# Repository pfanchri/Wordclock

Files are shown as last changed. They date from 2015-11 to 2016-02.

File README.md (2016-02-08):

# Wordclock
Mein Projekt für die DIY Vorlesung an der FAU Erlangen

Ziel des Projektes war es eine Wordclock zu erstellen, die kleiner als alle gewöhnlichen Wordclocks ist und als Tischuhr 
fungieren soll. Als Vorbild diente das Modell von qlocktwo. 

Die Uhr kann nicht nur die Zeit anzeigen, sonder speichert auch den Wochentag, dieser wird in der aktuellen Softwareversion 
aber noch nicht angezeigt. Weitere Verbesserungen sind etwa ein Batteriebuffer und weitere Möglichkeiten für die Frontplatte.

Bei der Vorlesung DIY gab es auch ein Wiki für alle Projekte. Das Wordlcock-Projekt ist unter folgendem Link zu finden: 
http://faui7pi.informatik.uni-erlangen.de/mediawiki/index.php/Wordclock

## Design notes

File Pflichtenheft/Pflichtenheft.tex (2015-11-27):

\documentclass[11pt,a4paper,ngerman]{article}
 \usepackage[utf8]{inputenc} %UTF8 input file
\usepackage[T1]{fontenc} 
\usepackage[ngerman]{babel} %Umlaute,Silbentrennung 
%\usepackage{textcomp} % Zusatzpaket textcomp - damit werden einige Sonderzeichen, insbesondere das Euro-Symbolaktiviert. Änderungen siehe Beispieltext.
\usepackage{hyperref} %URLs können eingefügt werden
\usepackage{booktabs} %Tabellen 
\usepackage{pdflscape} % Paket lscape (oder für pdflatex das Paket pdflscape)
\usepackage{cite} %zum verwenden von BibTex
\date{\today}
\author{Christof Pfannenmüller}
\title{DIY: Pflichtenheft Wordclock}
\begin{document}
\maketitle 
\tableofcontents 
\newpage
\section{Über dieses Dokument}
Um die Entwicklung meiner Wordclock etwas zu ordnen möchte in diesem Dokument das Erstellen und die Aufgaben dabei etwas sortiert aufführen. Das gesamte Projekt wurde auf Github\cite{githubWC} und im Wiki der Vorlesung DIY: Personal Fabrication\cite{wikiWC}  dokumentiert und 
\section{Lastenheft}
{\large Hier habe ich das bereits erstellte Lastenheft eingefügt.  }\\
Lastenheft Wordclock:\\
\\ 
Weckfunktion: vorsehen einer Weckfunktion mit Ton und Snoozefunktion\\
\\
Taster zum Ausschalten der Alarmfunktion, Snozze und zum Einstellen der Uhrzeit\\
\\
Helligkeitsanpassung: über Sensor oder über Software und Schalter an der Rückseite\\
\\
Sekundenanzeige\\
\\
Datum und Wochentag anzeigen\\ 
\\
Funkanbindung zum automatischen Uhrzeit einstellen\\
\\
Stromreserve: Uhrzeit bleibt bestehen bei Stromausfall  evtl. auch Anzeige und Weckfunktion ohne Strom\\ 
\\
Ausschalter: kleinen Ausschalter an der Unterseite zum gänzlichen Ausschalten (Uhrzeit läuft über Batterie weiter\\
\\
USB Versorgung\\
\\
24h Modus: Wecker klingelt nur alle 24h nicht alle 12 und die Weckfunktion kann somit angelassene werden\\
\\
verschiedene Frontcovers möglich: in verschiedenen Sprachen, dafür verschiedene Möglichkeiten der LED Ansteuerung\\
\\
Stabiles Gehäuse, schön klein\\
\\
Standfuß (standsicher)\\
Weiter Ideen für später: \par
Beschriftung auf der Rückseite, evtl  noch Schriftzug Wordclock oder CC Zeichen (oder beides)

\begin{landscape}
\section{Pflichtenheft}
\begin{tabular}[]{p{2cm}p{2cm}p{10cm}p{2cm}p{2cm}}
	\toprule
	Aufgabe & Beschreibung & Wie umzusetzen  & bis & Status \\
	\midrule
	Weckfunktion & & Lautsprecher/Tongeber, Taster für Snoozefunktion & & \\
	Weckzeitpunkt einstellen & & mehrere Taster, mind. 2 (Mode, Up) besser 3 (Mode, Up, Down); Mode kurz drücken zeigt aktuellen Weckzeitpunkt an, lange drücken um in Modus Weckzeitpunkt kommen; Unterscheidungsmöglichkeit AM/PM notwendig \\
	Uhrzeit einstellen & & Taster Up (Down) von Weckzeitpunkt verwenden; eigenen Taster um in Modus Uhrzeit einstellen zu kommen, oder mehrere Taster gleichzeitig drücken; wen gewünscht Möglichkeit für Datum einstellen (daraus Wochentag berechnen) \\
	Anpassung der Helligkeit & Anzeige heller bei heller Umgebung & Sensor für Umgebungslicht mit passender Elektronik; Loch in Gehäuse; Regelung der LEDs durch PWM (kompliziert) evtl. Controller oder durch IC (dafür ADU notwendig) \\
	Sekunden-Anzeige & zeigt Sekunden auf der Matrix an & Knopf durch den in Sekundenmodus gewechselt wird; Anzeige der Sekunden auf der Matrix, evtl. nicht bei jedem Frontcover möglich (muss deaktiviert werden können); wo Sekunden gespeichert? \\
	Anzeige Datum und Wochentag & & Wie anzeigen? Wo gespeichert? evtl. nicht bei jedem Frontcover möglich (muss deaktiviert werden können) \\
	Funkuhr & Einstellen der Uhrzeit nach Atomuhr & DCF77 Verbindung um Uhrzeit automatisch zu finden und einzustellen.\\
	Stromreserve & & Uhrzeit bleibt erhalten und Wecker klingelt trotz fehlendem Strom; Anzeige trotzdem aktiv würde Speicherdauer verkürzen ( Anzeige nur im Moment des Weckens oder gar nicht)\\
\end{tabular}
	%Seitenumbruch in Tabelle (besser lösen?)
	\newpage
	\begin{tabular}[]{p{2cm}p{2cm}p{10cm}p{2cm}p{2cm}}
	\toprule
	Aufgabe & Beschreibung & Wie umzusetzen  & bis & Status \\
	\midrule
	Uhr komplett ausschalten && Uhr über kleinen Schalter komplett ausschalten; Taster an Unterseite oder hinter Frontcover verstecken (bleibt Uhrzeit und Einstellungen erhalten?)\\
	Stromversorgung && Uhr wird über USB-Netzteil versorgt; USB Buchse verbauen \\
	24h Modus && Wecker klingelt nur um 6:00am, Uhr zeigt aber gleiches an für am/pm\\
	verschiedene Frontcovers & & Frontcover auswechselbar; verschiedene Farben möglich (evtl. bei Farben aktuelle Uhrzeit unterschiedlich gut erkennbar); verschiedene Sprachen (Umschalten der Matrix auf andere Sprache muss möglich sein, dafür Taster etc.)\\
	Stabiles Gehäuse & & Gehäuse mit sicherem Stand; stabil um nicht kaputt zu gehen (herunterfallen); vorerst aus Holz später Alu etc (aus einem Teil)\\
	Programmieren der Uhr && Schnittstelle um Uhr auch später noch programmieren zu können; an Unterseite oder hinter Frontplatte verstecken\\
	LED Helligkeit && LEDs passen Helligkeit an Umgebungslicht an; LEDs nachts austom. aus (24h Zeiteingabe (8-20Uhr: hell, 20-8Uhr: dunkel))

\end{tabular}
\end{landscape}

\section{Umsetzung}
	Der Aufbau der Wordclock soll von vorne nach hinten und von außen nach innen erfolgen:\\
	Ich möchte zuerst die Größe der Frontplatte festlegen, dann ein entsprechendes CAD Modell erstellen und die Schaltung intern auf einer einzelnen Platine unterbringen, da dies den Verdrahtungsaufwand verringert. Das Gehäuse möchte ich zuerst nur aus Holz bauen bzw. am 3D-Drucker ausdrucken und dies aber so, dass es möglich ist zu späteren Zeitpunkten ein Gehäuse aus Aluminium oder Holz zu fräsen. \par
	Ich möchte nicht nur selbstgestaltete Frontplatten verwenden können, sonder auch solche des Herstellers qlocktwo. Dadurch bin ich zwar an die genaue Größe der Frontplatte gebunden, kann aber auf die vielen verschiedenen Sprachen und Farben des Herstellers zugreifen. \par

\subsection{Frontplatte}
Für die Frontplatte möchte ich mehrere Sprachen machen, auf jeden Fall Deutsch und Englisch so wie nach Möglichkeit ein Dialekt (vorzugsweise Fränkisch)\\
Auflistung aller Sprachen TODO!!
Im Internet habe ich eine gute Lösung zu Befestigung gefunden: Die Frontplatte ist mit vier Magneten beklebt und  wird von vier weiteren Magneten an der Zwischenplatte gehalten und kann also ausgetauscht werden. Verbesserung: nur vier Magneten an Zwischenplatte, dafür Metall an Frontplatte
\subsection{Gehäuse}
stabil
Frontmaße identisch mit der der Frontplatte, Tiefe möglichst gering 
Möglichkeit Platine, Zwischenplatte und Frontplatte zu befestigen
Anschluss für USB und Löcher für Taster
\subsection{Zwischenplatte}
Die Zwischenplatte dient dazu, dass jede LED nur das für sie vorgesehene Zeichen auf der Frontplatte erleuchtet. Auch muss die Frontplatte durch die Zwischenplatte gehalten werden. Dafür möchte ich, wie in den meisten Wordclock-Ideen Magnete verwenden, da somit ein leichtes Auswechseln der Frontplatte möglich ist. Auch eine Verbindung zum Gehäuse muss durch die Frontplatte realisiert werden. Da die gesamte Schaltung nach Möglichkeit auf einer Platine realisiert werden soll werden wohl auch andere Bauelemente außer den LEDs auf der Vorderseite platziert werden müssen. Dafür ist es notwendig Aussparungen vorzusehen.  
Da es bei manchen Frontplatten Zeichen gibt, die größer sind und somit von mehreren LEDs angeleuchtet werden sollten, sollten die Zwischenstege der einzelnen LEDs möglichst dünn sein, um nicht einen Schatten zu werfen. Sie dürfen aber auch nicht zu dünn und somit evtl. durchscheinend sein. Möglichkeit: Kegelförmig zulaufend, ähnlich dem Abstrahlkegel der LEDs (wie zu Drucken/herzustellen)
Die Dicke der Zwischenplatte ergibt sich aus dem Abstrahlwinkel der LEDs, dieser ist bei fasst allen LEDs die für mich in Frage kamen 120 Grad Für die Dicke der Zwischenplatte ergibt sich damit: $d = \frac{0,5 * Buchstabendurchmesser}{tan60^\circ } $ 
\subsection{Platine}
\subsubsection{LEDs}
Ich möchte keine farbige Wordclock und benötige deshalb keine RGB-LEDs. \\
\begin{itemize}
\item klein
\item weiß (neutralweiß) 
\item hell
\item Abstrahlwinkel möglichst groß, damit Platine näher an Frontplatte kann insg. Uhr dünner wird
\item kostengünstig
\item möglichst geringer Stromverbrauch
\end{itemize}
Eierlegende Wollmilchsau, also Kompromiss finden\\
Suche im Reichelt-Katalog
%Beziehungen Lichtstrom lichtfarbe abstahlwinkel  -------------------------------------------
Eine weitere Möglichkeit für die LEDs sind adressierbare LEDs, so wurde eine Steuerung über Schieberegister entfallen (Tipp von Jürgen)
\subsubsection{LED-Verdrahtung}
Für die LEDs stellt sich die Frage nach einer Matrix- oder Einzelansteuerung. Die folgende Tabelle soll die Vor- und Nachteile der beiden Methoden darstellen:\\
\begin{tabular}[]{p{3cm}p{3cm}p{3cm}p{3cm}}
	\toprule
	Vorteile Matrix & Nachteile Matrix & Vorteile Einzelansteuerung  & Nachteile Einzelansteuerung\\
	\midrule
	stromsparend & immer nur eine LED an; nicht so hell & Alle LEDs an; hell & Stromverbrauch größer\\
	&Controller muss öfter aufwachen & lange Sleepzeiten des IC\\
	Dimmen über IC gleich integrierbar & Dimmen über abändern der Zeiträume die einzelne LED leuchtet & gemeinsammes Dimmen über Anode/Kathode aller LEDs & LEDs nicht unterschiedlich dimmbar
\end{tabular}
Der Verdrahtungsaufwand der beiden Methoden ist nahezu identisch, da ich die Schaltung auf einer einzige Platine unterbringen will.\\
Beim betrachten der Ansteuerzeiten für eine Einzelansteuerung fällt mir auf:\\
Gesamtzeit für einen Durchlauf aller LEDs muss kleiner als $1\over30$ einer Sekunde sein (damit kein Flackern sichtbar; vgl. Film). Also Zeit für eine LED bei 100\% Helligkeit: $\frac{1}{10*11*30} = \frac{1}{3300}=0,303ms$.Jetzt würde sich die Zeit durch Dimmen noch weiter verkürzen, was sehr kompliziert würde. Deswegen ist eine Einzelansteuerung und Dimmen aller LEDs über verbundene Anode/Kathode meine Meinung nach einfacher.\\
Ansteuern der LEDs über Schieberegister (kaskadierbar, benötigt also nur wenige Anschlüsse des IC) oder über LED-Treiber (eingebaute Möglischkeit des Dimmens; unabhänig von einander dimmbar; Ansteuerung über I2C)

\subsubsection{Ansteuerung}
Nach Möglichkeit SMD Bauteile verwenden, damit die Ansteuerung gut auf der Platine unterzubringen ist, trotzdem groß genug, damit es gut lötbar ist. So klein wie möglich so groß wie nötig.
\paragraph{Uhrzeit}

Viele Wordclocks verwenden ein RTC (Real Time Clock), beim Suchen habe ich eine gefunden, welche die Möglichkeit hat einen Alarm als Interrupt auszugeben(\url{http://www.reichelt.de/Real-Time-Clock/DS-1337/3/index.html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}), somit kann der Mikrocontroller die ganze Zeit im Schlafmodus sein und spart Strom. Zu Beginn kann man auch eine if-Abfrage verwenden, jedes mal, wenn die Uhrzeit geändert wird ob nun ein Alarm ausgegeben werden muss. Möglicherweise muss auch das Umschalten der LEDs immer auf einen Interrupt der RTC geschehen (wie weiß der Mikrocontroller sonst, dass eine Minute vorbei ist?)

\paragraph{Dimmen}
Helligkeit über PWM Controller anpassen wie?
LDR für Helligkeitsanpassung? evtl. kombinieren in gemeinsamer Ansteuerung, sodass IC auf volle Leistung aussteuern kann
Da sehr aufwändig und erstmal nicht so interessant auf unbestimmte Zeit verschoben
\paragraph{Taster und Schalter}
Es werden mehrere Taster gebraucht. Es werden vier Taster für die Uhr benötigt um: Ein Modustaster, ein Up- sowie ein Down-Taster und ein noch ein weiterer Taster um den Alarm an und auszuschalten. Die Snooze-Funktion sollte einen einen eigenen Taster bekommen, der größer ist oder leichter erreicht wird. Somit kann sichergestellt werden, dass ein schlaftrunkener Benutzer nicht die Weckfunktion komplett ausschaltet, statt den Snooze-Taster zu drücken.

Idee: alle Taster an Rückseite gehen auf einen interruptanschluss und jeder zusätzlich auf einen anderen Digitalanschluss, damit Interrupspins sparen; muss über Optokopler ??
\subsubsection{Stromversorgung}
USB evtl. Lightningstecker als Anschluss       
Handyakku?USB Puffern\cite{RTCDatenblatt}

\bibliography{Wordclock-Bibliographie} %hier steht der Name der Bib-Datei
\bibliographystyle{acm}  %Citationsstil "ieeetran" geht nicht; warum?

\end{document}

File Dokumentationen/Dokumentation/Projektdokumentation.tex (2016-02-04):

\documentclass[12pt,journal,compsoc]{IEEEtran}
\usepackage[utf8]{inputenc}
\usepackage[ngerman]{babel}
%\usepackage{tikz, tikzscale, adjustbox,enumerate, tabularx, multirow, booktabs}
\usepackage{graphicx, tabularx, booktabs, enumerate, multirow}
\usepackage{cite, textcomp}
\usepackage{hyperref}

\usepackage{listings}
\lstset{
  language=C,
  basicstyle=\ttfamily\small,
  keywordstyle=\color{blue}\ttfamily,
  stringstyle=\color{red}\ttfamily,
  commentstyle=\color{green}\ttfamily\normalsize,
  breakatwhitespace=false,
  breaklines=true
}

\makeatletter
{\obeylines\gdef\bt@eol{^^M}}
\newenvironment{breakabletexttt}
  {\ttfamily\hfuzz=0.4em
   \list{}{\leftmargin=2em
           \itemindent=-\leftmargin
           \listparindent=-\leftmargin
           \parsep=0pt}
   \item\relax\obeylines\obeyspaces\expandafter\breakable@texttt\@gobble}
  {\endlist}
\def\breakable@texttt{\futurelet\@let@token\breakable@texttti}
\def\breakable@texttti#1{%
  \ifx\@let@token\end
  \expandafter\end
  \else
    \expandafter\ifx\bt@eol\@let@token
      \par
    \else
      \string#1\hskip1sp
    \fi
    \expandafter\breakable@texttt
  \fi}
\makeatother

\usepackage{tikz, tikzscale} % tiks für Zeichnungen

\usepackage[europeanresistors,europeaninductors,arrowmos]{circuitikz}
\usepackage{amsmath}

%\usepackage[siunitx]{circuitikz}
%\usepackage[ngerman]{varioref}% Definiert variable Referenzierungen
%\usetikzlibrary{dsp,chains}

\providecommand{\PSforPDF}[1]{#1}
\setcounter{secnumdepth}{1}

% NOTE: PDF hyperlink and bookmark features are not required in IEEE
%       papers and their use requires extra complexity and work.
% *** IF USING HYPERREF BE SURE AND CHANGE THE EXAMPLE PDF ***
% *** TITLE/SUBJECT/AUTHOR/KEYWORDS INFO BELOW!!           ***
\newcommand\MYhyperrefoptions{bookmarks=true,bookmarksnumbered=true,
pdfpagemode={UseOutlines},plainpages=false,pdfpagelabels=true,
colorlinks=true,linkcolor={black},citecolor={black},pagecolor={black},
urlcolor={black},

pdftitle={DIY Wordclock},
pdfsubject={Wordclock},
pdfauthor={Christof Pfannenmüller}}

% correct bad hyphenation here
%\hyphenation{op-tical net-works semi-conduc-tor}

\begin{document} %----------------------------------------------------------------------------Beginn des Dokuments
%
% paper title
% can use linebreaks \\ within to get better formatting as desired
\title{DIY Wordclock}

\author{Christof Pfannenmüller}% <-this % stops a space

  % for Computer Society papers, we must declare the abstract and index terms
  % PRIOR to the title within the \IEEEcompsoctitleabstractindextext IEEEtran
  % command as these need to go into the title area created by \maketitle.
%  \IEEEcompsoctitleabstractindextext{%
%  \begin{abstract}
  %\boldmath
  %The abstract goes here.
%  \end{abstract}
  % IEEEtran.cls defaults to using nonbold math in the Abstract.
  % This preserves the distinction between vectors and scalars. However,
  % if the journal you are submitting to favors bold math in the abstract,
  % then you can use LaTeX's standard command \boldmath at the very start
  % of the abstract to achieve this. Many IEEE journals frown on math
  % in the abstract anyway. In particular, the Computer Society does
  % not want either math or citations to appear in the abstract.

  % Note that keywords are not normally used for peerreview papers.
%  \begin{IEEEkeywords}
%  Computer Society, IEEEtran, journal, \LaTeX, paper, template.
%  \end{IEEEkeywords}}

% make the title area
\maketitle

% To allow for easy dual compilation without having to reenter the
% abstract/keywords data, the \IEEEcompsoctitleabstractindextext text will
% not be used in maketitle, but will appear (i.e., to be "transported")
% here as \IEEEdisplaynotcompsoctitleabstractindextext when compsoc mode
% is not selected <OR> if conference mode is selected - because compsoc
% conference papers position the abstract like regular (non-compsoc)
% papers do!
\IEEEdisplaynotcompsoctitleabstractindextext
% \IEEEdisplaynotcompsoctitleabstractindextext has no effect when using
% compsoc under a non-conference mode.

% For peer review papers, you can put extra information on the cover
% page as needed:
% \ifCLASSOPTIONpeerreview
% \begin{center} \bfseries EDICS Category: 3-BBND \end{center}
% \fi
%
% For peerreview papers, this IEEEtran command inserts a page break and
% creates the second title. It will be ignored for other modes.
%\IEEEpeerreviewmaketitle

%----------------------------------------------------------------------------------------------Beginn des  eigentlichen Textes

\section{Einführung}

\IEEEPARstart{W}{ordclocks} sind in der Bastler oder DIY-Szene weit verbreitet und bergen eine gewisse Faszination. Auch wenn es für solche Wordclocks schon eine Vielzahl an Bauanleitungen gibt, kann trotzdem beim Bau einer solchen viel über die Programmierung und die Steuerung durch Mikrocontroller gelernt werden.
Grundsätzlich sind alle Wordclocks sehr ähnlich aufgebaut. Fast immer wird eine Frontplatte mit passend angeordneten  Buchstaben verwendet, die durch eine Matrix an LEDs von hinten erleuchtet ist. Dadurch, dass nur die zur aktuellen Stunde passenden   Wörter leuchten, stechen diese aus den, auf den ersten Blick verwirrend angeordneten, Buchstaben der Frontplatte hervor. Wichtig bei einer Wordclock ist auch, dass jede LED nur den für sie vorgesehen Buchstaben der Frontplatte beleuchtet und nicht zu einem Teil auch die benachbarten Buchstaben. Dies würde den absetzenden Effekt des Hervorscheinens der Buchstaben von den dunkleren minimieren. Dafür wird meist eine sogenannte Zwischenplatte angebracht, die das Licht der LED abschirmt, damit sichergestellt werden kann, das kein Nachbarbuchstabe beleuchtet wird.
Wordclocks wurden bereits in vielen verschiedenen Sprachen erstellt, wobei  grundsätzlich jede Sprache möglich ist. Die einzige Vorgabe ist alle Wörter, die zum \glqq schreiben\grqq der Uhrzeit notwendig sind, auf der Frontplatte anzuordnen. Dabei ist jedoch wichtig, dass die Reihenfolge der Wörter so gewählt wird, das jede mögliche Uhrzeit auch dargestellt werden kann ohne ein Wort doppelt unterbringen zu müssen und trotzdem die Reihenfolge der Wörter dem Sprachgebrauch entspricht. In diesem Zusammenhang ist etwa die Darstellung der Zeit 15:45 interessant, denn je nach Wohnort wird diese in unterschiedlichem Wortlaut verwendet. Vor allem in Sachsen, Thüringen und Franken wird die Bezeichnung \glqq Dreiviertel vier\grqq verwendet, in Norddeutschland dagegen eher \glqq Viertel vor vier\grqq. Solche Feinheiten müssen also berücksichtigt werden, bei \glqq Viertel nach drei\grqq bzw. \glqq Viertel vier\grqq verhält es sich ähnlich.

\begin{figure}
	\centering
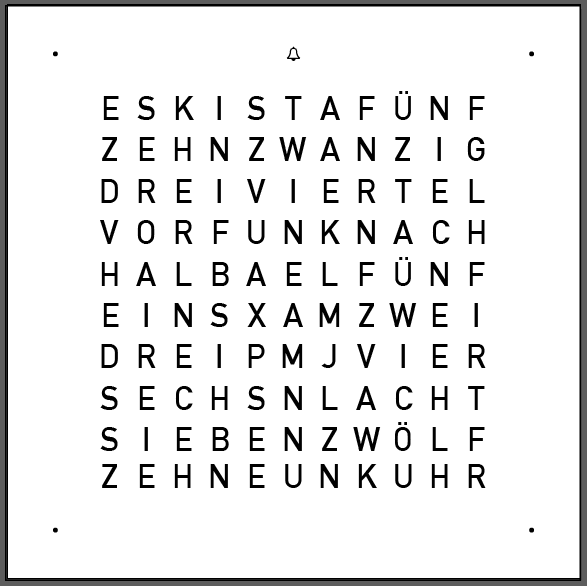
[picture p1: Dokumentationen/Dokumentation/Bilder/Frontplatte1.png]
	
	\caption{Die Frontplatte meiner Wordclock} 
	\label{fig:Frontplatte1}
\end{figure}

\section{Anforderungen}
Diese Wordclock sollte vor allem - im Gegensatz zu den meisten anderen - kleiner ausgelegt und nicht zum Aufhängen an der Wand gedacht sein, sondern als modulare kleine Tischuhr, die bei Einbau einer Alarmfunktion, auch als Wecker dienen kann.
Bei ersten Recherchen fand ich heraus, dass der Hersteller Qlocktwo mittlerweile eine solche Uhr in seinem Sortiment hat. Qlocktwo ist allem Anschein nach der einzige Hersteller von Wordclocks auf dem Europäischen Markt. Da der Hersteller auch Ersatzfrontplatten verkauft, entschied ich mich zuerst eine solche zu kaufen und eine eigene Frontplatte erst zum Schluss zu erstellen, wenn die Wordclock bereits funktionsfähig ist. Dadurch musste ich zwar die geplante Größe der Wordclock um ein paar Zentimeter auf 13,5cm Seitenlänge verkleinern, konnte mich aber erst einmal auf die Elektronik konzentrieren.
Um zunächst einen Überblick zu bekommen sammelte ich alle möglichen Projektideen und mögliche Umsetzungen in einem, mit Latex erstellten, Lasten- und Pflichtenheft. Dabei wurde auch die in Latex integrierte Bibliographieverwaltung verwendet um alle Quellen für Ideen zu archivieren. Zur Versionskontrolle wurde während des Projektes für alle Dateien Github eingesetzt um jeweils den aktuellen Stand zu protokollieren. Das fertige Github-Repository ist unter der \url{https://github.com/pfanchri/Wordclock} zu finden.

\section{Hardware}

\subsection{Eagle}
Für die Platine wird Eagle als PCB-Software zum Entwurf der Platine verwendet, da es kostenlos verwendet werden kann und die Platinenentwicklung im Fablab auf Eagle ausgerichtet ist. Eagle arbeitet nach dem Bibliotheks-Prinzip, das heißt es werden für jedes  Bauteil Daten über die Elektrischen Anschlüsse und über das Package, also über die Verpackung des Bauteils, benötigt. In Eagle können somit  zuerst der Schaltplan, also die elektrischen Verbindungen und Netze, erstellt werden. Diese werden in einem zweiten Schritt auf der Platine angeordnet und die Leiterbahnen geroutet. Hier kann leicht berücksichtigt werden, dass viele elektrische Bauteile in unterschiedlichen Packages zur Verfügung stehen. Die bei der Wordclock verwendeten Bauteile waren zumeist in den mit Eagle ausgelieferten Bibliotheken bereits enthalten. Die Bibliotheksdaten für die LEDs waren zwar nicht in den Standartbibliotheken enthalten, werden dafür aber von Adafruit, einem Händler für diese Bauteile, bereitgestellt. Im Layout wurden zuerst alle LEDs an die durch die Frontplatte vorgegebenen stellen platziert. Anschließend wurden die Taster angeordnet, sodass diese später optisch ansprechend platziert sind. Alle in der fertigen Wordclock nicht mehr sichtbaren Bauteile wurden als letztes platziert und mit Leiterbahnen versehen. Eagle konnte auch eingesetzt werden, um etwa eine Stückliste der verwendeten Teile auszugeben.
\begin{figure}
	\centering
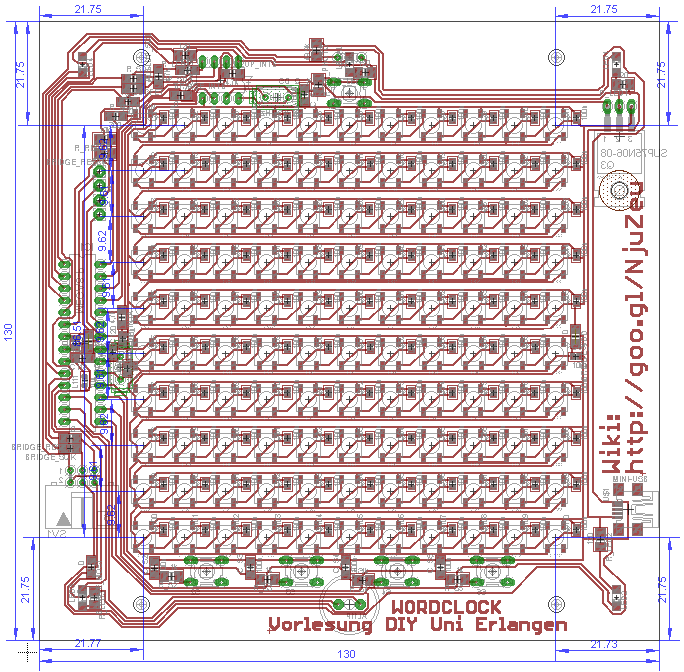
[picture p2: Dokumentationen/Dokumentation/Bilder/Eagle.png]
	
	\caption{Das Layout in Eagle} 
	\label{fig:EagleL}
\end{figure}

\subsection{Elektronik}
Das Ziel ist die Platine einlagig aufzubauen. Dies erhöht zwar den Aufwand für das Layout immens, dafür kann aber eine einlagige Platine verwendet werden, die wesentlich einfacher zu entwickeln ist, als eine zweilagige. Auch werden keine Durchkontaktierungen in der Platine benötigt, die im Fablab etwas aufwändiger sind. Da der Platz aber durch die Vorgabe der Frontplatte begrenzt ist, müssen auch kleine Bauteile verwendet werden, die etwas schwieriger zu löten sind.
Versorgt werden soll die Uhr mittels Strom aus einem USB-Ladegerät oder Computer damit kein besonderes Ladegerät notwenig ist. Dies legt die Versorgungsspannung auf 5 Volt fest. Als Stromanschluss wird eine kombinierte Micro-USB-Buchse, die für Stecker des Types A und B geeignet ist, verwendet. Die Uhr kann dadurch mit einem Ladekabel für Handys betrieben werden.
Die Hauptarbeit übernimmt dabei ein Prozessor der  Mega8-Reihe von Atmel, da dieser einfach zu programmieren und leicht verfügbar ist. Genau wird der Atmega168PA-PU verwendet, der den größten programmierbaren Flash seiner Baureihe zur Verfügung stellt. Da ein späterer Einbau einer Batteriepufferung möglich sein soll, verwenden wir hier die Pico-Power Ausführung des AVR, da diese weniger Strom im Schlafmodus verbraucht, was hierbei hilfreich sein kann. Als Baugröße verwende ich hierbei die PDIP  Ausführung . Da bei diesem Gehäuse die Pins nahe beieinander liegen, kann der AVR gut zwischen der LED-Matrix und dem Rand der Platine eingebaut werden. Hierfür wäre eine andere Gehäuseform zu groß. Zum Programmieren des AVR wird eine Standart ISP-Stecker verwendet, da bereits damit zu rechen ist, das die Software mehrfach aufgespielt werden muss, bis diese reibungslos läuft. 
Die LED-Matrix zum Anzeigen der einzelnen Buchstaben der Uhr wird durch 110 WS2812B LEDs aufgebaut. Diese LEDs haben den Vorteil, dass sie eine eigene Datenleitung haben und der Mikrocontroller daher nur einen Pin bereitstellen muss, um alle hundertzehn Buchstaben ansteuern zu können. Dies funktioniert, indem ein, in die LED eingebauter Chip, dieses Datensignal empfängt und über den Data-Out-Pin der LED die folgenden LEDs mit dem Datensignal versorgt. Alle drei Grundfarben können durch den Chip in 255 Stufen bei den LEDs getrennt geregelt werden. Damit kann also mit jedem der 110 Buchstaben das gesamte Farbspekrum von 16777216 verschiedenen Farben dargestellt werden. Dem Datenblatt der WS2812B zufolge sollte bei jeder WS2812B ein Kondensator mit 100nF zwischen Versorgungsspannung und Ground im Layout eingebaut werden. Dies dient dazu die Versorgungsspannung der  LED zu stabilisieren und somit sicherzustellen, das die Ansteuerung richtig funktioniert. Da für die Versorgung des eingebauten Steuerchips der WS2812B auch im ausgeschalteten Zustand Strom benötigt wird, kann die Gesamte Matrix über einen P-Kanal-Mosfet von der Versorgungsspannung getrennt werden.Für die LEDs, welche die einzelnen Minuten und den Alarm anzeigen, werden dagegen \glqq normale\grqq LEDs verwendet, deren Kathode vom Mikrocontroller auf Ground gezogen werden können und damit angeschaltet werden. Um keine ungewollten Aktionen beim Programmieren des Atmega auszulösen werden die LEDs auf die selben Pins des Mikrocontroller gelegt, die auch als Verbindung zum In-System-Programmer dienen. Beim Programmieren des AVR kann es also nun vorkommen, dass  die LEDs aktiviert werden, es kann jedoch kein Schaden an Bauteilen erzeugt werden, obwohl diese Pins doppelt genutzt werden.
Die Uhrzeit soll sowohl im Mikrocontroller selbst als auch in einem externen Realtime-Clock-Baustein gezählt werden können. Der externe Baustein hat hierbei wieder die Vorteile, dass der Atmega168 im Schlafmodus sein kann und somit wenig Strom benötigt wird. Als Clock-Baustein wird hierfür ein DS1337 verwendet, da dieser zwei externe Interrupt Kanäle besitzt und somit den Mikrocontroller durch einen Alarm aus dem Schlafmodus aufwecken kann. Die Real-Time-Clock wird vom AVR über das Two-Wire Protokoll angesteuert werden.
Für das Einstellen der Uhrzeit und das Nutzen anderer Funktionen, wie etwa eines Alarms, wurden fünf Taster verbaut. Alle diese sind mit einem Kondensator entprellt und jeder Taster ist am AVR angeschlossen, sodass ein Tastendruck mit einem Pin-Change-Interrup detektiert werden kann. 
Außerdem wurde ein LDR (Light Dependent Resistor) also ein lichtabhäniger Widerstand eingebaut. Somit kann zu einem späteren Zeitpunkt die Helligkeit der Matrix in Abhängigkeit von der Umgebungshelligkeit gesteuert werden. So wird sichergestellt, dass die LEDs niemals blenden, was vor allem für den Einsatz als Wecker wichtig ist, aber diese auch zu jeder Tageszeit gut erkennbar sind.
Damit die Uhr auch in der Lage ist ihre Benutzer zu wecken, wurde ein Signalgeber eingebaut, der über einen internen Generator verfügt und somit nicht mit einer Sinusschwingung angeregt werden muss, sondern nur durch anklemmen an die 5V Versorgungsspannung aktiviert werden kann. Dies ist durch den Mikrocontroller wesentlich leichter zu realisieren.
Die zwei nicht verwendenten Pins des Atmega wurden auf ein Via an einer freien Stelle der Leiterplatte gelegt, außerdem wurde hier noch ein Via für Ground und +5 Volt eingefügt. Somit kann hier zu einem späteren Zeitpunkt auf einfache Weise eine Lösung zur Spannungsversorgung aus einer Batterie einbaut werden. Diese könnte sogar mit dem AVR kommunizieren und die Wordclock könnte dadurch in einen stromsparenderen Modus wechseln.  

\subsection{Gehäuse}
Um das Gehäuse der Wordclock planen zu können, erstellte ich zuerst ein CAD-Modell. Als Programm wurde dafür SolidWorks verwendet. Dies wurde auch vor dem Hintergrund gemacht, damit aus den in Solid Works erstellten Dateien beispielsweise die Schnittmuster für die Zwischenplatte extrahiert werden können. Da Eagle die Möglichkeit besitzt, das Layout der Platine im Intermediate Data Format  (IDF) zu exportieren, welches für den Austausch von Layout und CAD-Programmen gedacht ist, konnte damit in SolidWorks ein genaues 3D Modell der Platine erstellt werden. Die einzelnen CAD-Modelle der elektrischen Bauteile dafür sind im Internet zu finden. Somit konnte, aufbauend auf die Platine mit den angebrachten Bauteilen, ein gutes Gehäuse geplant und modeliert werden. 
\begin{figure}[h]
	\centering
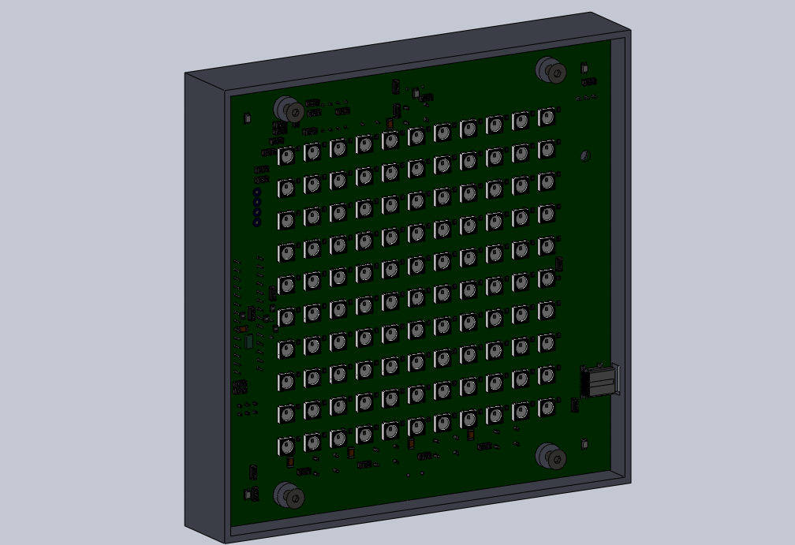
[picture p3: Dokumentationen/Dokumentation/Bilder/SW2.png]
	
	\caption{Das erstellte Modell mit der eingebauter Elektronik} 
	\label{fig:SW2}
\end{figure}
Für den Prototyp wurde das Gehäuse mit dem Onlinetool \glqq Boxmaker\grqq aus Akryl ausgelasert. Die Zwischenplatte, die dazu dient die einzelnen LEDs gegeneinander abzuschirmen wurde ebenfalls zuerst in SolidWorks erstellt und anschließend mit dem Lasercutter aus einer MDF Platte.
Die Dicke der Zwischenplatte ergibt sich aus dem Abstrahlwinkel der LEDs, dieser beträgt bei den WS2812B 120°. Für die Dicke der Zwischenplatte ergibt sich also mit einer Buchstabengröße von etwa 8mm: 
\begin{equation}
d = \frac{\frac{1}{2} * Buchstabendurchmesser}{tan\frac{120^\circ }{2}}= 4,62
\end{equation}
Aus diesem Grund wurde eine Dicke von 5mm für die Zwischenplatte gewählt.
Zusammengehalten wird die gesamte Uhr von vier M3 Schrauben, welche die Platine, die Zwischenplatte und das Gehäuse mit Abstandshalter fixieren, damit diese nicht verrutschen.
\begin{figure}[h]
	\centering
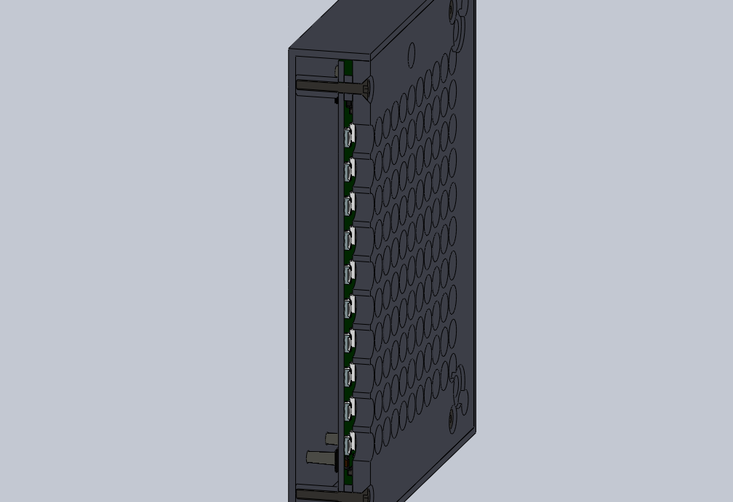
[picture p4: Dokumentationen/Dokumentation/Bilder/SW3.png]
	
	\caption{Schnitt durch das in SolidWorks erstellte Modell} 
	\label{fig:SW3}
\end{figure}

\subsection{Frontplatten}
Für die Frontplatte wurde die Anordnung der Buchstaben in einer Illustrator-Datei erstellt. Dabei wurden alle Buchstaben so angeordnet, dass diese exakt über das entsprechende Loch in der Zwischenplatte passen. Für die erste Anordnung der Buchstaben wurde das selbe Schema, welches auch bei der Qlocktwo und vielen weiteren Wordclocks im Internet zu finden ist, angewendet. Außerdem wurde eine Frontplatte erstellt, die es ermöglicht die Wordclock auch als Binäruhr zu verwenden. 
\begin{figure}[h]
	\centering
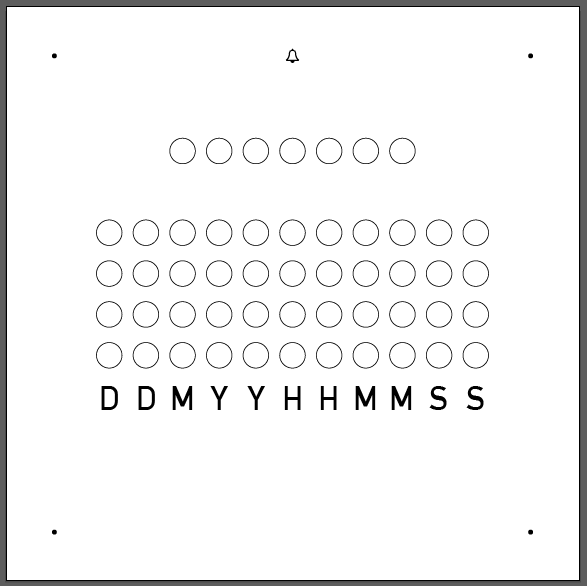
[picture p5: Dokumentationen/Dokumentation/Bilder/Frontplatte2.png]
	
	\caption{Eine Binäre Frontplatte für die Wordclock mit Anzeige für Wochentag (oben), Datum und Uhrzeit} 
	\label{fig:Frontplatte2}
\end{figure}
Hierfür muss nur die Software entsprechend angepasst werden. Da die Frontplatte idealerweise  nur an den Buchstaben das Licht durchlässt und dort leicht milchig sein sollte, gibt es  verschiedene Möglichkeiten zum Herstellen der Platte. Die simpelste Möglichkeit ist dabei, das Layout der Frontplatte auf mehrere Overheadfolien zu drucken und diese mit einem Blatt Papier als Diffusor gemeinsam zu laminieren. Problematisch ist hierbei allerdings die Verbindung der einzelnen Folien, da diese sich leicht lösen. Bei der binären Frontplatte wurden nur die Lichtdurchlässe aus der Holzplatte ausgeschnitten, die hierfür verwendet wurde. Diese wurden anschließend von hinten mit Papier verklebt, sodass die LEDs durch dieses diffus hindurchleuchten. Als aufwendigste Methode wurde  eine Akrylscheibe von hinten zuerst farbig und anschließend mehrfach schwarz lackiert. Aus dieser wurde das in Illustrator erstellte Frontplattenlayout dann ausgraviert. Die Schwarze Lackierung dient hierbei dazu, dass die LEDs nicht durch die farbigen Stellen der Frontplatte hindurch leuchten. Eine weitere, aber nicht erprobte Methode, wäre das Ausschneiden einer Folie mit dem im Fablab verfügbaren Folienplotter, diese wurde anschließend auf eine Milchglasscheibe geklebt. Alle Frontplatten sind mit einem Magnet an der Zwischenplatte befestigt, so wird kein Werkzeug zum Austauschen der Zwischenplatte benötigt.

\section{Software}
Die Software für den Atmega168 wurde in Eclipse entwickelt. Der wesentliche Teil der Software ist die Ansteuerung der Matrix aus 110 WS2812B LEDs. Diese funktioniert über ein spezielles Protokoll: die erste LED der Matrix bekommt einen Strom an Bits vom Mikrocontroller. Von diesem Bitstrom entfernt die erste LED die vordersten 24 Bit und gibt alle weiteren ankommenden Bits an die nächste LED weiter, die nach dem selben Prinzip verfährt. Somit erhält jede LED 24 bit, von denen jeweils 8 die Helligkeit der drei Farben Grün, Rot und Blau repräsentieren. Die 8 Bit kodieren dabei die Helligkeit der jeweiligen Farbe in 256 Stufen. Die Übertragung zu den WS2812B erfolgt durch ein unipolares Non-Return-To-Zero-Signal. Eine 1 wird dabei durch einen nur 0,2us längeren Impuls als eine 0 übertragen; Aus diesem Grund ist, die Ansteuerung sehr zeitkritisch und Interrupts sollten während des Senden an die LED-Matrix deaktiviert sein.
\begin{figure}[h]
	\centering
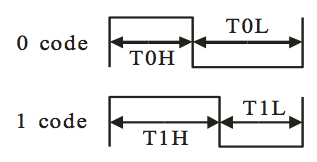
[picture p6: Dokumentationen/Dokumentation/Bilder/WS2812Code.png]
	
	\caption{Ausschnitt aus dem Datenblatt der WS2812B} 
	\label{fig:WS2812Code}
\end{figure}
Zur Ansteuerung wird die light\_ws2812 V2.3 von cpldcpu verwendet, die auf Github unter der GNU General Public License veröffentlicht ist. Diese Bibliothek übernimmt vom Hauptprogramm einen selbst definierten Datentyp, der für jede Farbe ein Array mit allen 110 LEDs der Matrix enthält. Den LEDs können  somit getrennte Helligkeitswerte zugewiesen werden. Um Probleme bei der Ansteuerung der letzten LED zu umgehen, wurde das Array jedoch um eines länger gewählt, als die Matrix eigentlich ist. Dies führt dazu, dass die letzte WS2812B noch immer Daten weiterreichen muss und somit die Wahrscheinlichkeit  durch einen Bitfehler eine falsche Helligkeit anzuzeigen sinkt.
Die  Verbindung zum DS1337 Bausteil erfolgt, wie bereits erwähnt über das Two-Wire-Interface und verwendet dabei die eingebaute Peripherie des AVR. Softwareseitig baut die Kommunikation auf einer Bibliothek auf, die eigentlich für den Bausteil DS1307 gedacht ist. Diese wurde von Davide Gironi  ebenfalls unter der GNU General Public License zur Verfügung gestellt. Da sich die beiden Bausteine in Ihren Registern für die Stunden, Minuten und Sekunden sowie denen für das Datum aber entsprechen, funktioniert diese Library auch um das Datum im DS1337 zu speichern und aus diesem auch zu lesen. 

\section{Ausblick}
Bisher noch nicht umgesetzt wurde die Einstellung der aktuellen Uhrzeit mit den fünf zur Verfügung stehenden Tastern. Dafür soll entweder die Möglichkeit des AVR genutzt werden einen Pin-change-Interrupt  bei einem Tastendruck zu generieren. Alternativ könnte in der Hauptschleife ständig abgefragt werden, ob die Taste gerade gedrückt wurde. In einer späteren Version der Wordclock wäre es auch noch wünschenswert, wenn die Taster  beschriften werden würden. Dies wäre auf dem Gehäuse ohne Probleme mit dem Lasercutter zu realisieren.
Da die Bibliothek für die Kommunikation mit der Realtime-Clock aktuell die Verwendung der im Baustein DS1337 verfügbaren Alarme nicht unterstützt müsste die Kommunikation noch um einige Funktionen erweitert werden, damit auch die Alarme des Bausteins genutzt werden können. Intern nutzt die Bibliothek für die Konfiguration der Uhr einige Funktionen zum Senden und Empfangen von Daten über das Two-Wire-Interface. Diese könnten sicher auch bei der weiteren Anpassung der Bibliothek an den DS1337 Baustein verwendet werden.
Weitere Features wie der Empfang der aktuellen Zeit über den Sender DCF77, also der Umbau zu einer Funkuhr wären ebenfalls leicht möglich. Dafür könnten die bereits erwähnten Durchkontaktierungen in der Platine und die beiden ungebelgten Pins des Atmega genutzt werden. Zwischen der Platine und der Rückwand des Gehäuses wäre auch noch genügend Luft vorhanden, in den ein solcher Empfänger eingebaut werden könnte. Alternativ kann hier aber auch eine Lösung gut untergebracht werden, die die Uhr zu einer batteriebetriebnen Wordclock erweitert. Der einfachste Weg dazu wäre, eine USB-Powerbank zu nutzen, da diese integriert bereits Elektrische Schaltungen zum Laden der Akkus und eine Spannungsstabilisierung auf die benötigten 5V hat.
Da die Buchstaben alle einzeln ansteuerbar sind, besteht auch die Möglichkeit die Matrix für noch weitere Anwendungen zu nutzen. Denn durch die vielen LEDs können auch Muster wie Kreise oder andere Formen auf der Matrix angezeigt werden. So kann etwa auch die Temperatur angezeigt werden oder alternativ das Datum oder der Wochentag. Dafür würden solche LEDs aktiviert, die zusammen den Umriss eines gewünschten Buchstaben oder einer Zahl bilden, der sich über die gesamte Matrix erstreckt.
\begin{figure}
	\centering
	
	\caption{Foto der fertigen Wordclock} 
	\label{fig:Foto}
\end{figure}
%----------------------------------------------------------------------------------------------Ende des eigentlichen Textes

\nocite{*}
%\begin{thebibliography}{1}
%\bibliography{literatur.bib}
%\bibliographystyle{plain}
%\bibitem{IEEEhowto:kopka}
%H.~Kopka and P.~W. Daly, \emph{A Guide to {\LaTeX}}, 3rd~ed.\hskip 1em plus
 % 0.5em minus 0.4em\relax Harlow, England: Addison-Wesley, 1999.

%\end{thebibliography}

% that's all folks
\end{document}

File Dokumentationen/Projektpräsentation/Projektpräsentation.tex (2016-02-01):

\documentclass{beamer}
\usepackage[T1]{fontenc} 
\usepackage[ngerman]{babel} %Umlaute,Silbentrennung
% \usepackage{beamerthemesplit} // Activate for custom appearance
 \usepackage[utf8]{inputenc} %UTF8 input file
\usepackage{cleveref}
\usepackage{textcomp}
\usepackage{multimedia}
\usepackage{graphicx}
\title{DIY Projektvortrag}
\author{Christof Pfannenmüller}
\date{\today}
\begin{document}

\frame{\titlepage} % -----------Anforderungen: 10 15 min 7 8 folien
\section[Outline]{}
\frame{\tableofcontents}

\section{mein Projekt}
\subsection{ \huge{ Wordclock auf einer Platine}}
\frame
{
  \frametitle{mein  Projekt}
{\Large Was soll\textbf{te} das Projekt enthalten?\\}\par 
\begin{itemize}
\item Wordclock
\item Möglichkeit mich aufzuwecken
\item klein genug für den Nachttisch -> max. 20cm
\item Stromreserve über die Nacht
\item viele viele verschiedene Sprachen
\end{itemize}
}

\frame
{
  \frametitle{mein  Workflow} 
  \begin{itemize}
\item Pflichten und Lastenheft
\item Layout in Eagle
\item CAD Modell
\item Frontplatte
\end{itemize}
} 

\frame
{
  \frametitle{Layout in Eagle}
   \begin{itemize}
\item möglichst universell
\item Größe des Vorbildes einhalten
\end{itemize}
} 

\frame
{
  \frametitle{Layout}
\begin{figure}[tb]
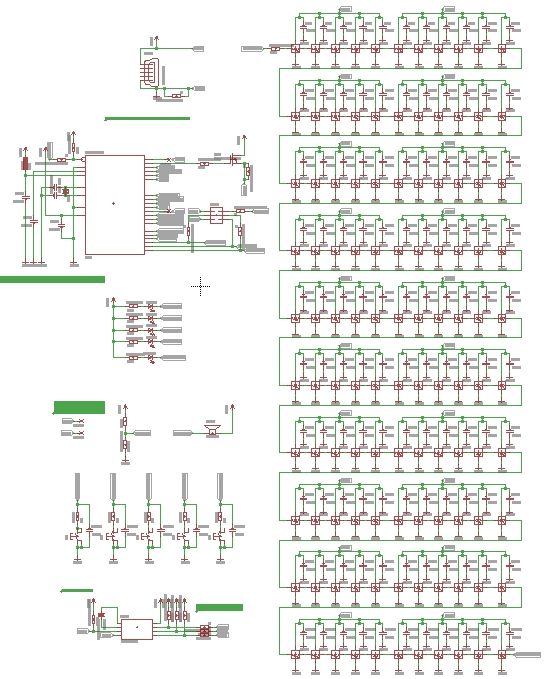
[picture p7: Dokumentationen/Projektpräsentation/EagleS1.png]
\centering  
\end{figure}
} 

\frame
{
  \frametitle{Layout}

\begin{figure}
     \centering
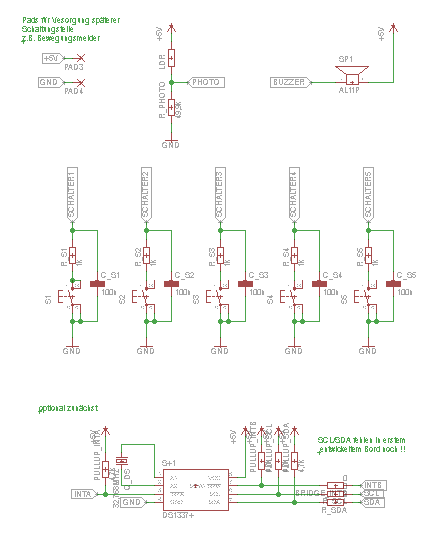
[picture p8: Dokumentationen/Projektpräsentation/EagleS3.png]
     
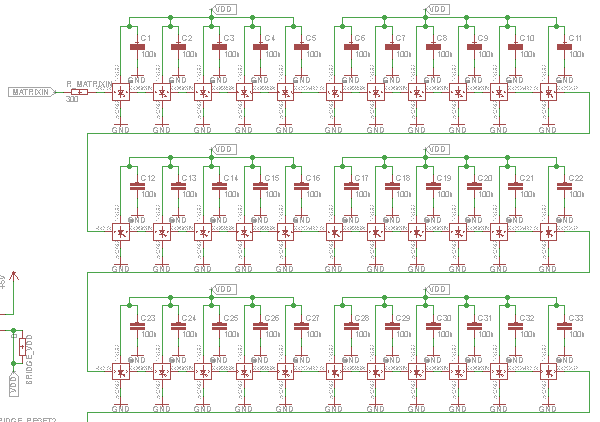
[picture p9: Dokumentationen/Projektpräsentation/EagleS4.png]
     
\end{figure}

} 
 
\frame
{
  \frametitle{Qlocktwo als Größenvorbild}
\begin{figure}[tb]
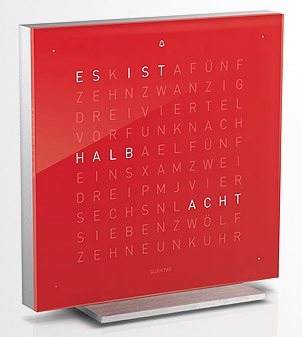
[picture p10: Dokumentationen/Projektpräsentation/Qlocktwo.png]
\centering  
\end{figure}
} 

 \frame{
  \frametitle{CAD Modell}
  \begin{figure}[tb]
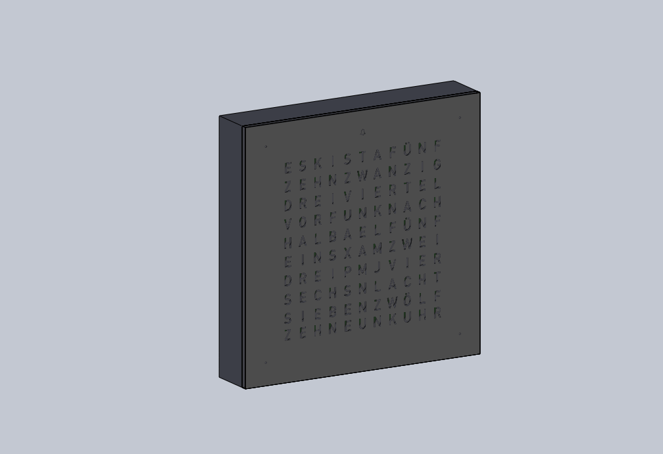
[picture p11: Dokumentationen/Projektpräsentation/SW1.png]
\centering  
\end{figure}
}

 \frame{
  \frametitle{CAD Modell}
  \begin{figure}[tb]
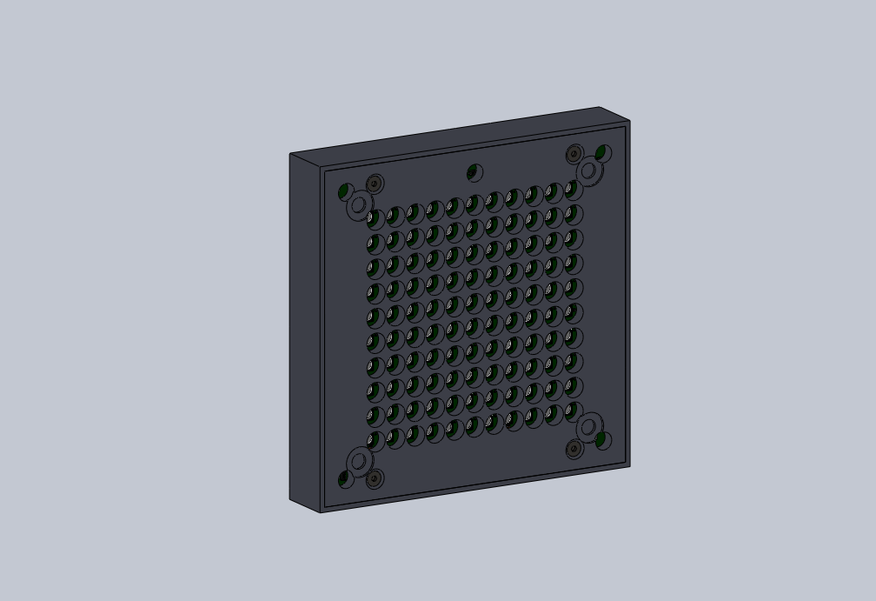
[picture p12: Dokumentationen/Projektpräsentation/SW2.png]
\centering  
\end{figure}
}

 \frame{
  \frametitle{CAD Modell}
  \begin{figure}[tb]
\centering  
\end{figure}
}

 \frame{
  \frametitle{CAD Modell}
  \begin{figure}[tb]
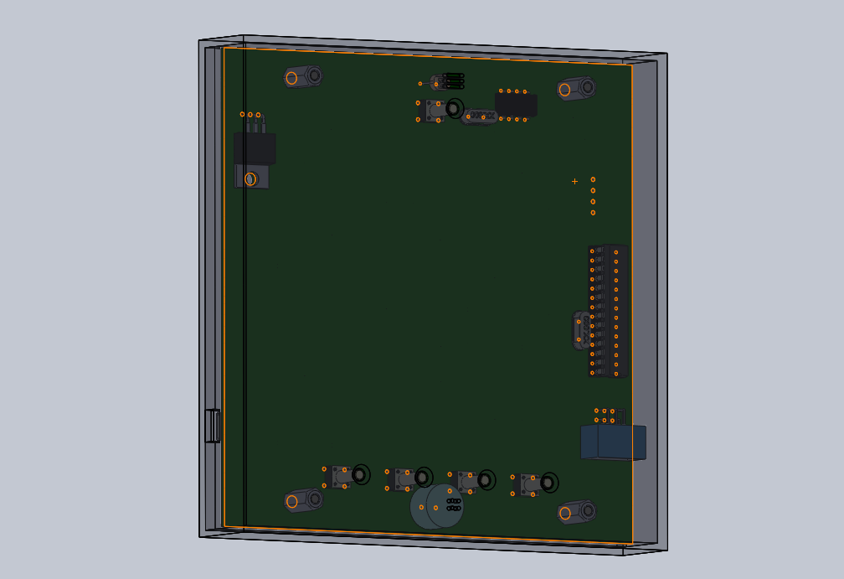
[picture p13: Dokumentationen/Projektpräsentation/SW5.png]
\centering  
\end{figure}
}
\frame{
  \frametitle{CAD Modell}
  \begin{figure}[tb]
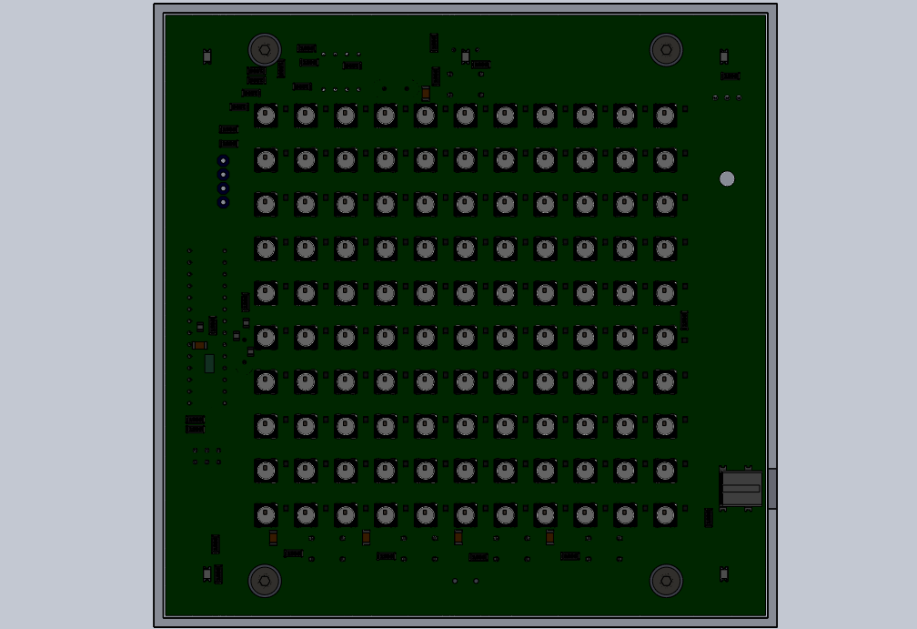
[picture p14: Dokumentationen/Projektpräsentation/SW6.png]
\centering  
\end{figure}
}
\frame{
  \frametitle{CAD Modell}
  \begin{figure}[tb]
\centering  
\end{figure}
}
 
 \frame
{
  \frametitle{Frontplatte}
  Anordnung der Buchstaben
  \begin{figure}
     \centering
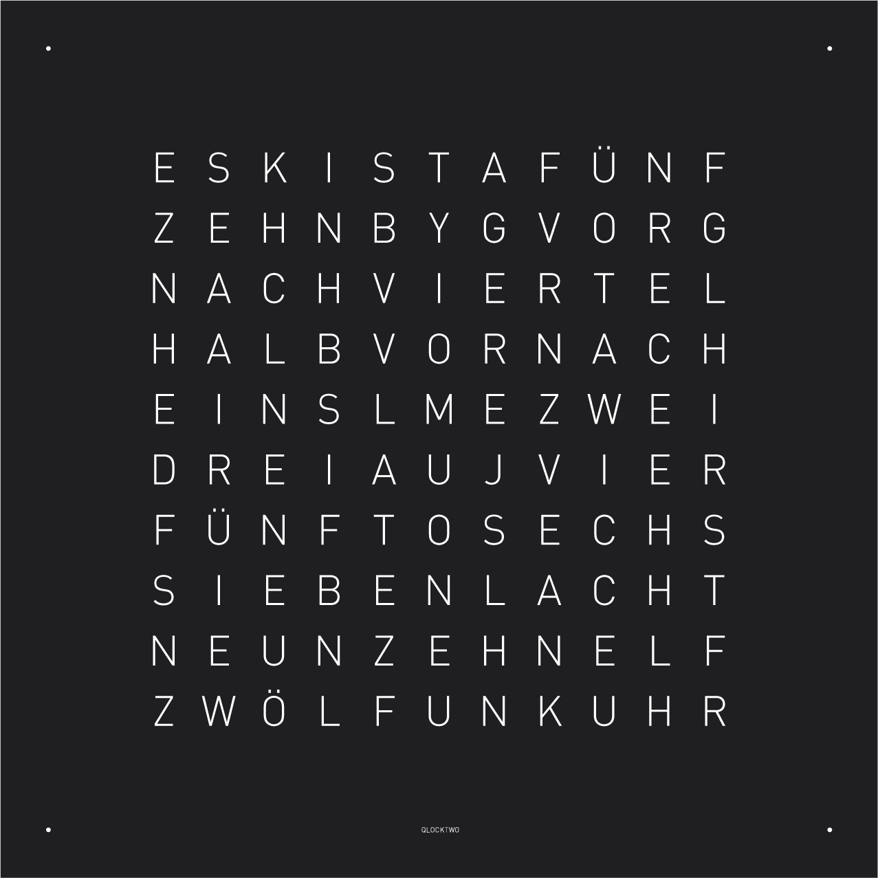
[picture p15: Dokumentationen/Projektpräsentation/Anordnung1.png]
     
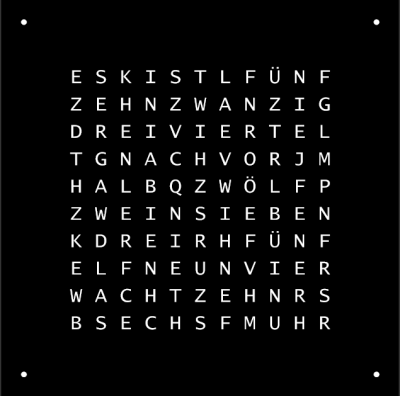
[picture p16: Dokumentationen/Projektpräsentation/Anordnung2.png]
     
\end{figure}
} 
 
\frame
{
  \frametitle{Frontplatte}
  meine Frontplatten:
  \begin{figure}
     \centering
     
     
\end{figure}
} 
 
\frame{
\frametitle{Software}
\begin{itemize}
\item RTC Ansteuerung vs  \textmu C
\item light\_ws2812 Library von cpldcpu
\end{itemize}
}

\frame {\huge noch Fragen?

\begin{figure}
     \centering
     
    
\end{figure}

}

\end{document}

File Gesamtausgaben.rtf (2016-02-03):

Gesamtausgaben:
Bestellung Reichelt: 34,95
Fablab Gehäuse und Zwischenplatte 16,50
Fablab Abstandshalter 2,00
Magnete 5,79
Fablab Uhrenquarze 0,55
Fablab abgebrochener Bohrer 1,00
Fablab P-Mosfet 1,35
Fablab Platine 3,00
gekaufte Frontplatte 41,90
WS2812B eBay 34,76
__________
141,80

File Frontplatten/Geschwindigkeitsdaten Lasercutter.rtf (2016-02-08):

Daten für den Lasercutter zum erstellen der Frontplatte:
Material: Acryl 3mm; rot besprüht, anschließend schwarz nachgestrichen:

Mit Inkscape gesteuert
—————————————>Datei vorher spiegeln und Glocke evtl tanzflächig Lasern !!!!!!
VisiCut
Gravieren
speed 90
Leistung 30

schneiden
speed 25
Leistung 100
freq 5000hz

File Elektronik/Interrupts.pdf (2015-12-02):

Universität Koblenz-Landau Institut für Physik
Universitätsstr. 1
56072 Koblenz

## Seminar Mikrocontroller

# Interrupts & I/O-Ports

## Arne Baldauf abaldauf@uni-koblenz.de

## 26. Juni 2006

Inhaltsverzeichnis

Inhaltsverzeichnis

1 Interrupts - Allgemein | 3
2 Interrupts - Atmel AVR | 7
3 I/O-Ports - Atmel AVR | 14
4 Beispiel | 18
5 Fazit | 21

2

1 Interrupts - Allgemein

### 1 Interrupts - Allgemein

In diesem Kapitel soll zunächst einmal in das Thema eingeführt und die allgemeine Interrupt-Funktionalität erläutert werden, bevor im nächsten Teil auf die spezifische Funktionalität der Atmel AVR 8bit RISC Serie eingegangen wird.

### 1.1 Einführung

Bei Interrupts handelt es sich um einen Benachrichtigungsmechanismus, welcher es einer ALU¹
erlaubt, mit minimaler Verzögerung aufgetretene Ereignisse zu erkennen und zu verarbeiten. Dabei kann es sich sowohl um intern in der ALU auftretende als auch von externen Bauteilen signalisierte Ereignisse handeln. Die Anzahl und Art der Interrupts ist plattformspezfisch, sie sind jedoch immer als fest in Hardware vorhandene Schaltung realisiert. Neben der schnellen Reaktion auf Ereignisse besitzt die Interrupt-Funktionalität den Vorteil, dass sie Multiprocessing²
ermöglicht.
Betrachtet man die regelmäßige Abfrage auf Veränderungen (auch Polling genannt) als alternative Methode zur Ereigniserkennung, so werden die Vorteile des Interruptmechanismus noch deutlicher: Die Reaktionszeit beim Polling ist schlechtestenfalls die Länge des Abfrageintervalls. Wählt man für diesen einen kleinen Wert, so ist der Prozessor zu einem hohen Anteil nur mit den Abfragen beschäftigt; wählt man einen großen Wert, so sinkt die Reaktionsgeschwindigkeit. Unabhängig davon ermöglicht Polling kein Multiprocessing. Interrupts werden in drei verschiedene Kategorien unterteilt. Zunächst einmal existiert die Gruppe der externen Interrupts, zu welcher beispielsweise das Reset-Signal und die I/O-Interrupts gehören. Als zweites ist die Gruppe der internen Interrupts zu nennen, unter welche z.B. der Supervisor Call oder die Division durch null (Divide-by-zero error) fallen. Als dritte und letzte Kategorie bleiben die Software-Interrupts, auf welche hier aufgrund der Irrelevanz für Mikrocontroller nicht weiter eingegangen werden soll.

### 1.2 Interrupt-Verarbeitung

Wurde ein Interrupt ausgelöst, müssen verschiedene Schritte vor dem Beginn und nach dem Ende der eigentlichen Interruptbehandlungsroutine abgearbeitet werden. Der Ablauf geschieht typischerweise wie folgt:
1. Interrupts sperren
2. Program Counter (PC) und Statusregister sichern
3. Privilege Level prüfen
4. PC und Statusregister der Interrupt-Routine laden

1Arithmetic Logical Unit, siehe Vortrag „ALU und Speicher“ in dieser Seminarreihe.
2Das gleichzeitige Ausführen mehrerer Programme auf einem Prozessor, quasi-parallel durch Umschalten zwischen den einzelnen Programmen; hiermit ist nicht echtes Parallel processing gemeint.

3

1 Interrupts - Allgemein

5. Interrupt freigeben
6. Ausführen der Interruptbehandlungsroutine
7. Interrupts sperren
8. PC und Statusregister wiederherstellen
9. Interrupts freigeben
Das Speichern von Program Counter³ und Statusregister geschieht auf einen Stack⁴ und ist notwendig, damit das unterbrochene Programm nach Abarbeitung der Interruptbehandlung korrekt fortgesetzt werden kann. Da die Schritte 2, 3, 4 und 8 kritisch für die korrekte Ausführung der Programme sind, dürfen diese nicht unterbrochen werden, weshalb hierfür alle Interrupts global gesperrt werden. Im Gegensatz dazu kann die eigentliche Interruptbehandlungsroutine selbst wieder durch einen weiteren Interrupt unterbrochen werden. Wird ein Interrupt signalisiert, solange die Interruptsperrung gesetzt ist, so löst die Verarbeitung unmittelbar nach Freigabe der Sperrung aus (das Interrupt-Signal „geht nicht verloren“). Auf das Privilege Level wird noch später in diesem Kapitel eingegangen.

### 1.3 Interrupt-Vektor-Tabelle

Die Interruptbehandlungsroutinen selbst sind frei programmierbar und können (theoretisch⁵ )
beliebig lang sein. Damit der Prozessor an die korrekte Adresse (die Speicherstelle mit dem ersten Befehl) dieser Routine springen kann, werden die Adressen in der Interrupt-Vektor-Tabelle gespeichert. Da die Adressen (beinahe⁶
) beliebig sein können, ist der Inhalt der Tabelle logischerweise ebenfalls programmierbar. Die Interrupt-Vektor-Tabelle selbst befindet sich jedoch immer an einer festen, für die jeweilige Prozessorarchitektur spezifischen Speicheradresse (Interrupt base address).
Ein Eintrag in der Tabelle besteht lediglich aus einer Adresse ohne weitere Informationen. Die Größe jedes Eintrags entspricht also der Adressgröße der Architektur, auf einem 32Bit-System z.B. folglich 4Byte⁷
. Die Interrupts sind durchnummeriert (0-basiert, Interrupt vector number). Ein 32Bit-Prozessor findet also die gespeicherte Adresse der eigentlichen Interrupt-Routine an der mittels der einfachen Berechnung
Interrupt_base_address + 4 * Interrupt_vector_number auffindbaren Adresse.

3Beim Program Counter (PC) handelt es sich um einen Zeiger, welcher auf die Speicheradresse zeigt, an der der nächste zu verarbeitende Befehl gespeichert ist.
4Stack, auch Stapel oder Keller genannt, ist eine Datenstruktur, bei der immer nur auf das oberste Element zugegriffen werden kann.
5Begrenzt werden diese natürlich durch den verfügbaren Programmspeicher.
6bestimmte Speicherbereiche werden bei den meisten Prozessorfamilien zur Adressierung von z.B. externen Geräten verwendet, können also nicht für das Speichern von Programmen oder Daten verwendet werden. 7Bei den aktuellen 64Bit-erweiterten Prozessoren ist ein Eintrag ebenfalls 4Byte groß und verweist (nur im 64Bit-Modus) auf einen Eintrag in einer zweiten Tabelle, welche die eigentlichen 64Bit-Adressen enthält, also 8Byte pro Eintrag.

4

1 Interrupts - Allgemein

Vector No. | Address displacement (in bytes) | Interrupt event | Source | Priority
0 | 0 | Reset | extern | 0.0
1 | 4 | I/O | extern | 0.1
2 | 8 | Bus error | extern | 0.2
3 | 12 | Address error | intern | 0.3
4 | 16 | Trace | intern | 1.0
5 | 20 | Illegal instruction | intern | 1.2
6 | 24 | Privilege violation | intern | 1.3
7 | 28 | Zero divide | intern | 2.0
8 | 32 | TRAPV instruction | intern | 2.0
9 | 36 | OPC Emulation 1 | intern | 2.0
10 | 40 | OPC Emulation 2 | intern | 2.0
11-24 | 44... | - not used - | - | -

Tabelle 1: Einträge der Interrupt-Vektor-Tabelle der Intel x86-Architektur

Die Tabelle 1 stellt die Zugehörigkeit der einzelnen Einträge der Interrupt-Vektor-Tabelle der Intel x86-Architektur dar. Wie zu erkennen ist, besitzen Prozessoren dieser Familie⁸ lediglich einen externen Interrupt für I/O-Geräte. Die einzelnen Interrupts dieser Geräte münden in den PIC oder APIC⁹

, welcher die externe Interrupt-Leitung des Prozessors ansteuert¹⁰ .
Wird ein externer Interrupt ausgelöst, so muss der Prozessor in der Behandlungsroutine zunächst das eigentliche auslösende Gerät beim PIC abfragen (dies geschieht wie bei anderen Geräten auch mittels Adress- / Datenbus) und kann dann in eine gerätespezifische Subroutine springen¹¹. Abbildung 1 stellt die Verbindungen zwischen CPU, PIC und Geräten graphisch dar.

### 1.4 Prioritäten und Privilege Levels

Wie in der Tabelle 1 ersichtlich, besitzt jeder Interrupt eine Priorität. Diese dient zum einen dazu, eine Ausführungsreihenfolge für die Interruptbehandlungsroutinen festzulegen, wenn zwei oder mehr Interrupts im gleichen Takt ausgelöst werden. Zum anderen bestimmt die Priorisierung die Reihenfolge der Verarbeitung, wenn nach Aufhebung einer globalen Interruptsperrung mehrere signalisierte Interrupts anstehen.

8Dazu zählen alle typischen aktuellen PC-Prozessoren seit dem i386 bis zu den aktuellen Intel Core2 und AMD Athlon64 Prozessoren bzw. deren Servervarianten Xeon und Opteron. Neue Befehle o.ä. stellen lediglich eine Erweiterung der Grundarchitektur dar. Nicht zu dieser Familie gehören z.B. IBM PowerPC, Sun UltraSPARC oder Intel Itanium.
9Programmable Interrupt Controller (PIC) bzw. Advanced Progammable Interrupt Controller (APIC). Diese unterscheiden sich im wesentlichen durch die Anzahl ihrer Interrupt-Leitungen (16 bzw. 24).
10Bei den in der Geräteverwaltung aktueller Betriebssysteme angezeigten Interrupts handelt es sich um die Interrupt-Leitungen des PIC / APIC, nicht um die Interrupts des Prozessors.
11An dieser Stelle setzt meistens die gerätespezifische Treibersoftware an.

5

1 Interrupts - Allgemein

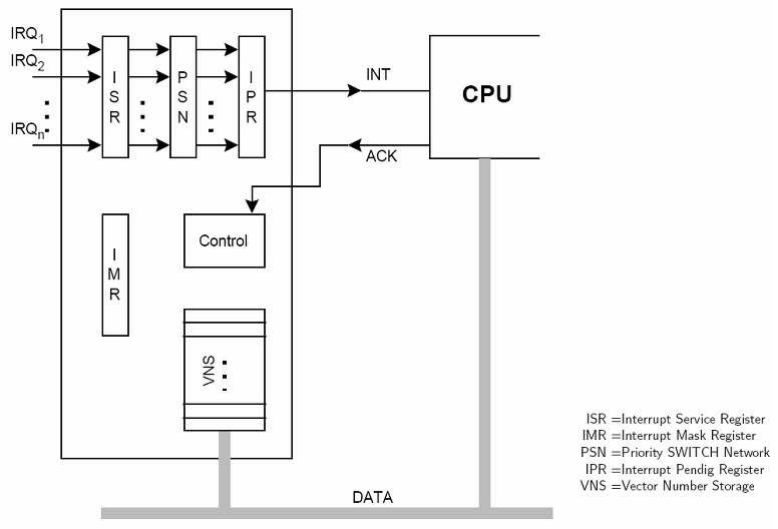
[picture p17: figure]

Abbildung 1: Ansteuerung der Geräteinterrupts und der CPU mittels eines PIC

Die Privilege Levels bestimmen vor allem bei den internen und den Software-Interrupts, durch welchen Prozess diese ausgelöst werden dürfen. Da dies nur für ausgewachsene Betriebssysteme von Bedeutung ist, sollen an dieser Stelle nur kurz die Möglichkeiten hiervon aufgeführt werden. Durch die Privilege Levels wird eine komplette Trennung von User Mode und Supervisor Mode (auch System Mode oder Kernel Mode genannt) erreicht. Sind alle Routinen des System Mode nur durch Interrupts erreichbar, so kann der Kernel die Laufzeiten und die Umschaltung der User-Mode-Prozesse verwalten, während sein eigener Programm- und Datenspeicher vor Zugriffen aus dem User Space geschützt ist. Ferner kann der Kernel dafür sorgen, dass auch die Speicherbereiche der einzelnen Prozesse voreinander geschützt sind.

6

2 Interrupts - Atmel AVR

### 2 Interrupts - Atmel AVR

Nachdem nun ein Überblick über die allgemeine Funktionsweise geschaffen wurde, wird in diesem Kapitel auf die konkrete Funktionalität und die Besonderheiten der Atmel AVR Mikrocontroller am Beispiel des AtMega16 eingegangen.

### 2.1 Interrupt-Verarbeitung

Der Ablauf der Interruptverarbeitung dieses Controllers ähnelt dem Ablauf aus Kapitel 1.3, jedoch mit einigen kleineren Abweichungen. Zunächt einmal existieren keinerlei Privilege Levels, so dass deren Überprüfung komplett entfällt. Desweiteren erfolgt durch die Hardware lediglich die globale Interruptsperrung und das Sichern des Program Counters auf den Stack zu Beginn, sowie das Zurückschreiben und die globale Interruptfreigabe zum Ende der Verarbeitung. Ein Speichern und Wiederherstellen des Zustandes des Statusregisters muss in der eigentlichen Interruptbehandlungsroutine durch die Software erfolgen. Ebenso bleiben Interrupts während der kompletten Verarbeitung gesperrt, wenn keine Freigabe in der Behandlungsroutine erfolgt (Wichtig: In diesem Fall muss auch wieder eine Sperrung erfolgen, bevor der Return from Interrupt¹² erfolgt).
Wird während der Verarbeitung eines Befehls über mehrere Takte (wie z.B. des Sprungbefehls JMP mit 3 Takten) ein Interrupt signalisiert, so wird die Interruptverarbeitung erst nach dem letzten Takt des Befehls begonnen. Der Controller benötigt vier weitere Takte, bevor der erste Befehl der Interruptbehandlungsroutine verarbeitet wird. In diesen Takten erfolgen die Interrupt-Sperrung, das Löschen des jeweiligen Interrupt Flags (dazu später mehr), das Sichern des PC sowie der Sprung an die Startadresse der Interrupt-Routine. Befindet sich der Controller in einem der Sleep-Modi (Stromspar-Modi¹³), so werden acht anstatt vier Takte für diesen Vorgang benötigt, zuzüglich der modusspezifischen Startup-Dauer.
Wird der Return from Interrupt ausgelöst, so werden wiederum vier Takte benötigt, in denen der urspüngliche PC vom Stack wiederhergestellt wird, der Sprung an die ursprüngliche Adresse erfolgt und die Interrupts freigegeben werden. Danach wird die Ausführung der unterbrochenen Routine fortgesetzt. Steht noch die Verarbeitung eines weiteren Interrupts an, so wird noch ein Befehl der unterbrochenen Routine verarbeitet, bevor die Interruptbehandlung beginnt.

### 2.2 Interrupt-Typen

Grundsätzlich existieren bei Atmel AVR Controllern zwei verschiedene Interrupt-Typen¹⁴
Jeder Interrupt des Typ 1¹⁵ besitzt ein zugehöriges Interrupt Flag, wobei es sich um ein einfaches Merkerbit handelt, das bei der Erkennung des Interrupts gesetzt und bei Beginn der

12Dies bezeichnet sowohl das Ende der Interruptbehandlungsroutine, an der der Rücksprung in die unterbrochene Routine erfolgt, als auch den Befehl, der diesen Vorgang auslöst.
13Details hierzu siehe Vortrag „Clock, Power und Watchdog“ in dieser Seminarreihe.
14Hiermit sind nicht die Interrupt-Arten (intern, extern, Software) gemeint.
15Bei externen Interrupts spricht man hier von Interrupt by edge.

7

2 Interrupts - Atmel AVR

Interruptbehandlung gelöscht wird. Die Verarbeitung setzt sofort ein, wenn Interrupts global freigegeben sind, bzw. setzt unmittelbar nach der Freigabe ein, wenn diese global gesperrt sind. Nach Ende der Behandlung wird der Interrupt erst dann erneut ausgelöst, wenn der Interrupt nochmals signalisiert wird (die Bedingung also zwischenzeitlich nicht mehr und dann wieder erfüllt wird, was bereits während der laufenden Verarbeitung sein kann).
Interrupts des Typ 2¹⁶ besitzen dagegen kein Interrupt Flag. Sind Interrupts global gesperrt, und wird die Bedingung für einen solchen Interrupt erfüllt, so setzt nach der globalen Interruptfreigabe die Interruptbehandlung nur ein, wenn die Bedingung zu diesem Zeitpunkt immer noch erfüllt ist. Ist nach Verarbeitung der Interruptbehandlungroutine der Interrupt weiterhin signalisiert, so beginnt die Interruptbehandlung erneut. Eine normale Verarbeitung des unterbrochenen Programmes erfolgt erst, wenn nach dem Durchlauf der Interruptbehandlungsroutine die Bedingung nicht mehr erfüllt ist¹⁷
Die meisten Interrupts des AtMega16 gehören zum Typ 1, lediglich die Interrupts Reset¹⁸ ,
EEPROM Ready und Store Program Memory Ready sind Interrupts des Typ 2. Einen Sonderfall stellen die externen Interrupts 0 und 1 dar: Diese verhalten sich wie Typ 1, wenn sie auf Auslösung bei einer Signalflanke (Interrupt by egde) eingestellt sind. Sind sie auf Auslösung bei einem bestimmten Signalpegel (Interrupt by level) konfiguriert, so verhalten sie sich wie Typ 2. Mehr zu den möglichen Modi der externen Interrupts später in diesem Kapitel.

### 2.3 Interrupt-Vektor-Tabelle

Die Interrupt-Vektor-Tabelle des AtMega 16 befindet sich grundsätzlich immer am Anfang des Programmspeichers (Interrupt base address = $000). Jeder Eintrag ist 2 Byte groß, dabei handelt es sich jedoch nicht um eine Adressangabe für die Interruptbehandlungroutine wie im ersten Kapitel beschrieben. Stattdessen ist in dem Eintrag ein Befehl gespeichert, welcher beim Auslösen des Interrupts ausgeführt wird. Üblicherweise handelt es sich dabei um einen Sprungbefehl in die eigentliche Interruptbehandlungsroutine. Wird ein Interrupt nicht verwendet, so ist es üblich, zur Sicherheit den Return from Interrupt-Befehl (Assembler: reti) an der entsprechenden Stelle der Tabelle einzutragen.
Tabelle 2 zeigt eine Übersicht der Einträge der Interrupt-Vektor-Tabelle. Die Einträge sind in der Tabelle und im Speicher aufsteigend nach ihrer Priorität geordnet, d.h. Reset besitzt die höchste und Store Program Memory Ready die niedrigste Priorität.

16Bei externen Interrupts spricht man hier von Interrupt by level.
17Zwischen jedem Durchlauf der Interruptbehandlungsroutine wird allerdings immer der einzelne, obligatorische Befehl des unterbrochenen Programmes ausgeführt.
18Man beachte, dass Reset invertiert ist, die „Verarbeitung“ (das Hauptprogram) also stattfindet, wenn dieser nicht ausgelöst ist.

8

2 Interrupts - Atmel AVR

Vector No. | Speicheradresse | Quelle | Auslöser
0 | $000 | RESET | External Pin, Power-On Reset, Brown-out Reset, Watchdog Reset, JTAG AVR Reset
1 | $002 | INT0 | External Interrupt Request 0
2 | $004 | INT1 | External Interrupt Request 1
3 | $006 | TIMER2_COMP | Timer/Counter2 Compare Match
4 | $008 | TIMER2_OVF | Timer/Counter2 Overflow
5 | $00A | TIMER1_CAPT | Timer/Counter1 Capture Event
6 | $00C | TIMER1_COMPA | Timer/Counter1 Compare Match A
7 | $00E | TIMER1_COMPB | Timer/Counter1 Compare Match B
8 | $010 | TIMER1_OVF | Timer/Counter1 Overflow
9 | $012 | TIMER0_OVF | Timer/Counter0 Overflow
10 | $014 | SPI_STC | Serial Transfer Complete
11 | $016 | USART_RXC | USART, Rx Complete
12 | $018 | USART_UDRE | USART Data Register Empty
13 | $01A | USART_TXC | USART, Tx Complete
14 | $01C | ADC | ADC Conversion Complete
15 | $01E | EE_RDY | EEPROM Ready
16 | $020 | ANA_COMP | Analog Comparator
17 | $022 | TWI | Two-Wire Serial Interface
18 | $024 | INT2 | External Interrupt Request 2
19 | $026 | TIMER0_COMP | Timer/Counter0 Compare Match
20 | $028 | SPM_RDY | Store Program Memory Ready

Tabelle 2: Einträge der Interrupt-Vektor-Tabelle des Atmel AtMega16

Einen typischen Programmkopf in AVR-Assembler mit allen Interruptvektoren zeigt Listing 1. Das Schlüsselwort .org bewirkt, dass der darauf folgende Befehl an die angegebene Speicheradresse geschrieben wird und stellt somit die Korrektheit der Einträge der Interruptvektortabelle sicher. Mit Ausnahme des Beginns der ersten Interruptbehandlungsroutine ist es im weiteren Programmcode aber eher unüblich (da fehleranfällig), das Schlüsselwort zu verwenden.
Die einzelnen Sprungbefehle verweisen auf die entsprechenden Sprungmarken, welche natürlich alle im weiteren Programmcode (am Beginn der jeweiligen Interruptbehandlungsroutine) vorhanden sein müssen. In Listing 1 ist lediglich der Beginn der Reset-Routine aufgeführt. Da diese meistens auch das Hauptprogramm ist, muss sie mit einigen nötigen Befehlen zur Initialisierung beginnen. So ist es zur Verwendung von Interrupts unumgänglich, den Stackpointer auf eine Adresse festzulegen, was hier auf die höchste Speicheradresse des SRAM

9

2 Interrupts - Atmel AVR

erfolgt¹⁹. Um weitere Interrupts zu ermöglichen, werden Interrupts global freigegeben (sei), denn diese sind noch vom Beginn der Reset-Interruptbehandlung gesperrt. Vor Beginn des eigentlichen Hauptprogrammes sind natürlich auch noch beliebige weitere Initalisierungsbefehle möglich. Am Ende der Interruptroutine ist es außerdem üblich, wieder an den Beginn des Hauptprogrammes zu springen (und somit die nur einmal benötigten Initialisierungsbefehle auszulassen²⁰).
1 . o r g 0 x000 | jmp RESET | ; R e s e t Handler
2 . o r g 0 x002 | jmp EXT_INT0 | ; IRQ0 Handler
3 . o r g 0 x004 | jmp EXT_INT1 | ; IRQ1 Handler
4 . o r g 0 x006 | jmp EXT_INT2 | ; IRQ2 Handler
5 . o r g 0 x008 | jmp TIM2_COMP | ; Timer2 Compare Handler
6 . o r g 0x00A | jmp TIM2_OVF | ; TIM2_OVF ; Timer2 Overflow Handler
7 . o r g 0x00C | jmp TIM1_CAPT | ; Timer1 Capture Handler
8 . o r g 0x00E | jmp TIM1_COMPA ; Timer1 CompareA Handler
9 . o r g 0 x010 | jmp TIM1_COMPB ; Timer1 CompareB Handler
10 . o r g 0 x012 | jmp TIM1_OVF | ; Timer1 Overflow Handler
11 . o r g 0 x014 | jmp TIM0_COMP | ; Timer0 Compare Handler
12 . o r g 0 x016 | jmp TIM0_OVF | ; Timer0 Overflow Handler
13 . o r g 0 x018 | jmp SPI_STC | ; SPI T r a n s f e r Complete Handler
14 . o r g 0x01A | jmp USART_RXC | ; USART RX Complete Handler
15 . o r g 0x01C | jmp USART_UDRE ; UDR Empty Handler
16 . o r g 0x01E | jmp USART_TXC | ; USART TX Complete Handler
17 . o r g 0 x020 | jmp ADCI | ; ADC C o n v e r s i o n Complete Handler
18 . o r g 0 x022 | jmp EE_RDY | ; EEPROM Ready Handler
19 . o r g 0 x024 | jmp ANA_COMP | ; Analog Comparator Handler
20 . o r g 0 x026 | jmp TWI | ; Two−wire S e r i a l I n t e r f a c e Handler
21 . o r g 0 x028 | jmp SPM_RDY | ; S t o r e Program Memory Ready Handler

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

33
19Beim Beschreiben des Stack werden beim AVR die Adressen heruntergezählt und nicht heraufgezählt, so dass hier kein Adressüberlauf erfolgt. Die Adresse ist ein 16-Bit-Wert, so dass Low Byte und High Byte initialisiert werden müssen.
20Wenn dies erwünscht ist, schließt man die Routine einfach mit reti ab. Da Reset bekanntlich konstant auslöst, beginnt danach der nächste Durchlauf.

10

2 Interrupts - Atmel AVR

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

### 2.4 Sonderfälle

Neben dem aufgezeigten Standard-Setup kann man auch noch einige nicht ganz so gebräuchliche Einstellungen vornehmen, welche sich auf die Interruptbehandlung auswirken. Diese sollen hier jedoch nur kurz aufgezeigt und nicht tiefer behandelt werden.
Wird die BOORST-Fuse programmiert, so erfolgt nach einem Reset ein Sprung an die Adresse der Boot Loader-Routine. Diese Adresse ist unter anderem von der eingestellten Größe des Loaders abhängig.
Ist das Interrupt Vector Select Bit (IVSEL) im Global Interrupt Control Register (GICR) gesetzt, so wird die Interrupt-Vektor-Tabelle an der Startadresse des Boot Flash-Speicherbereichs erwartet.
Verwendet man den Controller völlig ohne Interrupts²¹, so kann die Interrupt-Vektor-Tabelle am Anfang des Programmspeichers komplett entfallen und direkt mit dem Hauptprogramm begonnen werden.

### 2.5 Externe Interrupts

Wie in der Tabelle 2 ersichtlich, besitzt der AtMega16 drei allgemeine externe Interrupts. Diese können auf unterschiedliche Signale an dem jeweiligen Portpin einen Interrupt auslösen. INT0 und INT1 können jeweils ( unabhängig voneinander) auf eine steigende, eine fallende oder eine beliebige Signalflanke, sowie auf den 0-Pegel (on low) einen Interrupt auslösen. Im letztgenannten Fall handelt es sich um den Typ des Interrupt by level.
INT2 kann hingegen nur auf eine steigende oder eine fallende Signalflanke konfiguriert werden. Da dieser Interrupt asynchron ist, kann er auch auf Signale reagieren, welche kürzer als ein Taktzyklus des Mikrocontrollers sind. Für eine zuverlässige Erkennung darf die Pulsweite des Signals aber auch nicht kürzer als fünfzig Nanosekunden sein²². Ein wenig Vorsicht ist allerdings beim Konfigurieren von INT2 geboten. Wird der Signalerkennungsmodus umgeschaltet, während der Interrupt eingeschaltet ist, so kann dieser unbeabsichtigt auslösen.
Ist der Portpin eines externen Interrupts als Ausgang geschaltet und der Interrupt gleichzeitig eingeschaltet, so löst dieser auch aus, wenn durch die Software das Signal des Pin entsprechend dem Interrupt geschaltet wird. Dies kann einerseits eine leicht zu übersehende Fehlerquelle darstellen, andererseits handelt es sich dabei um eine Möglichkeit, Software-Interrupts zu bewerkstelligen.
Die Konfiguration der externen Interrupts erfolgt über spezielle Register. Der Signalmodus des INT0 wird mittels der Bits 0 und 1 (ISC00 / ISC01) des MCU Control Register (MCUCR)

21Hiervon ausgenommen ist Reset, welcher sich natürlich nicht sperren oder ausschalten lässt.
22Die Taktdauer beim Maximaltakt von 16MHz liegt bei 62,5ns; dies ist also vor allem bei langsamerer Taktung des Controllers von Vorteil.

11

2 Interrupts - Atmel AVR

eingestellt. Äquivalent erfolgt dies für INT1 mittels der Bits 2 und 3 (ISC10 / ISC11) im gleichen Register. Die Bitbelegung des MCUCR zeigt Abbildung 2.
Der Modus von INT2 kann mittels Bit 6 (ISC2) im MCU Control and Status Register (MCUCSR) konfiguriert werden, Abbildung 3 zeigt dessen Belegung.
Durch Setzen bzw. Löschen der Bits 5 (INT2), 6 (INT0) und 7 (INT1) im General Interrupt Control Register (GICR) können die externen Interrupts einzeln ein- bzw. ausgeschaltet werden. Die Bitbelegung des Registers wird in Abbildung 4 dargestellt.
Im Statusregister (SREG), dessen Bits in Abbildung 5 beschrieben werden, ist lediglich das Bit 7 (I) für Interrupts von Belang. Hierüber werden Interrupts global ein- (Global Interrupt Enable) oder ausgeschaltet (Global Interrupt Disable).
Die Interrupt Flags befinden sich in den Bits 5 (INTF2), 6 (INTF0) und 7 (INTF1) des General Interrupt Flag Register (GIFR), siehe Abbildung 6. Auch mittels Setzen dieser Flags durch die Software kann ein Interrupt künstlich ausgelöst werden²³

Abbildung 2: Bitbelegung des MCU Control Register (MCUCR)

Abbildung 3: Bitbelegung des MCU Control and Status Register (MCUCSR)

Abbildung 4: Bitbelegung des General Interrupt Control Register (GICR)

23Das Speichern erfolgt bei INT0 und INT1 nur in den Interrupt-by-edge Modi, ebenso ist ein Software-Interrupt durch Setzen der Flags nur in diesen Modi möglich (im Interrupt-by-level Modus ist dies nur mittels Schreiben der Portpins möglich).

12

2 Interrupts - Atmel AVR

Abbildung 5: Bitbelegung des Statusregisters (SREG)

Abbildung 6: Bitbelegung des General Interrupt Flag Register (GIFR)

13

3 I/O-Ports - Atmel AVR

### 3 I/O-Ports - Atmel AVR

In diesem Kapitel werden primär die allgemeinen I/O-Ports des Mikrocontrollers behandelt, bevor eine kurze Übersicht über die Alternativfunktionen der Ports gezeigt wird. Auf die Einzelheiten der Alternativfunktionen wird an dieser Stelle jedoch nicht eingegangen, da dies Bestandteil anderer Vorträge dieses Seminars ist.

### 3.1 Allgemeine I/O-Ports

Der Atmel AtMega16 Controller besitzt vier I/O-Ports mit jeweils acht Pins, welche standardmäßig als allgemeine digitale I/O-Ports geschaltet sind. Auf jeden Portpin besteht voller Schreib-/Lesezugriff, und dieser erfolgt komplett unabhängig von allen anderen Pins. Jeder Pin kann also zur Laufzeit gelesen, geschrieben oder umkonfiguriert werden, ohne dass dies andere Pins beeinflussen würde. Die Portpins können sowohl als digitaler Eingang als auch als digitaler Ausgang geschaltet werden, nach dem Einschalten des Controllers ist ersteres der Fall.
Alle Portpins besitzen Treiber²⁴, welche logischerweise nur aktiv sind, wenn der zugehörige Pin als Ausgang konfiguriert ist. Jeder dieser Treiber ist ausreichend stark dimensioniert zur direkten Ansteuerung einer Standard-LED.
Ist ein Pin als Eingang konfiguriert, so kann für diesen ein interner Pull-Up-Widerstand²⁵ geschaltet werden, standardmäßig ist dieser aber deaktiviert. Der Widerstand besitzt einen festen, von der Versorgungsspannung des Controllers unabhängigen Wert.
Zur Absicherung des Controllerkerns vor Spannungsspitzen an den Ports besitzt jeder Pin jeweils eine Zenerdiode²⁶ gegen die Versorgungsspannung (VCC) und gegen Masse (GND). Da alle Portpins ein Synchronisierungsglied²⁷ besitzen, erfolgt die Schaltung des Signals an einem Ausgang erst einen Controllertakt nach dem Schreiben des jeweiligen Wertes. Ebenso existiert an einem Eingang eine Verzögerung zwischen der Veränderung des Signals und der Auslesbarkeit des Wertes. Da ein externes Signal nicht synchron zum Controllertakt geschaltet sein muss, beträgt die Verzögerung bestenfalls 0,5 Takte, schlechtestenfalls 1,5 Takte (abhängig vom Zeitpunkt der Signaländerung relativ zum Takt).

Auch die Konfiguration und Steuerung der I/O-Ports erfolgt mittels spezieller Register, über die hier nun ein Überblick geschaffen werden soll. Im folgenden werden lediglich die Regis-

24Treiber sind Operationsverstärker, üblicherweise eine Transistorschaltung.
25Ein Pull-Up-Widerstand schaltet den Pegel eines Eingangs auf high (logisch 1), so dass daran angeschlossene Bauteile ein low-Signal (logisch 0) durch Schaltung der Leitung auf Masse erzielen. Ist kein Pull-Up-Widerstand aktiviert, liegt der Pegel auf low und Bauteile müssen selbst auf high schalten.
26Zenerdioden, auch Z-Dioden genannt, sind in Sperrrichtung unterhalb ihrer spezifischen Durchbruchspannung undurchlässig, oberhalb dieser schalten diese jedoch durch (ohne dabei wie gewöhnliche Dioden Schaden zu nehmen), so dass man sie u.a. zur Spannungsbegrenzung einsetzen kann.
27Das Synchronisierungsglied sorgt dafür, daß das Signal nur an der relevanten Taktflanke in die zugehörigen Register übertragen wird und umgekehrt. Es stellt dadurch sicher, daß der Controller nicht durch Umspringen des Signals mitten im Takt in einen undefinierten Zustand gerät.

14

3 I/O-Ports - Atmel AVR

ter von Port A besprochen, die Register der Ports B bis D sind in der Funktion und Belegung äquivalent dazu.
Mittels des Data Direction Register A (DDRA), dessen Bitbelegung in Abbildung 7 gezeigt ist, lassen sich die Pins als Eingänge (Bit gelöscht) oder Ausgänge (Bit gesetzt) schalten. Die Bitnummer entspricht dabei der Pinnummer des Ports.
In Abbildung 8 ist die Belegung von Pin Data Register A (PINA) dargestellt. In diesem Register kann das anliegende Signal der Pins ausgelesen, jedoch nicht geschrieben werden (nur Lesezugriff). Auch hier entsprechen Bit- und Pinnummer einander.
Die Funktion der einzelnen Bits des Port Data Register A (PORTA), die Belegung zeigt Abbildung 9, sind abhängig von den Werten in DDRA. Für die als Ausgänge geschalteten Pins kann in den entsprechenden Bits das Signal geschrieben und auch gelesen werden. Für die als Eingänge geschalteten Pins jedoch wird mittels der entsprechenden Bits der zugehörige Pull-Up-Widerstand ein- (Bit gesetzt) oder ausgeschaltet (Bit gelöscht). Dies erklärt auch die Existenz der Pin Data Register, da es ansonsten bei Eingängen nicht möglich wäre, das aktuelle Signal abzufragen.
Von Bedeutung für die I/O-Ports ist auch noch das Bit 2 (PUD) im Special Function I/O Register (SFIOR). Ist dieses gesetzt, so bleiben alle Pull-Up-Widerstände ausgeschaltet, unabhängig der Werte in den Port Data Registern. Die Position dieses und der restlichen Bits des Registers kann Abbildung 10 entnommen werden.

Abbildung 7: Bitbelegung des Data Direction Register A (DDRQ)

Abbildung 8: Bitbelegung des Pin Data Register A (PINA)

### 3.2 Alternative Funktionen der I/O-Ports

Neben der Funktion als allgemeine digitale I/O-Ports können die Portpins auch für verschiedene Spezialfunktionen verwendet werden. Dabei sollte beachtet werden, dass auch bei aktivierten Alternativfunktionen der Zugriff über die Register der Standardports möglich ist. Da dies ein Fehlerpotential darstellt, empfiehlt es sich, eine Doppelverwendung zu vermeiden.

15

3 I/O-Ports - Atmel AVR

Abbildung 9: Bitbelegung des Port Data Register A (PORTA)

Abbildung 10: Bitbelegung des Special Function I/O Register (SFIOR)

Im folgenden werden die Spezialfunktionen dargestellt, die genaue Pinbelegung ist in Tabelle 3 aufgelistet.
Alle Anschlüsse des Port A können als Eingänge für die acht Kanäle des Analog-Digital-Konverters (ADC) verwendet werden, ansonsten existieren keine Alternativfunktionen.
An Port B können der Bus der seriellen Programmierschnittstelle (SPI), die beiden Eingänge der analogen Vergleichseinheit (AC), der externe Interrupt 2 (INT2), der Takt der seriellen Schnittstelle (USART) sowie optionale Signale des Timer/Counter 0 und 1 angeschlossen werden.
Port C ist alternativ belegt mit den Anschlüssen der Schnittstelle des JTAG Debuggers, der optionalen externen Taktquelle der Zählwerke und des Two-Wire-Interface (TWI) für den I
2C-
oder den System-Management-Bus (SMBus)

28
Auf die Pins an Port D können auch die externen Interrupts 0 (INT0) und 1 (INT1), die beiden Datenleitungen der seriellen Schnittstelle (USART) und optionale Signale der Timer/Counter 1 und 2 geschaltet werden.
Port Pin | Bezeichnung | Beschreibung Alternative Funktion(en)
PA7 | ADC7 | ADC Input Channel 7
PA6 | ADC6 | ADC Input Channel 6
PA5 | ADC5 | ADC Input Channel 5
PA4 | ADC4 | ADC Input Channel 4
PA3 | ADC3 | ADC Input Channel 3
PA2 | ADC2 | ADC Input Channel 2
PA1 | ADC1 | ADC Input Channel 1
PA0 | ADC0 | ADC Input Channel 0

28Der Unterschied liegt lediglich in Details der Spezifikationen

16

3 I/O-Ports - Atmel AVR

PB7 | SCK | SPI Bus Serial Clock
PB6 | MISO | SPI Bus Master Input / Slave Output
PB5 | MOSI | SPI Bus Master Output / Slave Input
PB4 | ISS | SPI Slave Select Input
PB3 | AIN1 OC0 | Analog Comparator Negative Input Timer/Counter0 Output Compare Match Output
PB2 | AIN0 INT2 | Analog Comparator Positive Input External Interrupt 2 Input
PB1 | T1 | Timer/Counter1 External Counter Input
PB0 | T0 XCK | Timer/Counter0 External Counter Input USART External Clock Input / Output
PC7 | TOSC2 | Timer Oscillator Pin 2
PC6 | TOSC1 | Timer Oscillator Pin 1
PC5 | TDI | JTAG Test Data In
PC4 | TDO | JTAG Test Data Out
PC3 | TMS | JTAG Test Mode Select
PC2 | TCK | JTAG Test Clock
PC1 | SDA | Two-wire Serial Bus Data Input/Output Line
PC0 | SCL | Two-wire Serial Bus Clock Line
PD7 | OCP2 | Timer/Counter2 Output Compare Match Output
PD6 | ICP1 | Timer/Counter1 Input Capture Pin
PD5 | OC1A | Timer/Counter1 Output Compare A Match Output
PD4 | OC1B | Timer/Counter1 Output Compare B Match Output
PD3 | INT1 | External Interrupt 1 Input
PD2 | INT0 | External Interrupt 0 Input
PD1 | TXD | USART Output Pin
PD0 | RXD | USART Input Pin

Tabelle 3: Alternativfunktionen der I/O-Ports des AtMega16

17

4 Beispiel

### 4 Beispiel

Beim hier verwendeten Beispiel handelt es sich um einen Ausschnitt aus einer real existierende Schaltung. Die Originalschaltung besitzt viele weitere Bauelemente, welche das Beispiel unnötig komplex machen würden und hier deshalb ausgelassen werden.
Das reduzierte Schaltbild ist in Abbildung 11 gezeigt. Wie zu erkennen, sind dabei sechs Taster an den Mikrocontroller angeschlossen. Mittels Pull-Up-Widerständen werden die Signalpegel der Anschlusspins auf high gelegt. Dies geschieht in diesem Beispiel zur Verdeutlichung

29
,
die internen Pull-Up-Widerstände des AtMega16 hätten ebenso gut funktioniert. Wird einer der Taster gedrückt, so wird der jeweilige Pin mit Masse verbunden und so auf low gezogen. Damit der Zustand der Taster nicht ständig in der Software abgefragt werden muss, sind alle Tasterpins über Dioden mit dem externen Interrupt 0 verbunden. Der Anschluss des Interrupts muss selbst ebenfalls über einen Pull-Up-Widerstand auf high gelegt werden. Die Dioden stellen sicher, dass beim Drücken eines Tasters nicht alle anderen Signale ebenfalls auf low gezogen werden, wohl aber der Interrupt-Pin (Der Interrupt ist im Endeffekt ein logisches Und über die Taster). Sinn davon ist es, beim Drücken jedes Tasters den Interrupt auszulösen und in der folgenden Interruptbehandlungsroutine mittels Abfrage der Portpins den eigentlichen Taster zu identifizieren.

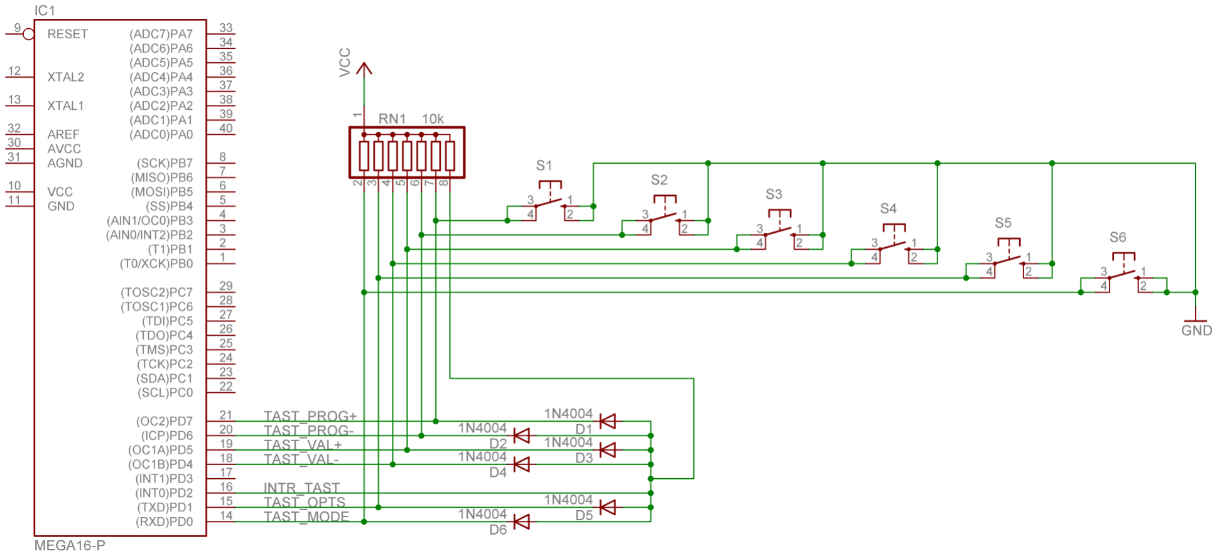
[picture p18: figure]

Abbildung 11: Schaltbild des verwendeten Beispiels

Die relevanten Ausschnitte der Tasterschaltung sind in Listing 2 aufgeführt. Vor dem eigentlich Codesegment werden dabei die Definitionen (Register etc.) des verwendeten Controllers importiert (Zeile 1). Desweiteren werden für einige Register neue Namen definiert, welche einen bestimmten Verwendungszweck verdeutlichen (Zeilen 4-5). Darüber hinaus werden Konstanten definiert, um die Abfrage der Pinbelegung der Taster zu vereinfachen (Zeilen

29Außerdem besaß der im allerersten Layout verwendete, ältere Controller keine eigenen Pull-Up-Widerstände.

18

4 Beispiel

8-14).
Der Programmcode beginnt mit der Interrupt-Vektor-Tabelle an der dafür vorgesehenen Programmspeicheradresse (Zeilen 19-21).
Im Initialisierungskopf des Hauptprogrammes werden der Stackpointer initalisiert (Zeilen 26-29), der Port D als Eingang konfiguriert (Zeilen 31-32), der externe Interrupt 0 auf die fallende Signalflanke eingestellt und eingeschaltet (Zeilen 19-21). Als letztes wird die globale Interruptsperrung aufgehoben (Zeile 36). Der eigentliche Teil des Hauptprogrammes kann außer acht gelassen werden.
Die Interruptbehandlungsroutine beginnt mit dem obligatorischen Sichern des Statusregisters und aller weiteren Register (Zeilen 44-45), welche in der Behandlungsroutine verwendet werden (in diesen könnten sich ebenfalls noch relevante Daten der unterbrochenen Routine befinden). Danach wird die erfolgte globale Interruptsperrung aufgehoben (Zeile 46). Als nächstes wird der Status der Pins an Port D in ein Arbeitsregister eingelesen³⁰ (Zeile 48). Anhand der Daten im Arbeitsregister wird nun bestimmt, welcher Taster gedrückt wurde (Zeilen 49-61), und dementsprechend an die Sprungmarke der jeweiligen Subroutine verzweigt (der Kürze halber ist nur der Rumpf der ersten aufgeführt).
In der jeweiligen Subroutine können die entsprechenden Aktionen bewirkt werden, danach erfolgt der Sprung zur letzten Subroutine der Interruptbehandlung (Zeilen 63-65). Am Ende der Interruptbehandlungsroutine folgen nun die obligatorischen Vorgänge der globalen Interruptsperrung, das Wiederherstellen der gesicherten Register und der Return-from-Interrupt. Damit ist die Interruptbehandlung abgeschlossen.
1 . i n c l u d e " m 1 6 d e f . i n c " | ; D e f i n i t i o n f ü r AtMega16

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

15

16 ; ∗∗∗∗∗∗∗∗∗∗∗∗∗∗∗∗∗∗∗∗∗∗∗∗∗∗∗∗∗∗∗∗∗∗∗∗∗∗∗∗∗∗∗∗∗∗∗∗∗∗∗∗∗
17 . c s e g | | | ; CODE segment
18 ; ∗∗∗∗∗∗∗∗∗∗∗∗∗ | I n t e r r u p t −Vektor−T a b e l l e ∗∗∗∗∗∗∗∗∗∗∗∗∗∗
19 . o r g | 0 x000 | jmp RESET | ; R e s e t Handler

30In einer realen Schaltung wird zuvor eigentlich noch eine kleine Pause zum Entprellen des Tasters eingelegt (das Signal kann beim Drücken und Loslassen von Tastern kurzzeitig „flattern“).

19

4 Beispiel

20 . o r g | 0 x002 | jmp EXT_INT0 ; IRQ0 Handler
21 ; . . . | . . . | . . . | . . .

22

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

62
63 NEXTPROG: | ; A k t i o n e n f ü r d i e

20

5 Fazit

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

### 5 Fazit

Nach den erfolgten Betrachtungen ist klar, dass große Teile der heutigen Computerarchitektur ohne den Interruptmechanismus nicht machbar wären, und dass die heutezutage erzielte Leistungsfähigkeit eines Prozessors im Zusammenspiel mit einer Vielzahl von Geräten undenkbar wäre.
Ebenso ist klar, dass Interrupts auch die Leistungsfähigkeit, Flexibilität und Möglichkeiten von modernen Mikrocontrollern steigern. Aufgrund der hardwarenahen Programmierung liegt es jedoch vor allem am Entwickler, diese Möglichkeiten zu kennen und zu nutzen.

Literatur

[1] Vorlesungsskript Rechnerstrukturen, WS 2000/2001, Prof. Dr. Christoph Steigner, Universität Koblenz-Landau, FB4
[2] Vorlesungsskript Technische Informatik B, Kapitel 8, WS 2005/2006, Prof. Dr. Christoph Steigner, Universität Koblenz-Landau, FB4 https://www.uni-koblenz.de/~steigner/tib/TIB-8.ppt
[3] Datenblatt Atmel AtMega16, Revision M, Atmel Corporation, April 2006 http://www.atmel.com/dyn/resources/prod_documents/doc2466.
| pdf

21

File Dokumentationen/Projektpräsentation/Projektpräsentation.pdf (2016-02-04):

## DIY Projektvortrag

Christof Pfannenmüller

4. Februar 2016

mein Projekt

# Wordclock auf einer Platine

## mein Projekt

## Was sollte das Projekt enthalten?

I Wordclock
I Möglichkeit mich aufzuwecken
I klein genug für den Nachttisch -> max. 20cm I Stromreserve über die Nacht
I viele viele verschiedene Sprachen

## mein Workflow

I Pflichten und Lastenheft I Layout in Eagle
I CAD Modell
I Frontplatte

## Layout in Eagle

I möglichst universell
I Größe des Vorbildes einhalten

## Layout

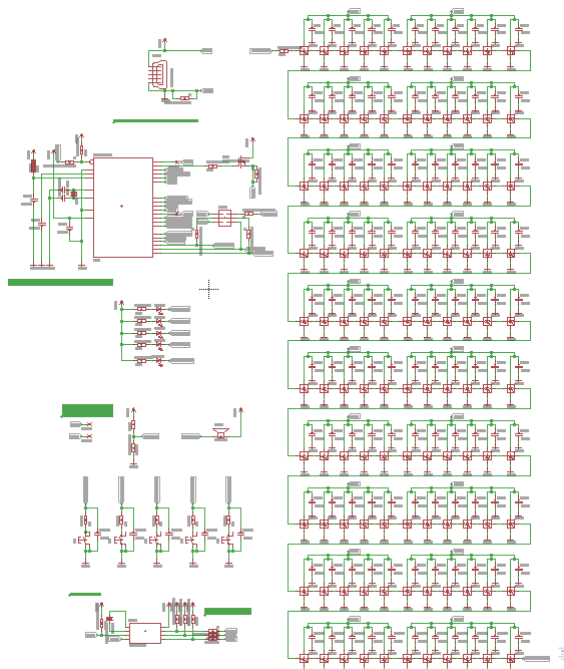
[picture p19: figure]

## Layout

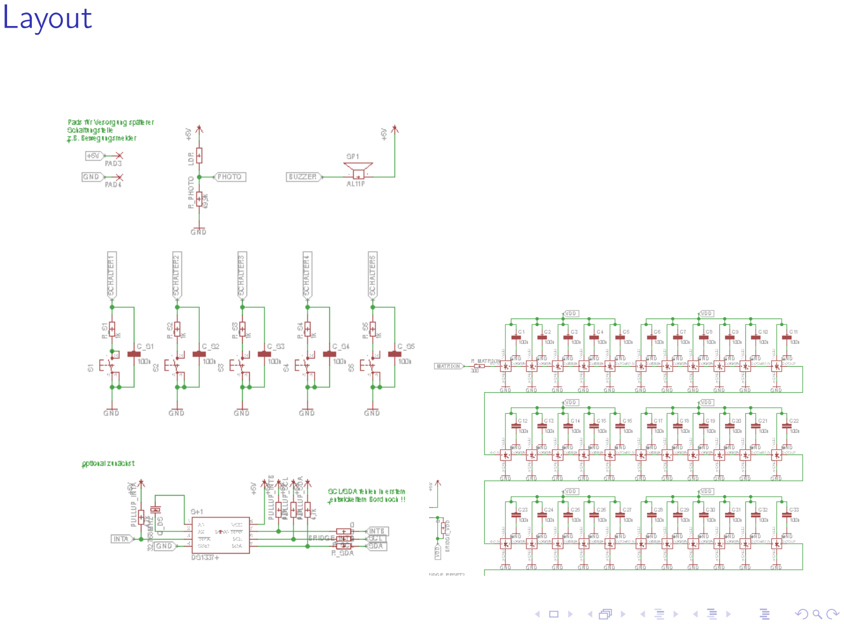
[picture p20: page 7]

## Qlocktwo als Größenvorbild


## CAD Modell

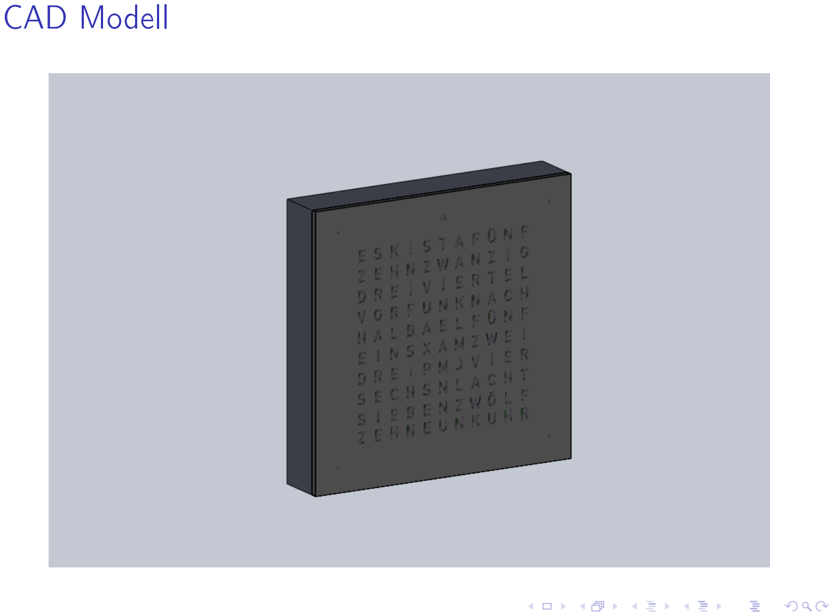
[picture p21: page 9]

## CAD Modell

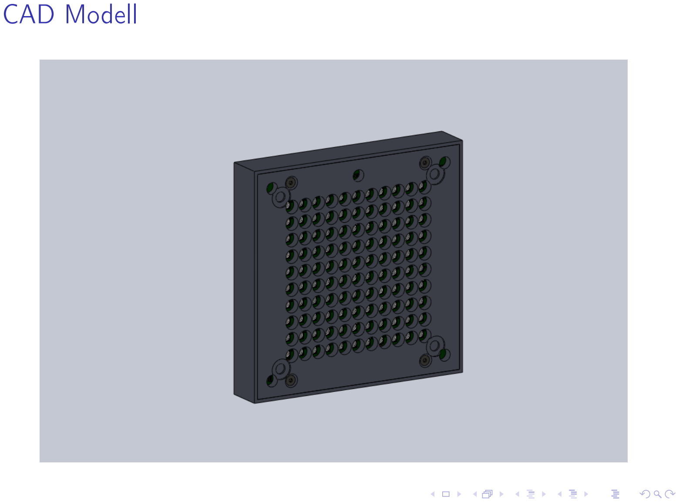
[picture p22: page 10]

## CAD Modell

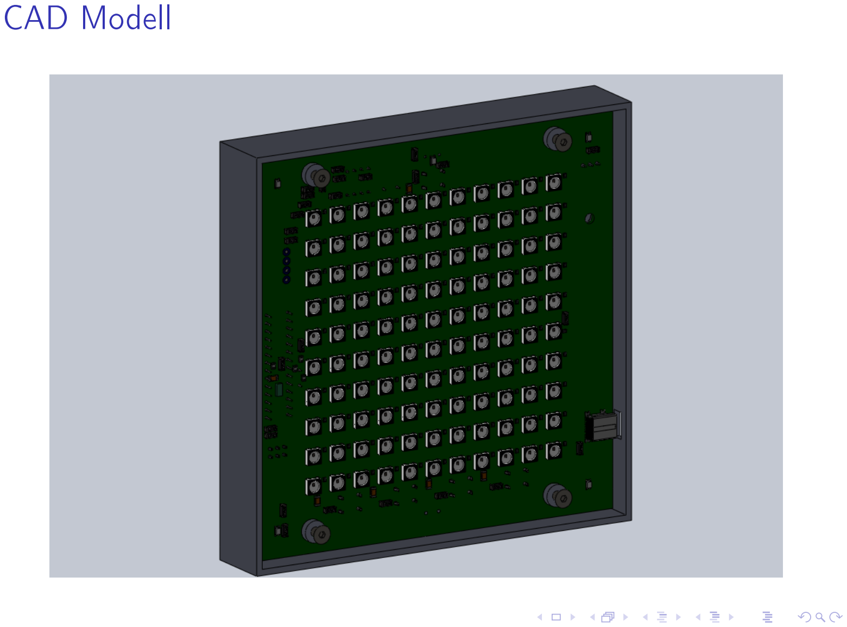
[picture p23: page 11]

## CAD Modell

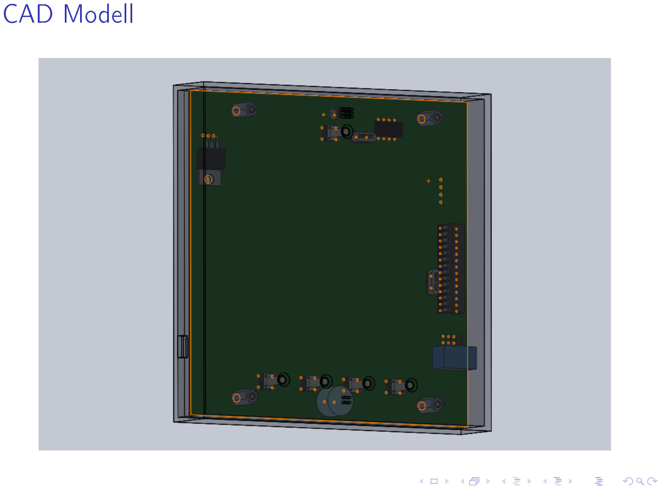
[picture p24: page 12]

## CAD Modell


## CAD Modell


## Frontplatte

Anordnung der Buchstaben


## Frontplatte

meine Frontplatten:


## Software

I RTC Ansteuerung vs µC
I light_ws2812 Library von cpldcpu

# noch Fragen?

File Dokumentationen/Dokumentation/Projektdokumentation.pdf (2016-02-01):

# DIY Wordclock

Christof Pfannenmuller ¨

✦

### 1 EINFUHRUNG ¨

WORDCLOCKS haben in der Bastler oder DIY-Szene eine große Verbreitung und bergen eine gewisse Faszination. Grundsatzlich sind die alle Wordclocks sehr ¨ ahnlich aufgebaut. Fast immer wird eine Front- ¨ platte auf welcher die Buchstaben passend angeordnet sind, durch eine Matrix an LEDs von hinten erleuchtet. Dadurch, dass nur die zur aktuellen Stunde passenden Worter erleuch- ¨ tet sind, stechen diese aus den, auf den ersten Blick verwirrend angeordneten, Buchstaben der Frontplatte hervor. Wichtig bei einer Wordclock ist auch, dass jede LED nur den fur sie vorgesehen Buchstaben der Frontplatte ¨ beleuchtet und nicht zu einem Teil auch die benachbarten Buchstaben, da dies den Effekt des Hervorscheinens der erleuteten Buchstaben
vor den dunkleren minimieren wurde. Daf ¨ | ur¨
wird meist eine so genannte Zwischenplatte angebracht, so kann sichergestellt werden, das das Licht einer LED nicht auf einen anderen Teil der Frontplatte scheint, da es durch die Zwischenplatte abgeschirmt wird. Wordclocks wurden bereits in vielen verschiedenen Sprachen erstellt, wobei grundsatzlich jede Sprache ¨ moglich ist. Die einzige Bedingung ist, dass es ¨
moglich ist alle W ¨ | orter die zum ßchreiben”der ¨
Uhrzeit notwendig sind, auf der Frontplatte anzuordnen. Dabei ist jedoch wichtig, dass die
Reihenfolge der Worter so gew ¨ | ahlt wird, das ¨
jede mogliche Uhrzeit auch dargestellt werden ¨ kann, ohne aber ein Wort doppelt unterbringen zu mussen und trotzdem die Reihenfolge ¨ der Worter dem Sprachgebrauch entspricht. In ¨ diesem Zusammenhang ist etwa die Darstellung der Zeit 15:45 interessant, denn je nach Wohnort werden fur diese verschiedene Zeiten ¨ im Umgang verwendet. Vor allem in Sachsen, Thuringen und Franken wird die Bezeichnung ¨ ”dreviertel vier”verwendet, in Norddeutschland dagegen eher ”viertel vor sechs”. Solche
Feinheiten mussen also ber ¨ | ucksichtigt werden, ¨
bei ”viertel nach drei”bzw. ”viertel vier”verhalt ¨ es sich ahnlich. ¨

### 2 ANFORDERUNGEN

Die Wordclock sollte vor allem - im Gegensatz zu den meisten anderen - kleiner ausgelegt sein und nicht zum Aufhangen an der Wand ge- ¨ dacht sein, sondern als modulare kleine Tischuhr, die bei Einbau einer Alarmfunktion, auch als Wecker dienen kann. qlocktwo als vorbild
Um zunachst einen ¨ | Uberblick zu bekommen ¨
sammelte ich alle moglichen Projektideen und ¨ mogliche Umsetzungen in ¨
Zur Versionskontrolle wird wahrend des ¨ Projektes fur alle Dateien github eingesetzt um ¨ jeweils den aktuellen Stand zu protokollieren.

### 3 HARDWARE

Elektronik
Fur die Platine wird Eagle als PCB-Software ¨ zum Entwurf der Platine verwendet, da es kostenlos verwendet werden kann und die Platinenentwicklung im Fablab auf Eagle ausgerichtet ist. Das Ziel ist die Platine einlagig aufzu-
bauen. Dies erhoht zwar den Aufwand f ¨ | ur das ¨
Layout immens, dafur kann aber eine einlagi- ¨ ge Platine verwendet werden, die wesentlich einfacher zu entwickeln ist, als eine zweilagige.

Auch werden keine Vias in der Platine benotigt, ¨ die im Fablab etwas aufwandiger sind. Da der ¨ Platz aber durch die Vorgabe der Frontplatte begrenzt ist, mussen auch kleine Bautei- ¨ le verwendet werden, die etwas aufwandiger ¨ zu loten sind. Versorgt werden soll die LED ¨ mittels Strom aus einem USB-Ladegerat oder ¨ Computer damit kein besonderes Ladegerat¨ notwenig ist. Dies legt die Versorgungsspannung auf 5 Volt fest. Als Buchse wird eine kombinierte Micro-USB-Buchse die fur Stecker ¨ des Types A und B geeignet istverwendet. Letzere stellt sicher, dass die Wordclock an ei-
nem handelsublichen Ladekabel f ¨ | ur Handys ¨
angeschlossen werden kann. Die Hauptarbeit ubernimmt dabei ein Prozessor der Mega8- ¨ Reihe von AVR verwendet, da dieser einfach zu programmieren und leicht verfugbar ist. Genau ¨ wird der Atmega168PA-PU verwendet, der den großten programmierbaren Flash seiner Baurei- ¨
he zur Verfugung stellt. Da ein sp ¨ | aterer Einbau ¨
einer Batteriepufferung moglich sein soll, ver- ¨ wenden wir hier die Pico-Power Ausfuhrung ¨ des AVR, da diese weniger Strom im Schalfmodus verbaucht, was hierbei hilfreich sein kann. Als Baugroße verwende ich hierbei die ¨
PDIP Ausfuhrung . Da bei diesem Geh ¨ | ause ¨
die Pins nahe beieinander liegen, der AVR gut zwischen der LED-Matrix und dem Rand der Platine eingebaut werden. Hierfur w ¨ are ¨ eine andere Gehauseform zu groß. Zum Pro- ¨ grammieren des AVR wird eine Standart ISP-Stecker verwendet, da bereits damit zu rechen ist, das die Software mehrfach aufgespielt werden muss, bis diese reibungslos lauft. Die LED- ¨ Matrix zum Anzeigen der einzelnen Buchstaben der Matrix werden durch 110 WS2812B LEDs aufgebaut. Diese LEDs haben den Vorteil, dass sie eine eigene Datenleitung haben, und der Mikrocontroller daher nur einen Pin bereitstellen muss, um alle hundertzehn Buchstaben ansteuern zu konnen. Dies funktioniert, ¨ indem ein in die LED eingebauter Chip die-
ses Datensignal empfangt und ¨ | uber den Data- ¨
Out-Pin der LED die folgenden LEDs mit dem Datensignal versorgt. Alle drei Grundfarben konnen durch den Chip in 255 Stufen bei den ¨ LEDs getrennt geregelt werden, damit kann also mit jedem der 110 Buchstaben das gesamte Farbspekrum von 16777216 verschiedenen Farben dargestellt werden. Dem Datenblatt der WS2812B zufolge sollte bei jeder WS2812B ein Kondensator mit 100nF zwischen Versorgungsspannung und Ground im Layout eingebaut werden. Dies dient dazu, die Versorgungsspannung der LED zu stabilisieren und somit die sicherzustellen, das die Ansteuerung richtig funktioniert. Da fur die Versorgung des ¨ eingebauten Steuerchips der WS2812B auch im Ausgeschalteten Zustand Strom benotigt wird, ¨ kann die Gesamte Matrix uber einen P-Kanal- ¨ Mosfet von der Versorgungsspannung getrennt werden.Fur die LEDs, welche die einzelnen ¨ Minuten und den Alarm anzeigen, werden dagegen ”normale”LEDs verwendet, deren Kathode vom Mikrocontroller auf Ground gezogen werden konnen und damit angeschaltet ¨ werden. Um keine ungewollten Aktionen beim Programmieren des Atmega auszulosen wer- ¨ den die LEDs auf die selben Pins des Mikrocontroller gelegt, die auch als Verbindung zum In-System-Programmer dienen. Beim Programmieren des AVR kann es also nun vorkommen, dass die LEDs aktiviert werden, es kann jedoch kein Schaden an Bauteilen erzeugt werden, obwohl diese Pins doppelt genutz werden. Die Uhrzeit soll sowohl im Mikrocontroller selbst als auch in einem externen Realtime-
Clock-Baustein gezahlt werden k ¨ | onnen. Der ex- ¨
terne Baustein hat hierbei wieder die Vorteile, dass der Atmega168 im Schlafmodus sein kann und somit wenig Strom benotigt wird. ¨ Als Clock-Baustein wird hierfur ein DS1337 ¨ verwendet, da dieser zwei externe Interrupt Kanale besitzt und somit den Mikrocontroller ¨ durch einen Alarm aus dem Schlafmodus aufwecken kann. Die Real-Time-Clock wird vom AVR uber das Two-Wire Protokoll angesteuert ¨ werden. Fur das Einstellen der Uhrzeit und ¨ das nutzen anderer Funktionen wie etwa eines Alarms wurden funf Taster verbaut. Al- ¨ le diese sind mit einem Kondensator entprellt und jeder Taster ist am AVR angeschlossen, sodass ein Tastendruck mit einem Pin-Change-Interrup detektiert werden kann. Außerdem wurde ein LDR (Light Dependent Resistor) also ein Lichtbhaniger Widerstand eingebaut. ¨ Somit kann zu einem spateren Zeitpunkt die ¨

Helligkeit der Matrix in Abhanigkeit von der ¨ Umgebungshelligkeit gesteuert werden kann. So wird sichergestellt, dass die LEDs niemals blenden, was vor allem fur den Einsatz als ¨ Wecker wichtig ist, aber auch zu jeder Tageszeit gut erkennbar sind. Damit die Uhr auch in der Lage ist ihre Benutzer zu wecken wurde ein Signalgeber eingebaut, der uber einen internen ¨ Generator verfugt und somit nicht mit einer ¨ Sinusschwingung angeregt werden muss, sondern nur durch anklemmen an die 5V Versorgungsspannung aktiviert werden kann. Dies ist durch den Mikrocontroller wesentlich leichter zu realisieren. Die zwei nicht verwendendeten Pins des Atmega wurden auf ein Via an einer freien Stelle der Leiterplatte gelegt, außerdem wurde hier noch ein Via fur Ground ¨ und +5Volt eingefugt. Somit kann hier zu einem ¨
spateren Zeitpunkt einfach eine L ¨ | osung zur ¨
Spannungsuberbr ¨ | uckung einbaut werden. Die- ¨
se konnte sogar mit dem AVR kommunizieren ¨ und die Wordclock konnte dadurch in einen ¨ stromsparenderen Modus wechseln.

Gehause ¨
Um das Gehause der Wordclock planen zu ¨ konnen erstelle ich zuerst ein CAD-Modell. ¨ Als Programm wurde dafur das SolidWorks ¨ verwendet. Dies wurde auch vor dem Hintergrund gemacht, dass die aus den in Solid Works erstellten Dateien etwa die Schnittmuster fur¨ die Zwischenplatte extrahiert werden konnen. ¨ Da Eagle die Moglichkeit besitzt, das Layout ¨ der Platine im Intermediate Data Format (IDF) zu exportieren, welches fur den Austausch ¨ von Layout und CAD-Programmen gedacht ist, konnte damit in SolidWorks ein genaues 3D Modell erstellt werden. Die einzelnen CAD-Modelle der Bauteile dafur sind im Internet frei ¨ verfugbar. Somit konnte anhand der Platine mit ¨ den angebrachten Bauteilen ein gutes Gehause ¨ geplant werden. Fur den Prototyp wurde das ¨
Gehause mit dem Onlinetool ”Boxmaker ¨ | aus ¨
Akryl ausgelasert. Die Zwischenplatte, die dazu dient die einzelnen LEDs gegeneinander abzuschirmen wurde ebenfalls zuerst in Solid-Works erstellt und anschließend mit dem Lasercutter aus einer MDF Platte Die Dicke der Zwischenplatte ergibt sich aus dem Abstrahlwinkel der LEDs, dieser betragt bei den WS2812B 120°. ¨ Fur die Dicke der Zwischenplatte ergibt sich ¨ also mit einer Buchstabengroße von etwa 8mm: ¨

d =

1/2∗ Buchstabendurchmesser
tan¹²⁰◦
2

= 4, 62 (1)

Aus diesem Grund wurde eine Dicke von 5mm
fur die Zwischenplatte gew ¨ | ahlt. Zusammen- ¨
gehalten wird die gesamte Uhr von vier M3 Schrauben, welche die Platine, die Zwischenplatte und das Gehause mit Abstandshalter fi- ¨ xieren, damit diese nicht verrutschen.

Frontplatten
Fur die Frontplatte wurde die Anordnung der ¨ Buchstaben in einer Illustrator-Datei erstellt. Dabei wurden alle Buchstaben so angeordnet, dass diese exakt uber das entsprechende Loch ¨ in der Zwischenplatte passen. Fur die erste An- ¨ ordnung der Buchstaben wurde das selbe Schema, wie es auch bei der Qlocktwo und vielen weiteren Wordclocks im Internet zu finden ist angewendet. Außerdem wurde eine Frontplatte erstellt, die es ermoglicht die Wordclock auch ¨
als Binaruhr zu verwenden. Hierf ¨ | ur muss nur ¨
die Software entsprechend angepasst werden. Da die Frontplatte idealerweise das licht nur an den Buchstaben das Licht durchlasst und ¨ dort leicht milchig sein sollte, gibt es verschiedene Moglichkeiten zum Erstellen der Platte. ¨ Die simpelste Moglichkeit ist dabei, das Layout ¨ der Frontplatte auf mehrere Overheadfolien zu drucken und diese mit einem Blatt Papier als Difusor gemeinsam zu lamineren. Problematisch ist hierbei allerdings die Verbindung der einzellenen Folien, da diese sich leicht lost. Bei ¨ der binaren Frontplatte wurden nur die Licht- ¨ durchlasse aus der Holzplatte ausgeschnitten, ¨ die hierfur verwendet wurde. Diese wurden ¨ anschließend von hinten mit Papier verklebt, sodass die LEDs durch dieses diffus hindurchleuchten. Als aufwendigste Methode wurde noch eine Akrylscheibe von hinten zuerst farbig und anschließend mehrfach schwarz lackiert aus der das in Illustrator erstellte Frontplattenlayout dann ausgraviert wurde. Die Schwarze Lackierung dient hierbei dazu, dass die LEDs nicht durch die farbigen Stellen der Frontplatte hindurchleuchten. Eine weitere, aber nicht erprobte Methode ware das Ausschneiden ei- ¨ ner Folie mit dem im Fablab verfugbaren Fo- ¨ lienplotter und das aufkleben dieser auf eine Milchglasscheibe. Alle Frontplatten sind mit einem Magnet an der Zwischenplatte befestigt, so wird kein Werkzeug zum Austauschen der Zwischenplatte benotigt. ¨

### 4 SOFTWARE

Die Software fur den Atmega168 wurde in ¨ Eclipse entwickelt. Der wesentliche Teil der Software ist die Ansteuerung der Matrix der 110 WS2812B LEDs. Dieser funktioniert uber ¨ ein spezielles Protokoll: die erste LED der Matrix bekommt einen Strom an bits vom Mikrokontroller. Von diesem Bitstrom schneidet die erste LED die ersten 24 bit ab und gibt alle weiteren ankommenden bits an die nachste LED ¨ weiter, die nach dem selben Prinzip verfahrt. ¨ Somit erhalt jede LED 24 bit, von denen jeweils ¨ 8 die Helligkeit der drei Farben Grun, Rot und ¨ Blau reprasentieren. ¨

### 5 AUSBLICK

DCF beschriftung der Taster mit Lasercutter Batterienbetrieben Da die Buchstaben einzeln ansteuerbar sind, besteht auch die Moglichkeit ¨ die Matrix fur noch weitere Anwendungen zu ¨ nutzen. So etwas termeratur anzeigen ; Datum Wochentag etc

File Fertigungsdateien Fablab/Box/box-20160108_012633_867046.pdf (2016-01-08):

Cut Width: 0.0000mm
Material Thickness: 2.0000mm
W x D x H: 135.00mm x 135.00mm x 23.00mm Produced by BoxMaker v2.0.1 on 01/08/2016 at 01:26:33 http://boxmaker.connectionlab.org




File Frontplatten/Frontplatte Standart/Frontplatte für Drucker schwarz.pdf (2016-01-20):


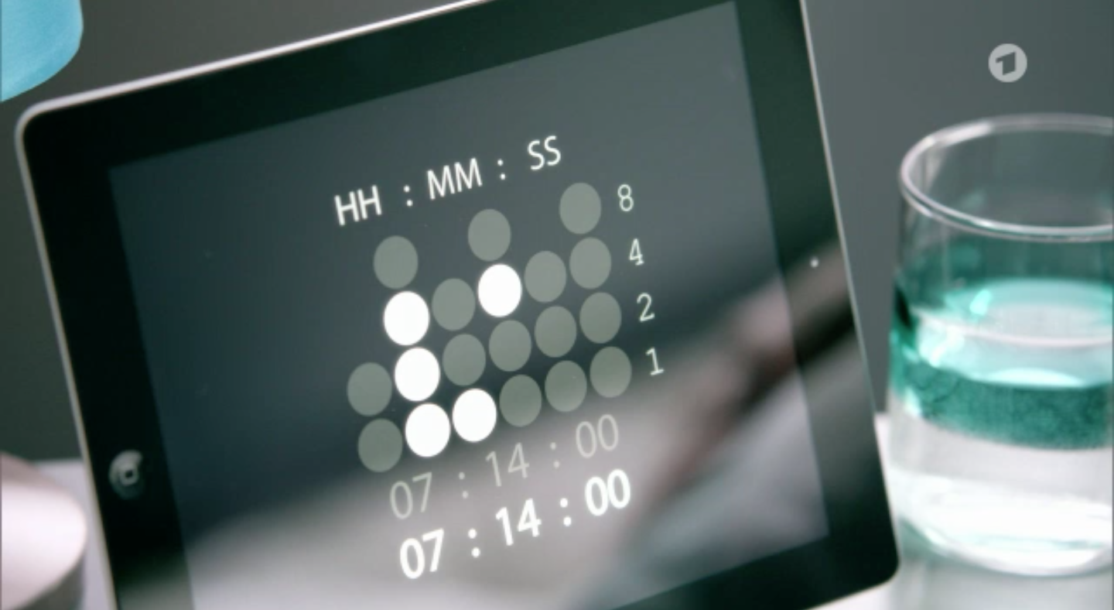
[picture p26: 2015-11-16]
Frontplatten/Frontplatte Binär/Binäruhr/Bildschirmfoto 2015-11-12 um 22.44.14.png

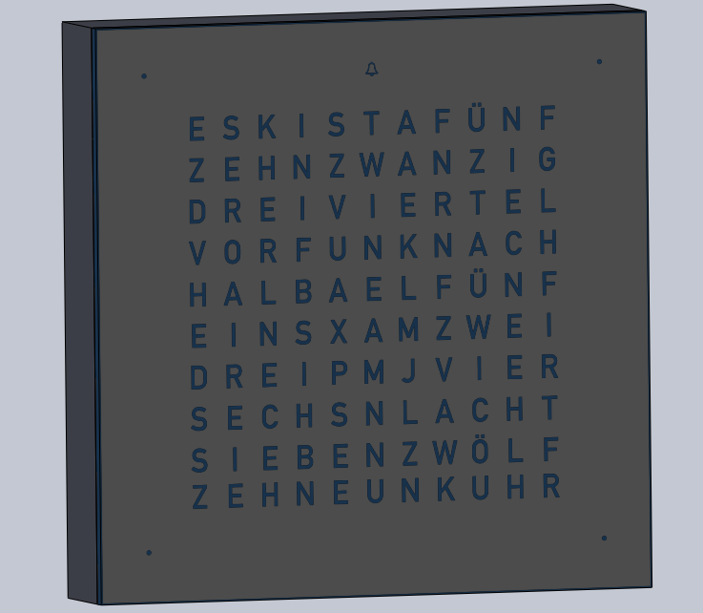
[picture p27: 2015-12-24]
CAD/Bilder/Bildschirmfoto 2015-12-24 um 15.15.45.png

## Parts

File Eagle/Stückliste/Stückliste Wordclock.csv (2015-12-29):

Qty | Value | Device | Package | Parts | Description | MF | MPN | OC_FARNELL | OC_NEWARK
5 |  | 10-XX | B3F-10XX | S1, S2, S3, S4, S5 | OMRON SWITCH |  | B3F-1000 | 176432 | 36M3542
4 |  | 2,54/1,1 | 2,54/1,1 | PAD1, PAD2, PAD3, PAD4 | THROUGH-HOLE PAD
1 |  | CRYSTALHC49S | HC49/S | Q2 | CRYSTAL |  |  | 1667008 | unknown
5 |  | LEDCHIPLED_1206 | CHIPLED_1206 | LED1, LED2, LED3, LED4, LEDAL | LED
1 |  | ML6L | ML6L | SV1 | HARTING |  |  | unknown | unknown
1 |  | R-EU_0204/5 | 0204/5 | LDR | RESISTOR, European symbol
1 | 0 | R-EU_M1206 | M1206 | BRIDGE_RESET1 | RESISTOR, European symbol
8 | 0 | R-EU_R1206 | R1206 | BRIDGE_GND, BRIDGE_INTB, BRIDGE_MOSI, BRIDGE_RESET2, BRIDGE_SCK, BRIDGE_VDD, R_SCL, R_SDA | RESISTOR, European symbol
2 | 100n | C-EUC0805 | C0805 | C119, C120 | CAPACITOR, European symbol
6 | 100n | C-EUC1206 | C1206 | C118, C_S1, C_S2, C_S3, C_S4, C_S5 | CAPACITOR, European symbol
110 | 100n | C-EUC1310 | C1310 | C1, C2, C3, C4, C5, C6, C7, C8, C9, C10, C11, C12, C13, C14, C15, C16, C17, C18, C19, C20, C21, C22, C23, C24, C25, C26, C27, C28, C29, C30, C31, C32, C33, C34, C35, C36, C37, C38, C39, C40, C41, C42, C43, C44, C45, C46, C47, C48, C49, C50, C51, C52, C53, C54, C55, C56, C57, C58, C59, C60, C61, C62, C63, C64, C65, C66, C67, C68, C69, C70, C71, C72, C73, C74, C75, C76, C77, C78, C79, C80, C81, C82, C83, C84, C85, C86, C87, C88, C89, C90, C91, C92, C93, C94, C95, C96, C97, C98, C99, C100, C101, C102, C103, C104, C105, C106, C107, C108, C109, C110 | CAPACITOR, European symbol
1 | 10k | R-EU_M1206 | M1206 | R_RESET | RESISTOR, European symbol
1 | 10u | L-EUL2012C | L2012C | L111 | INDUCTOR, European symbol
5 | 120 | R-EU_M1206 | M1206 | R_LED1, R_LED2, R_LED3, R_LED4, R_LEDAL | RESISTOR, European symbol
1 | 130 | R-EU_R1206 | R1206 | R_MOSFET | RESISTOR, European symbol
2 | 18p | C-EUC0805 | C0805 | C116, C117 | CAPACITOR, European symbol
5 | 1k | R-EU_M1206 | M1206 | R_S1, R_S2, R_S3, R_S4, R_S5 | RESISTOR, European symbol
1 | 300 | R-EU_R1206 | R1206 | R_MATRIXIN | RESISTOR, European symbol
1 | 32,768MHz | CRYSTALHC49S | HC49/S | Q_DS | CRYSTAL |  |  | 1667008 | unknown
4 | 4,7k | R-EU_R1206 | R1206 | PULLUP_INTA, PULLUP_INTB, PULLUP_SCL, PULLUP_SDA | RESISTOR, European symbol
1 | 49,9k | R-EU_M1206 | M1206 | R_PHOTO | RESISTOR, European symbol
1 | AL11P | AL11P | AL11P | SP1 | SPEAKER Source: Buerklin |  |  | unknown | unknown
1 | DS1337+ | DS1337+ | DIL8 | S+1 | DS1337 I2C serial real-time clock
1 | MEGA8-P | MEGA8-P | DIL28-3 | IC1 | MICROCONTROLLER |  |  | unknown | unknown
1 | MINI-USB | MINI-USB | MINI-USB | U$1 | Mini USB connector (Kyocera part: 24 5141 005 000 863+)
1 | SUP75N06-08 | SUP75N06-08 | TO220 | Q3 | N-Channel Enhancement MOSFET 60V; 75A; 0,008Ohm
110 | WS2812B | WS2812B | WS2812B | L1, L2, L3, L4, L5, L6, L7, L8, L9, L10, L11, L12, L13, L14, L15, L16, L17, L18, L19, L20, L21, L22, L23, L24, L25, L26, L27, L28, L29, L30, L31, L32, L33, L34, L35, L36, L37, L38, L39, L40, L41, L42, L43, L44, L45, L46, L47, L48, L49, L50, L51, L52, L53, L54, L55, L56, L57, L58, L59, L60, L61, L62, L63, L64, L65, L66, L67, L68, L69, L70, L71, L72, L73, L74, L75, L76, L77, L78, L79, L80, L81, L82, L83, L84, L85, L86, L87, L88, L89, L90, L91, L92, L93, L94, L95, L96, L97, L98, L99, L100, L101, L102, L103, L104, L105, L106, L107, L108, L109, L110

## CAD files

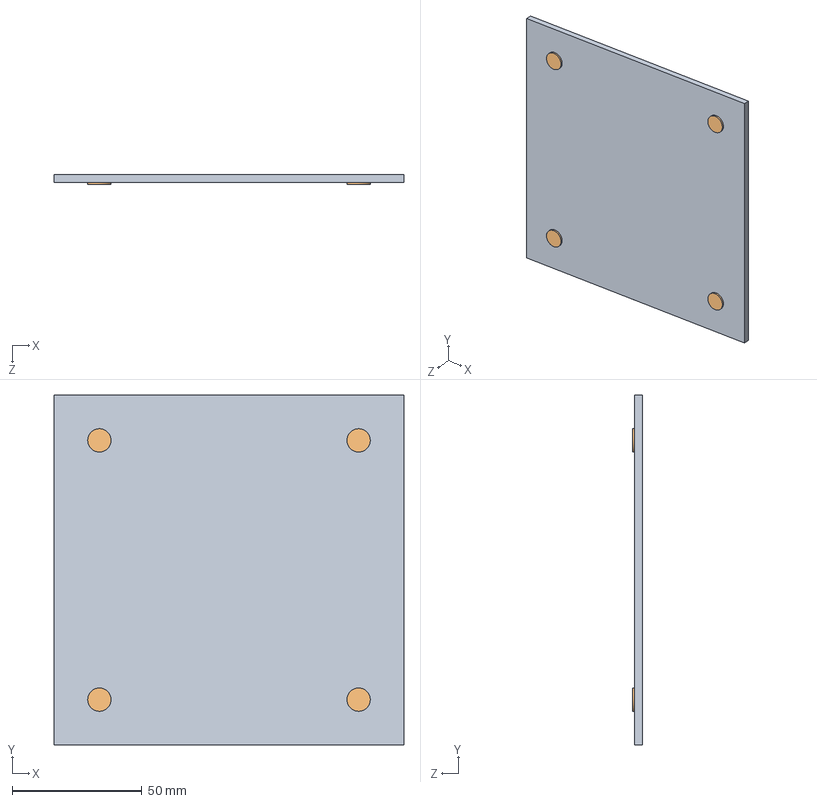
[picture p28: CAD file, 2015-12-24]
CAD/Frontplatte/Frontplatte.SLDASM
135.0 x 135.0 x 4.00 mm
Frontplatte
Magnetbefestigung x 4

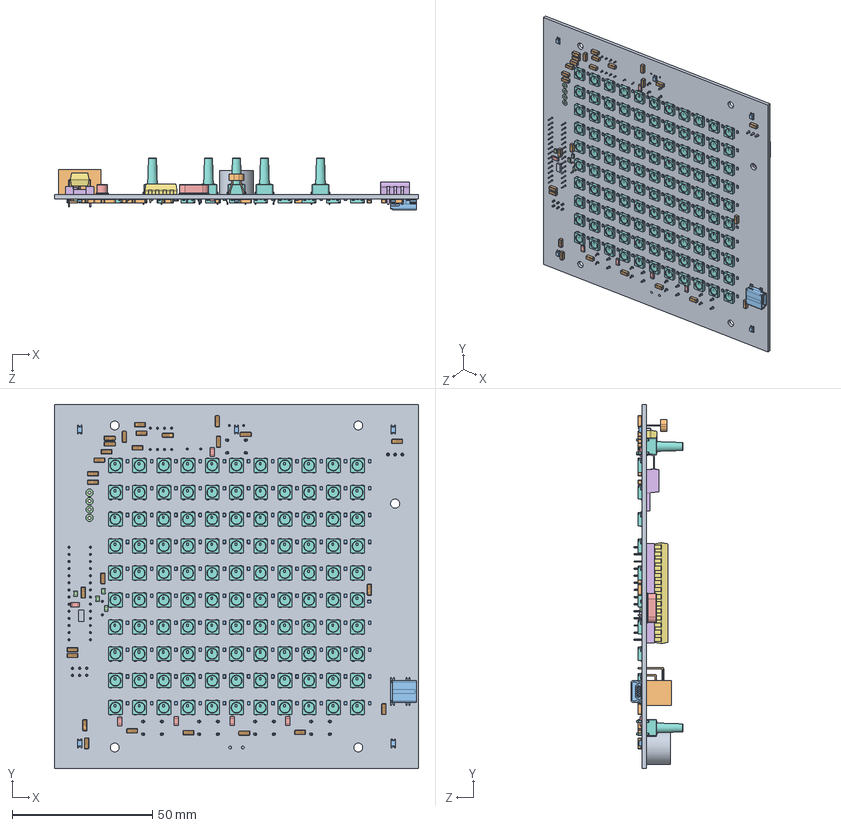
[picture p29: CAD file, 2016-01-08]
CAD/Platine/Platine.SLDASM
130.0 x 130.0 x 18.5 mm
wordclock
M1206 x 27
C1310 x 110
C0805 x 4
C1206 x 6
DIP28 Sockel
DIP28
WS2812 x 110
L2012C_L2012C
LDR
LED1206 x 5
HC49 x 2
TO220
DIP8
Taster x 5
Signalgeber
ISP Stecker
Mini USB

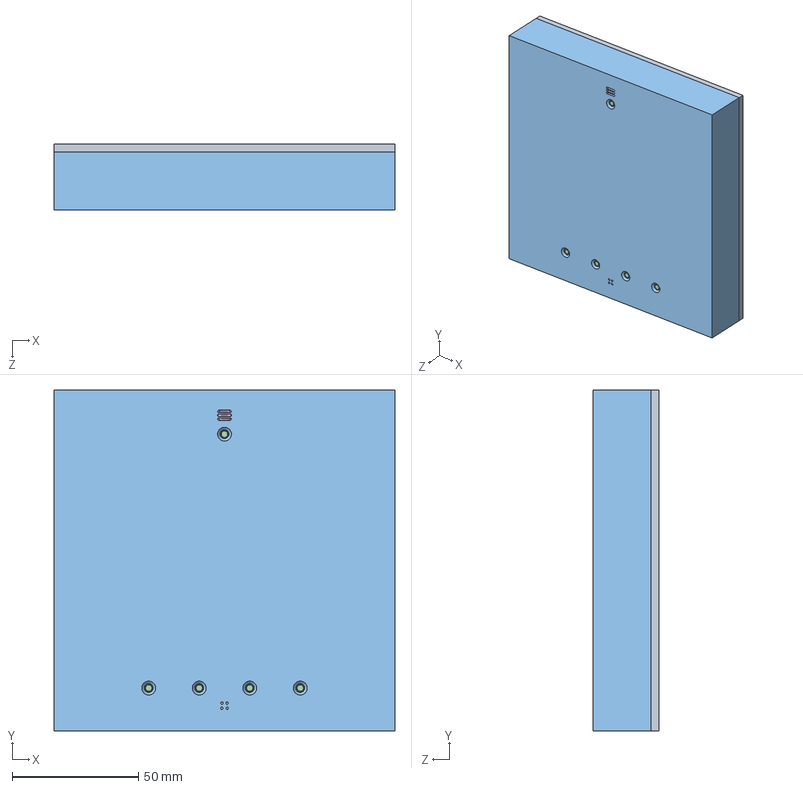
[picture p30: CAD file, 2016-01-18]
CAD/Wordclock.SLDASM
135.0 x 135.0 x 26.1 mm
GEhäuse
wordclock
M1206 x 27
C1310 x 110
C0805 x 4
C1206 x 6
DIP28 Sockel
DIP28
WS2812 x 110
L2012C_L2012C
LDR
LED1206 x 5
HC49 x 2
TO220
DIP8
Taster x 5
Signalgeber
ISP Stecker
Mini USB
Innensechskant M3x20 Meusburger x 4
Distanzhülse M3 x 4
Abstandshalter Plastik x 4

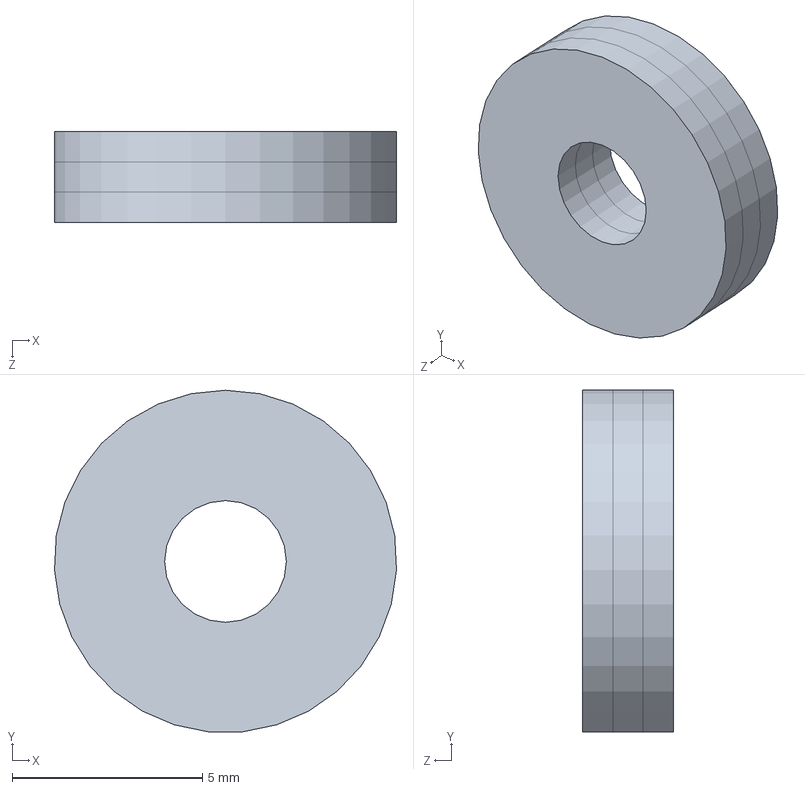
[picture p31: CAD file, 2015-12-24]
CAD/Normteile/din_en_iso_7093-1-3/Drei Beilagscheiben.SLDASM
8.99 x 8.98 x 2.40 mm
din_en_iso_7093-1-3 x 3

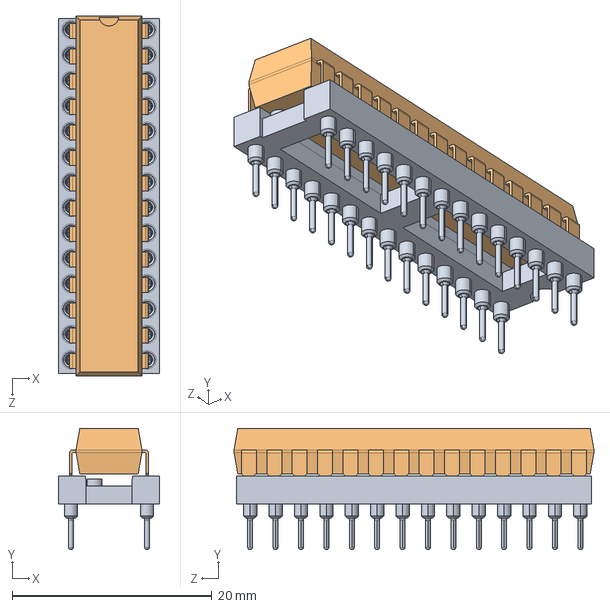
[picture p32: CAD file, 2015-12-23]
CAD/Platine/Bauteile/DIP28 inkl Sockel.SLDASM
10.1 x 12.1 x 36.0 mm
DIP28 Sockel
DIP28

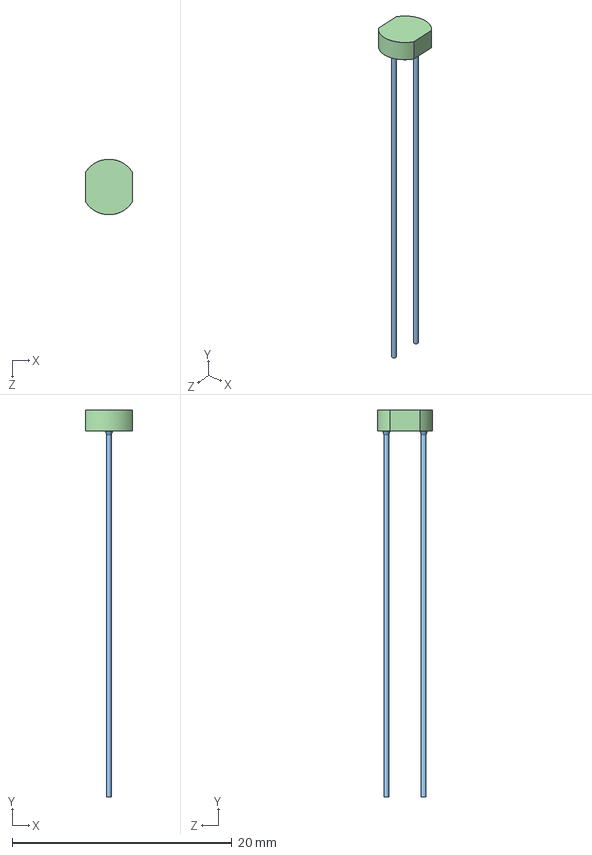
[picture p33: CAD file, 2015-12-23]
CAD/Platine/Bauteile/LDR.SLDASM
4.25 x 35.2 x 5.05 mm
Ceramic base^LDR cell thru-hole leaded
Electrodes^LDR cell thru-hole leaded
Leads^LDR cell thru-hole leaded
Part16^LDR cell thru-hole leaded

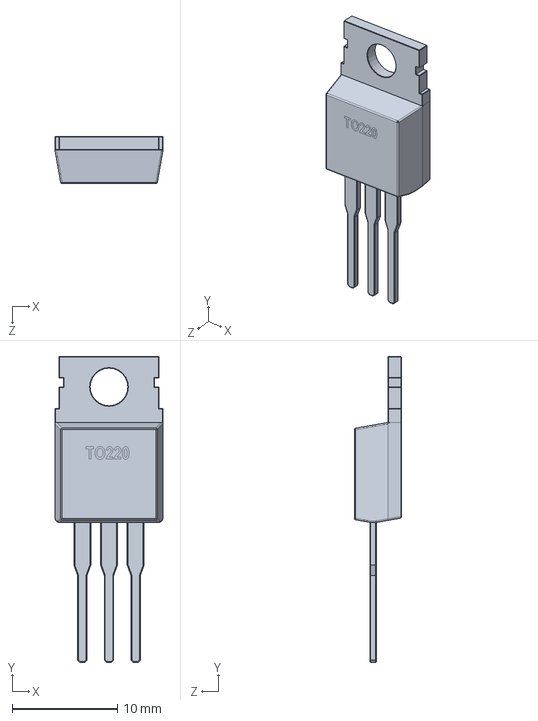
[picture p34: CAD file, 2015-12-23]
CAD/Platine/Bauteile/TO220.SLDASM
10.3 x 29.1 x 4.50 mm

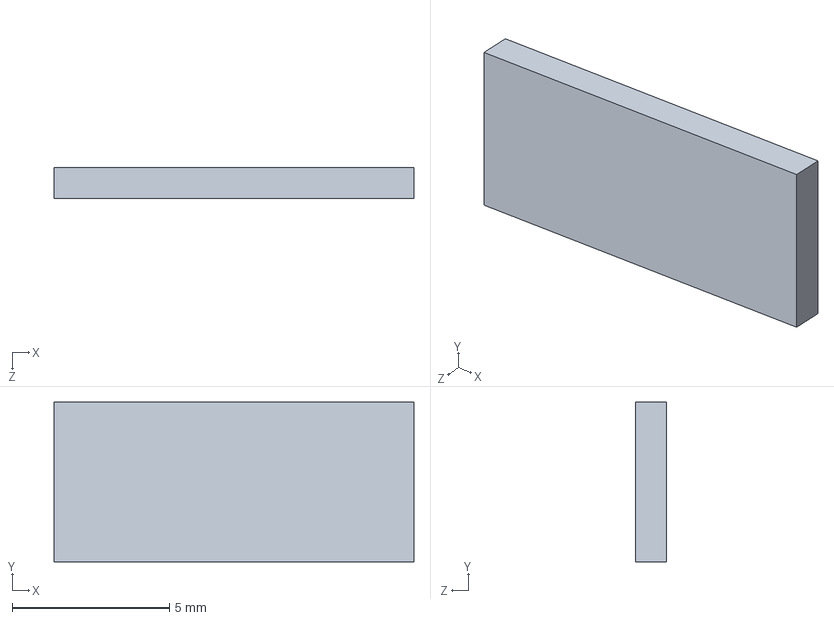
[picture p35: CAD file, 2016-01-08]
CAD/CircuitWorks/Komponenten/HC49_S_32_768MHZ.sldprt
11.4 x 5.08 x 1.00 mm

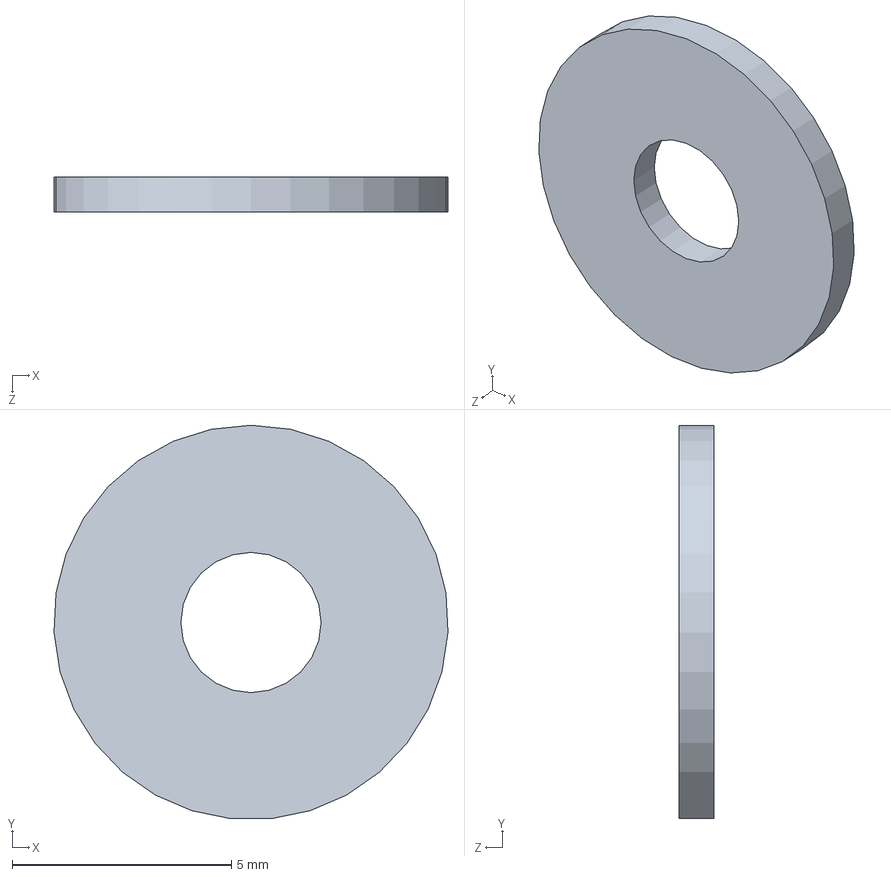
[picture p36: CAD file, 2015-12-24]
CAD/Normteile/din_en_iso_7093-1-3/din_en_iso_7093-1-3.SLDPRT
8.99 x 8.98 x 0.8 mm

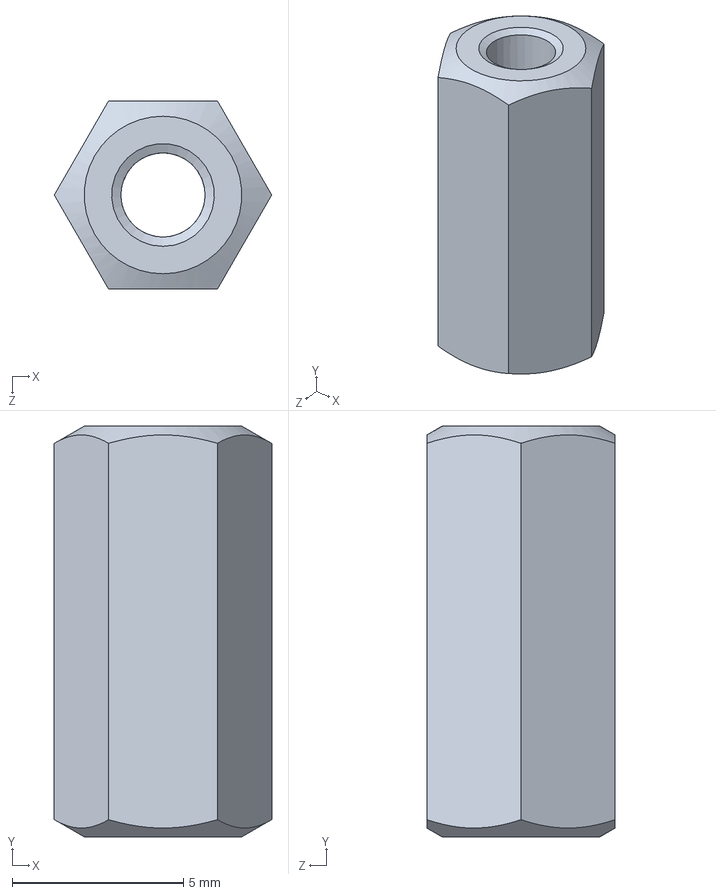
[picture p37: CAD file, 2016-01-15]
CAD/Normteile/Distanzhülse M3 Innengewinde/Distanzhülse M3.SLDPRT
6.35 x 12.0 x 5.50 mm

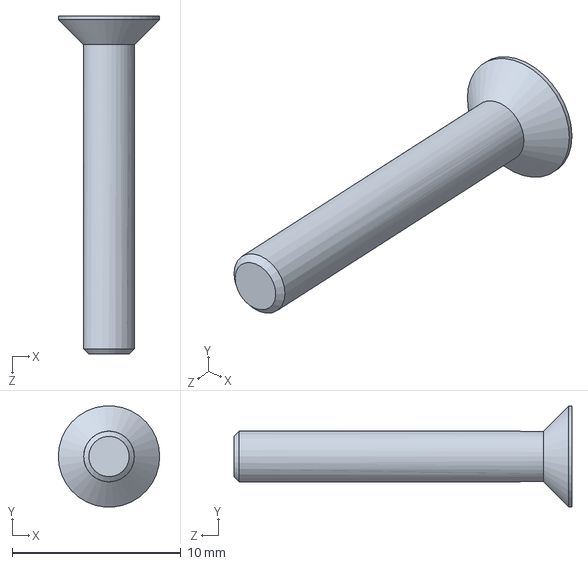
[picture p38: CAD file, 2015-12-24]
CAD/Normteile/Innensechskant M3x20 Meusburger.SLDPRT
6.00 x 5.97 x 20.0 mm

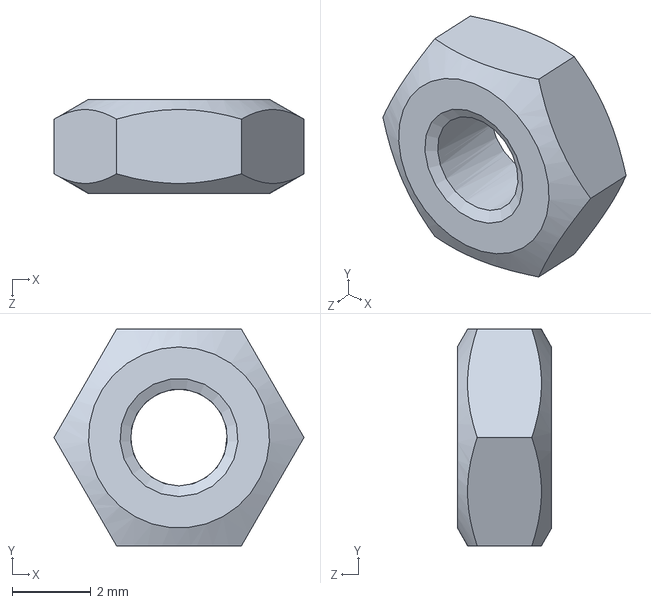
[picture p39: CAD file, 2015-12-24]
CAD/Normteile/mutter_din_en_24032-m3-6/mutter_din_en_24032-m3-6.SLDPRT
6.35 x 5.50 x 2.40 mm

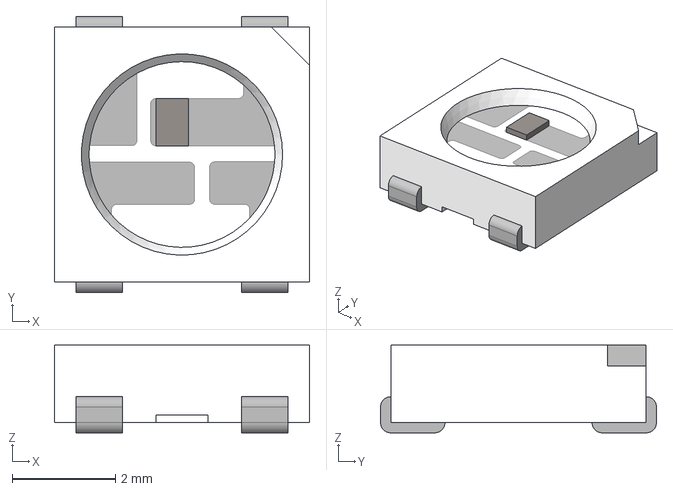
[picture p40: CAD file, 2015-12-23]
CAD/Platine/Bauteile/importiert/ws2812b-rgb-led-adafruit-neopixel-1.snapshot.9/WS2812_RGB_LED_updated.stp
4.95 x 5.35 x 1.70 mm

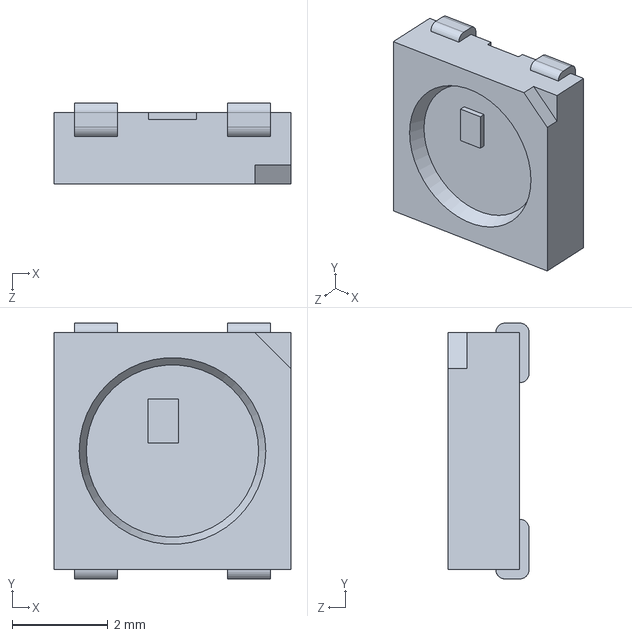
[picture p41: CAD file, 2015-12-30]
CAD/Platine/Bauteile/WS2812.SLDPRT
4.95 x 5.35 x 1.70 mm

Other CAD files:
CAD/CircuitWorks/Platinen/wordclock.sldprt
CAD/Platine/Bauteile/importiert/ldr-cell-5mm-1.snapshot.6/Electrodes^LDR cell thru-hole leaded.sldprt
CAD/Platine/Bauteile/importiert/to220-to220ab-1.snapshot.5/TO220.sldprt
Fertigungsdateien Fablab/Reflow/Schablone Lötpaste.dxf
CAD/Abstandshalter Plastik.SLDPRT
CAD/CircuitWorks/Komponenten/0204_5_0204_5.sldprt
CAD/CircuitWorks/Komponenten/2_54_1_1_PAD1_2_54_1_1.sldprt
CAD/CircuitWorks/Komponenten/2_54_1_1_PAD2_2_54_1_1.sldprt
CAD/CircuitWorks/Komponenten/2_54_1_1_PAD3_2_54_1_1.sldprt
CAD/CircuitWorks/Komponenten/2_54_1_1_PAD4_2_54_1_1.sldprt
CAD/CircuitWorks/Komponenten/AL11P_AL11P.sldprt
CAD/CircuitWorks/Komponenten/B3F10XX_S1_B3F10XX.sldprt
CAD/CircuitWorks/Komponenten/B3F10XX_S2_B3F10XX.sldprt
CAD/CircuitWorks/Komponenten/B3F10XX_S3_B3F10XX.sldprt
CAD/CircuitWorks/Komponenten/B3F10XX_S4_B3F10XX.sldprt
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

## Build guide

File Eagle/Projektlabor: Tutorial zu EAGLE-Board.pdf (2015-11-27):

Dieses Tutorial stellt die wichtigsten Schritte für die Benutzung von EAGLE-Board im Projektlabor vor. Eine ausführlichere Anleitung bietet unser Videokurs zu EAGLE-Board, (http://www.projektlabor.tu-berlin.de/menue/onlinekurs/platinenlayout/videotutorial_eagle-board/) der die Grundlagen anhand einer kompletten Beispielschaltung erklärt.

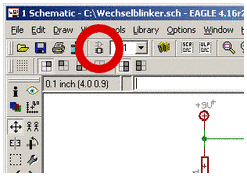
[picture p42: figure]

Umschalten von EAGLE-Schematic zu Board
© Projektlabor TUB

Schaltplan (Schematic) und Platinenlayout (Board) werden in unterschiedlichen Fenstern von EAGLE bearbeitet. Um vom Schematic zum Board zu wechseln, genügt ein Klick auf die Taste "Switch to board" in der Leiste oben im Fenster. Falls noch kein Board zum aktuellen Schematic existiert, fragt EAGLE an dieser Stelle nach, ob ein neues Board aus dem Schaltplan erstellt werden soll.

Im neu erstellten Board finden sich alle Bauteile aus dem Schematic wieder. Sie sind durch gelbe Linien (sogenannte Airwires) miteinander verbunden, an denen sie auch hängenbleiben, wenn man die Bauteile auf dem Board verschiebt oder rotiert. Außerdem wird automatisch der Umriß einer Platine erstellt.

Solange Schematic und zugehöriges Board parallel in jeweils einem eigenen Fenster geöffnet sind, werden Änderungen im einen Fenster automatisch ins andere übernommen. Fügt man beispielsweise neue Bauteile im Schematic ein, landen diese zeitgleich auch im Board.

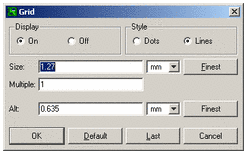
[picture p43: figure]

Rastereinstellungen in EAGLE-Board
© Projektlabor TUB

Die Werkzeugleiste befindet sich im Board ebenfalls am linken Rand des Fensters. Direkt über der großen Arbeitsfläche werden nach Auswahl eines Werkzeugs ggf. Auswahlmenüs angezeigt, mit denen sich Parameter für die Verwendung dieses Werkzeugs einstellen lassen.

Viel wichtiger als im Schematic ist das richtige Rastermaß im Board. Die Anschlüsse der Bauteile haben festgelegte Positionen und die Leiterbahnen können in EAGLE nur auf dem eingestellten Raster verlegt werden. Deshalb sollte das Raster auf jeden Fall stimmen, bevor man die Bauteile im Board bewegt. Die Voreinstellung von 1,27 mm (auf die richtig Einheit achten!) ist für den Anfang recht gut geeignet.

## Fakultät Elektrotechnik und Informatik

## Projektlabor

## Tutorial zu EAGLE-Board

## Umschalten von Schematic zu Board

## Oberfläche und Raster

Das Menü für die Rastereinstellung ist durch die Taste "Grid" direkt links über der Werkzeugleiste zu erreichen.

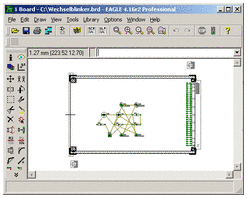
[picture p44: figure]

Busstecker in EAGLE-Board
© Projektlabor TUB

Falls die automatisch erzeugten Platinenumrisse nicht die richtigen Maße haben, können sie wie ganz normale Bauteile mit dem "Move"-Werkzeug verschoben werden.

Wir benutzen im Projektlabor für gewöhnlich Platinen im Europakartenformat (160×100 mm) zusammen mit einem 64-poligen Busstecker. Dieser Stecker existiert in EAGLE auch als Bauteil, welches praktischerweise Platinenumrisse und Bohrlöcher gleich mitbringt. Fügt also im Schematic den Busstecker ein (zu finden unter 19inch » VG64 » VG64P) und verbindet die entsprechend Pins mit dem Rest Eurer Schaltung. Der ansonsten automatisch erzeugte Platinenumriß im Board ist damit überflüssig und kann mit dem "Delete"-Werkzeug gelöscht werden.

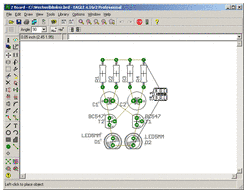
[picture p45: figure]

Plazierung der Bauteile in EAGLE-Board
© Projektlabor TUB

Nach dem Erstellen des Boards liegen alle Bauteile etwas verstreut neben der Platine. Sie können, genau wie im Schematic, mit dem "Move"-Werkzeug verschoben werden. Durch einen Linksklick mit diesem Werkzeug kann ein Bauteil ausgewählt werden und hängt danach direkt am Mauszeiger. Ein anschließender Rechtsklick dreht das Bauteil jeweils um 90 Grad gegen den Uhrzeigersinn. Mit einem erneuten Linksklick kann das Bauteil wieder abgesetzt werden.

Um mehrere Bauteile gemeinsam zu verschieben, können diese mit dem "Group"-Werkzeug als Gruppe markiert werden. Dazu muß die linke Maustaste gedrückt bleiben, während man einen Rahmen um die Bauteile zieht. Gruppen können danach mit dem "Move"-Werkzeug bewegt werden, indem sie mit der rechten Maustaste angeklickt werden (seit EAGLE 5 muß dabei noch die Taste Strg gedrückt werden). Auch hier ist ein anschließendes Rotieren durch Rechtsklick möglich. Abgesetzt wird die Gruppe wie gehabt durch einen Linksklick.

Die Bauelemente ordnet man am besten in funktionalen Baugruppen im Layout an, d. h. daß Bauteile, die in der Schaltung zu einem gemeinsamen Funktionsblock (z. B. ein Signalgenerator oder eine Verstärkerschaltung) gehören, auch möglichst gemeinsam auf der Platine plaziert werden. Der Schaltplan eignet sich dafür gut als Vorlage. Man kann ihn jederzeit über die Taste "Switch to schematic" vom Board aus aufrufen.

Die gelben Airwires zeigen stets an, welche Elemente an welchen Bauteilanschlüssen (Pins) miteinander verbunden sind. Beim Verschieben der Bauteile verhalten sich die Airwires wie Gummibänder. Oftmals ergibt

## Platinenmaße

## Bauelemente plazieren

sich durch eine neue Anordnung der Bauteile auf dem Board jedoch eine kürzere Verbindung zwischen den Pins. Durch einen Klick auf das Werkzeug "Ratsnest" werden die jeweils kürzesten Verbindungen berechnet. Beim Verschieben der Bauelemente sollte man diesen Knopf öfters drücken und dann weiterverschieben, bis die Schaltung möglichst übersichtlich ist.

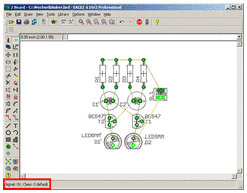
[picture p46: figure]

Hervorheben von Signalen in EAGLE-Board
© Projektlabor TUB

Mit dem "Show"-Werkzeug lassen sich einzelne Signalwege im Board farblich hervorheben. Ein Klick auf das entsprechende Airwire zeigt in der Statusleiste am unteren Bildschirmrand den Namen an, und alle damit verbundenen Pins und Airwires leuchten hell auf.

Um besonders in größeren Schaltungen ein bestimmtes Signal zu finden, kann die Kommandozeile benutzt werden. Um beispielsweise das Signal GND aufzuspüren, muß bloß die Anweisung "show gnd" eingetippt und mit Enter bestätigt werden. Auch hier werden die entsprechenden Airwires und Pins farblich hervorgehoben. Bei dieser Methode gibt es jedoch einen kleinen Haken, wenn man verschiedene Signale nacheinander sichtbar machen möchte: EAGLE löscht die farblichen Markierungen aus dem vorigen Schritt nicht automatisch. Bevor man also über die Kommandozeile das nächste "Show" absetzt, sollte mit einem Aufruf von "Ratsnest" (per Mausklick oder in der Kommandozeile) die Anzeige wieder löschen.

Ebenen ein- und ausblenden

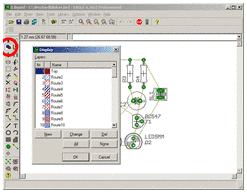
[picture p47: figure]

Ebenen in EAGLE-Board
© Projektlabor TUB

EAGLE legt Bauteile, Beschriftungen, Leiterbahnen usw. in unterschiedlichen Ebenen ("Layers") ab. Über die

Funktion "Display" können die verschiedenen Ebenen ein- und ausgeblendet werden, um bei der Arbeit die Übersicht nicht zu verlieren. Außerdem läßt sich auf diese Weise ziemlich einfach einstellen, welche Teile des Layouts beim Ausdrucken übernommen werden sollen.

Einige wichtige Ebenen für die Arbeit mit EAGLE-Board sind in der folgenden Tabelle aufgelistet:

Nr. | Name | Funktion
1 | Top | Leiterbahnen auf der Platinenoberseite (normalerweise die Bauteileseite)
16 | Bottom | Leiterbahnen auf der Platinenunterseite (normalerweise die Lötseite)
17 | Pads | Lötaugen der Bauelemente
18 | Vias | Durchkontaktierungen
19 | Unrouted | die Airwires

## Übersicht verloren?

20 | Dimension | Umrandung der Platine und der Bohrlöcher
21 | tPlace | Umriß der Bauelemente auf der Oberseite (Standard)
22 | bPlace | Umriß der Bauelemente auf der Unterseite
23 | tOrigins | Aufhängepunkte der Bauelemente auf der Oberseite (die kleinen Kreuze, über die sich die Bauelemente mit der Maus auswählen lassen)
24 | bOrigins | Aufhängepunkte der Bauelemente auf der Unterseite
25 | tNames | Namesbeschriftung der Bauelemente auf der Oberseite
26 | bNames | Namensbeschriftung der Bauelemente auf der Unterseite
27 | tValues | Wertebeschriftung der Bauelemente auf der Oberseite
28 | bValues | Wertebeschriftung der Bauelemente auf der Unterseite
116 | centerDrill | Verkleinerung der Bohrlöcher zum Zentrieren (erscheint erst, wenn das ULP Drill Aid bereits benutzt wurde)

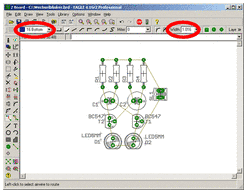
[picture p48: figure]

Leiterbahnparameter in EAGLE-Board
© Projektlabor TUB

Nachdem die Bauteile auf der Platine plaziert sind, fehlen noch die Leiterbahnen, um Verbindungen zwischen den Pins herzustellen. Dazu werden die Airwires mit dem "Route"-Werkzeug schrittweise durch Leiterbahnen ersetzt. Nach dem Aktivieren dieses Werkzeugs erscheinen in der Leiste über der Arbeitsfläche mehrere Auswahlmenüs, in denen Parameter für die Leiterbahnen festgelegt werden können. Interessant sind zunächst vor allem die Breite ("Width") der Leiterbahn und die Ebene ("Layer"), in der sie verlegt werden soll.

Für einfache Layouts werden die Bauteilebeinchen von der Platinenoberseite (Layer "Top") auf die -unterseite (Layer "Bottom") durchgesteckt und dort festgelötet. Die Leiterbahnen müssen in diesem Fall also im Layer "Bottom" verlegt werden und sollten vorerst eine Breite von 0,6 mm nicht unterschreiten.

Verlegen der Leiterbahnen

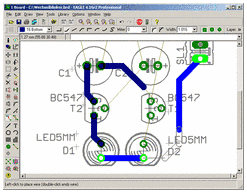
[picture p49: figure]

Manuelles Verlegen von Leiterbahnen in EAGLE-Board
© Projektlabor TUB

Mit diesen Einstellungen kann nun das eigentliche Routen beginnen. Ein Linksklick mit dem "Route"-Werkzeug auf ein Airwire erstellt eine Leiterbahn zwischen der aktuellen Mausposition und dem nächsten Pin an diesem Airwire. Diese Bahn wird allerdings erst dann wirklich verlegt, wenn entweder das Airwires komplett vom einen bis zum anderen Ende geroutet oder das Routen durch einen Doppelklick der

## Manuelles Routen

linken Maustaste beendet wurde. Davor werden lediglich die Umrisse der Leiterbahn angezeigt, und an diesem Punkt läßt sich deren Verlauf noch ändern. Durch mehrfache Rechtsklicks kann nämlich gewählt werden, ob die Leiterbahn rechtwinklig, gerade, rund usw. zwischen zwei Punkten verläuft. Statt das Routen einer Bahn mit einem Doppelklick vorzeitig abzubrechen, kann auch Escape auf der Tastatur gedrückt werden.

Benutzt man zwischen dem Verlegen einzelner Leiterbahnen "Ratsnest", erscheint in der Statusleiste unten links im Fenster die Anzahl der verbleibenden Airwires. Das kann ganz hilfreich sein, um in größeren Layouts sicherzugehen, daß man wirklich alle Bahnen fertig geroutet hat.

Korrekturen mit Ripup

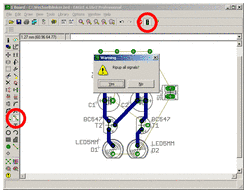
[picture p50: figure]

Entfernen von Leiterbahnen in EAGLE-Board
© Projektlabor TUB

Nicht immer werden die Leiterbahnen gleich im ersten Versuch so verlegt, wie sie später bleiben sollen. Um Korrekturen vorzunehmen, können Leiterbahnen mit dem "Ripup"-Werkzeug wieder in Airwires umge-wandelt werden. Ein einzelner Linksklick mit diesem Werkzeug auf eine Leiterbahn löscht nur das entsprechende Bahnsegment. Ein weiterer Linksklick auf das so enstandene Airwire entfernt auch die restlichen Segmente bis zu den nächsten angrenzenden Pins des Signals.

Falls einmal alle bereits verlegten Leiterbahnen in einem Board wieder entfernt werden sollen, ist zuerst wieder ein Klick auf "Ripup" nötig. Anschließend jedoch nicht auf die Leiterbahn klicken sondern auf die Ampel "GO" in der Menüleiste am oberen Bildschirmrand. EAGLE fragt sicherheitshalber nochmal nach, bevor die Aktion ausgeführt wird. Alternativ kann man auch einfach "ripup;" in die Kommandozeile eintragen und mit Enter ausführen.

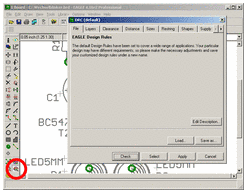
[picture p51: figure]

Der Design Rule Check in EAGLE-Board
© Projektlabor TUB

EAGLE bietet eine Menge Hilfsmittel an, die man auf jeden Fall nutzen sollte, um ein möglichst fehlerfreies Platinenlayout zu erstellen.

Neben dem Electrical Rule Check (ERC), der ja auch im Schematic vorhanden ist, existiert im Board noch der Design Rule Check (DRC). Mit dem DRC kann man das fertige Layout automatisch auf Designfehler untersuchen lassen. Dies können z. B. zu dünne Leiterbahnen sein oder zu geringe Abstände zwischen zwei Leiterbahnen. Die Einstellungen sind so vielfältig, daß man als Anfänger am besten die Voreinstellungen beibehält und einfach auf OK drückt. Die gefundenen Fehler werden dann in einer Liste aufgezählt und im Layout markiert. Man kann für jeden Fehler, den der DRC meldet, entscheiden, ob man ihn behebt oder einfach ignoriert. Über die Taste "Errors" kann man die Fehlerliste wieder aufrufen, falls man sie mal geschlossen hat.

Falls beim Durchlaufen des DRCs die Meldung "No Vector Font" auftaucht, weist Euch EAGLE auf mögliche Probleme hin, wenn keine Vektorschrift zur Beschriftung der Platine verwendet wurde. Siehe dazu auch der

## Fehlersuche im Board

Hinweis am Ende des Abschnitts Beschriftung. (http://www.projektlabor.tu-berlin.de/menue/onlinekurs/platinenlayout/tutorial_zu_eagle-board/#95727)

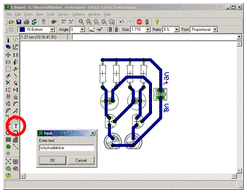
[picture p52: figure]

Platinenbeschriftung in EAGLE-Board
© Projektlabor TUB

Wenn das Layout soweit fertig und fehlerfrei ist, müssen nur noch die Steckverbindungen und die Platine sinnvoll beschriftet werden. Auch bei wichtigen Signalleitungen und Meßpunkten kann dies nicht schaden, da es später das Finden der Signale auf der Platine erleichtert.

Über das "Text"-Werkzeug läßt sich ein Textobjekt erstellen, welches wie ein Bauteil mit dem "Move"-Werkzeug auf der Platine verschoben und rotiert werden kann.

Neben der Schriftgröße kann in den Optionen auch die Schriftart gewählt werden. Zur Auswahl stehen: Vector, Proportional und Fixed. Empfehlenswert ist hier die Vektorschrift, da man mit dieser sichergehen kann, daß sie beim Ausdrucken des Layouts genauso aussieht wie auf dem Bildschirm. Für die anderen Schriftarten überläßt EAGLE dem Betriebsystem die Darstellung, was im ungünstigsten Fall dazu führt, daß die Schrift beim Exportieren für den Ausdruck breiter ist als auf dem Bildschirm und in irgendwelche Leiterbahnen ragt. Am besten direkt unter Options » User Interface die Option "Always vector font" aktivieren, um gar nicht erst Probleme mit der falschen Schriftart aufkommen zu lassen.

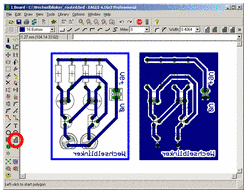
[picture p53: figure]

Polygon und Massefläche in EAGLE-Board
© Projektlabor TUB

In alle Bereichen der Platine, in denen keine Leiterbahnen, Pads usw. verlegt sind, löst das Ätzbad später die Kupferbeschichtung vom Platinenrohling. Um das Ätzbad zu schonen, sollte man jedoch nur so viel ätzen wie wirklich nötig.

Deshalb kann man in EAGLE-Board große leere Flächen im fertig gerouteten und beschrifteten Layout füllen lassen, indem man über das "Polygon"-Werkzeug sogenannte Masseflächen einfügt. Nach dem Aktivieren dieses Werkzeugs erscheinen in der Leiste über der Arbeitsfläche mehrere Auswahlmenüs, in denen Parameter für das Polygon festgelegt werden können. Neben der Ebene, in der das Polygon angelegt werden soll, sind folgende Einstellungen wichtig:

Name | Bedeutung | Empfohlener Wert
Width | Breite der Linien, mit denen das Polygon gefüllt wird | 0,5 mm
Pour | Füllmuster | Solid

## Beschriftung

## Massefläche erstellen

Thermals Pads über Thermalstege mit der Kupferfläche verbinden

On

Orphans Inseln ohne elektrische Verbindung zum Polygonsignal füllen

On

Isolate Abstand des Polygons zu anderen Bahnen und Pads

0,8 mm (nachher leichter zu löten, wenn größer)

Nachdem die Einstellungen für das Polygon vorgenommen wurden, zeichnet man einfach mit dem Werkzeug ein geschlossenes Rechteck um die Platine herum und gibt diesem mithilfe des "Name"-Werkzeuges den Namen des Massesignals in der Schaltung. EAGLE verbindet dann nach einer Rückfrage das Polygon
| mit dem Massesignal. Sichtbar wird die Massefläche nach einem Klick auf "Ratsnest".

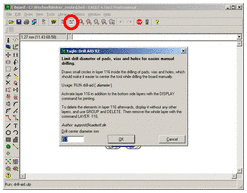
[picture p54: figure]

Zentrierlöcher mit Drill Aid in EAGLE-Board erstellen
© Projektlabor TUB

Die meisten Bauteile benötigen Löcher mit einem Durchmesser von 0,8 mm. Um später beim Bohren der Platinen besser die Mitte der Pads zu treffen, sollte man vor dem Ausdrucken des Layouts die Bohrlöcher verkleinern. Das Skript drill-aid.ulp nimmt einem diese Arbeit ab. Man kann es über die Taste "Run" auswählen und ausführen. Die Voreinstellung von 0,3 mm für den Durchmesser kann unverändert beibehalten werden.

Das Skript erzeugt dann die Zentrierlöcher in einer neuen Ebene namens centerDrill (Nummer 116). Sichtbar sind sie innerhalb von EAGLE-Board allerdings nur, wenn man einen schwarzen oder farbigen Hintergrund in der Arbeitsfläche verwendet. Auf dem Ausdruck sind sie bei aktiviertem Layer 116 aber auf jeden Fall zu sehen. Wer die Bohrlöcher vorher trotzdem kontrollieren möchte, kann die Hintergrundfarbe über den Menüpunkt Options » User Interface ändern.

Zuletzt aktualisiert: 08.01.13

## Downloads

Eagle herunterladen (http://www.projektlabor.tu-berlin.de/externe_links/eagle_herunterladen/)
EAGLE-Board Kurs zum download (http://www.projektlabor.tu-berlin.de/externe_links/onlinekurs/eagle-board_kurs_zum_download/)

Administrator des Onlinekurses E-Mail-Anfrage (http://www.tu-berlin.de/allgemeine_seiten/e-mail-anfrage/id/33343/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)

## Bohrhilfe einfügen

## Kontakt, Index und weiterer Service

## Kontakt, Inhaltsverzeichnis und weitere Service-Links

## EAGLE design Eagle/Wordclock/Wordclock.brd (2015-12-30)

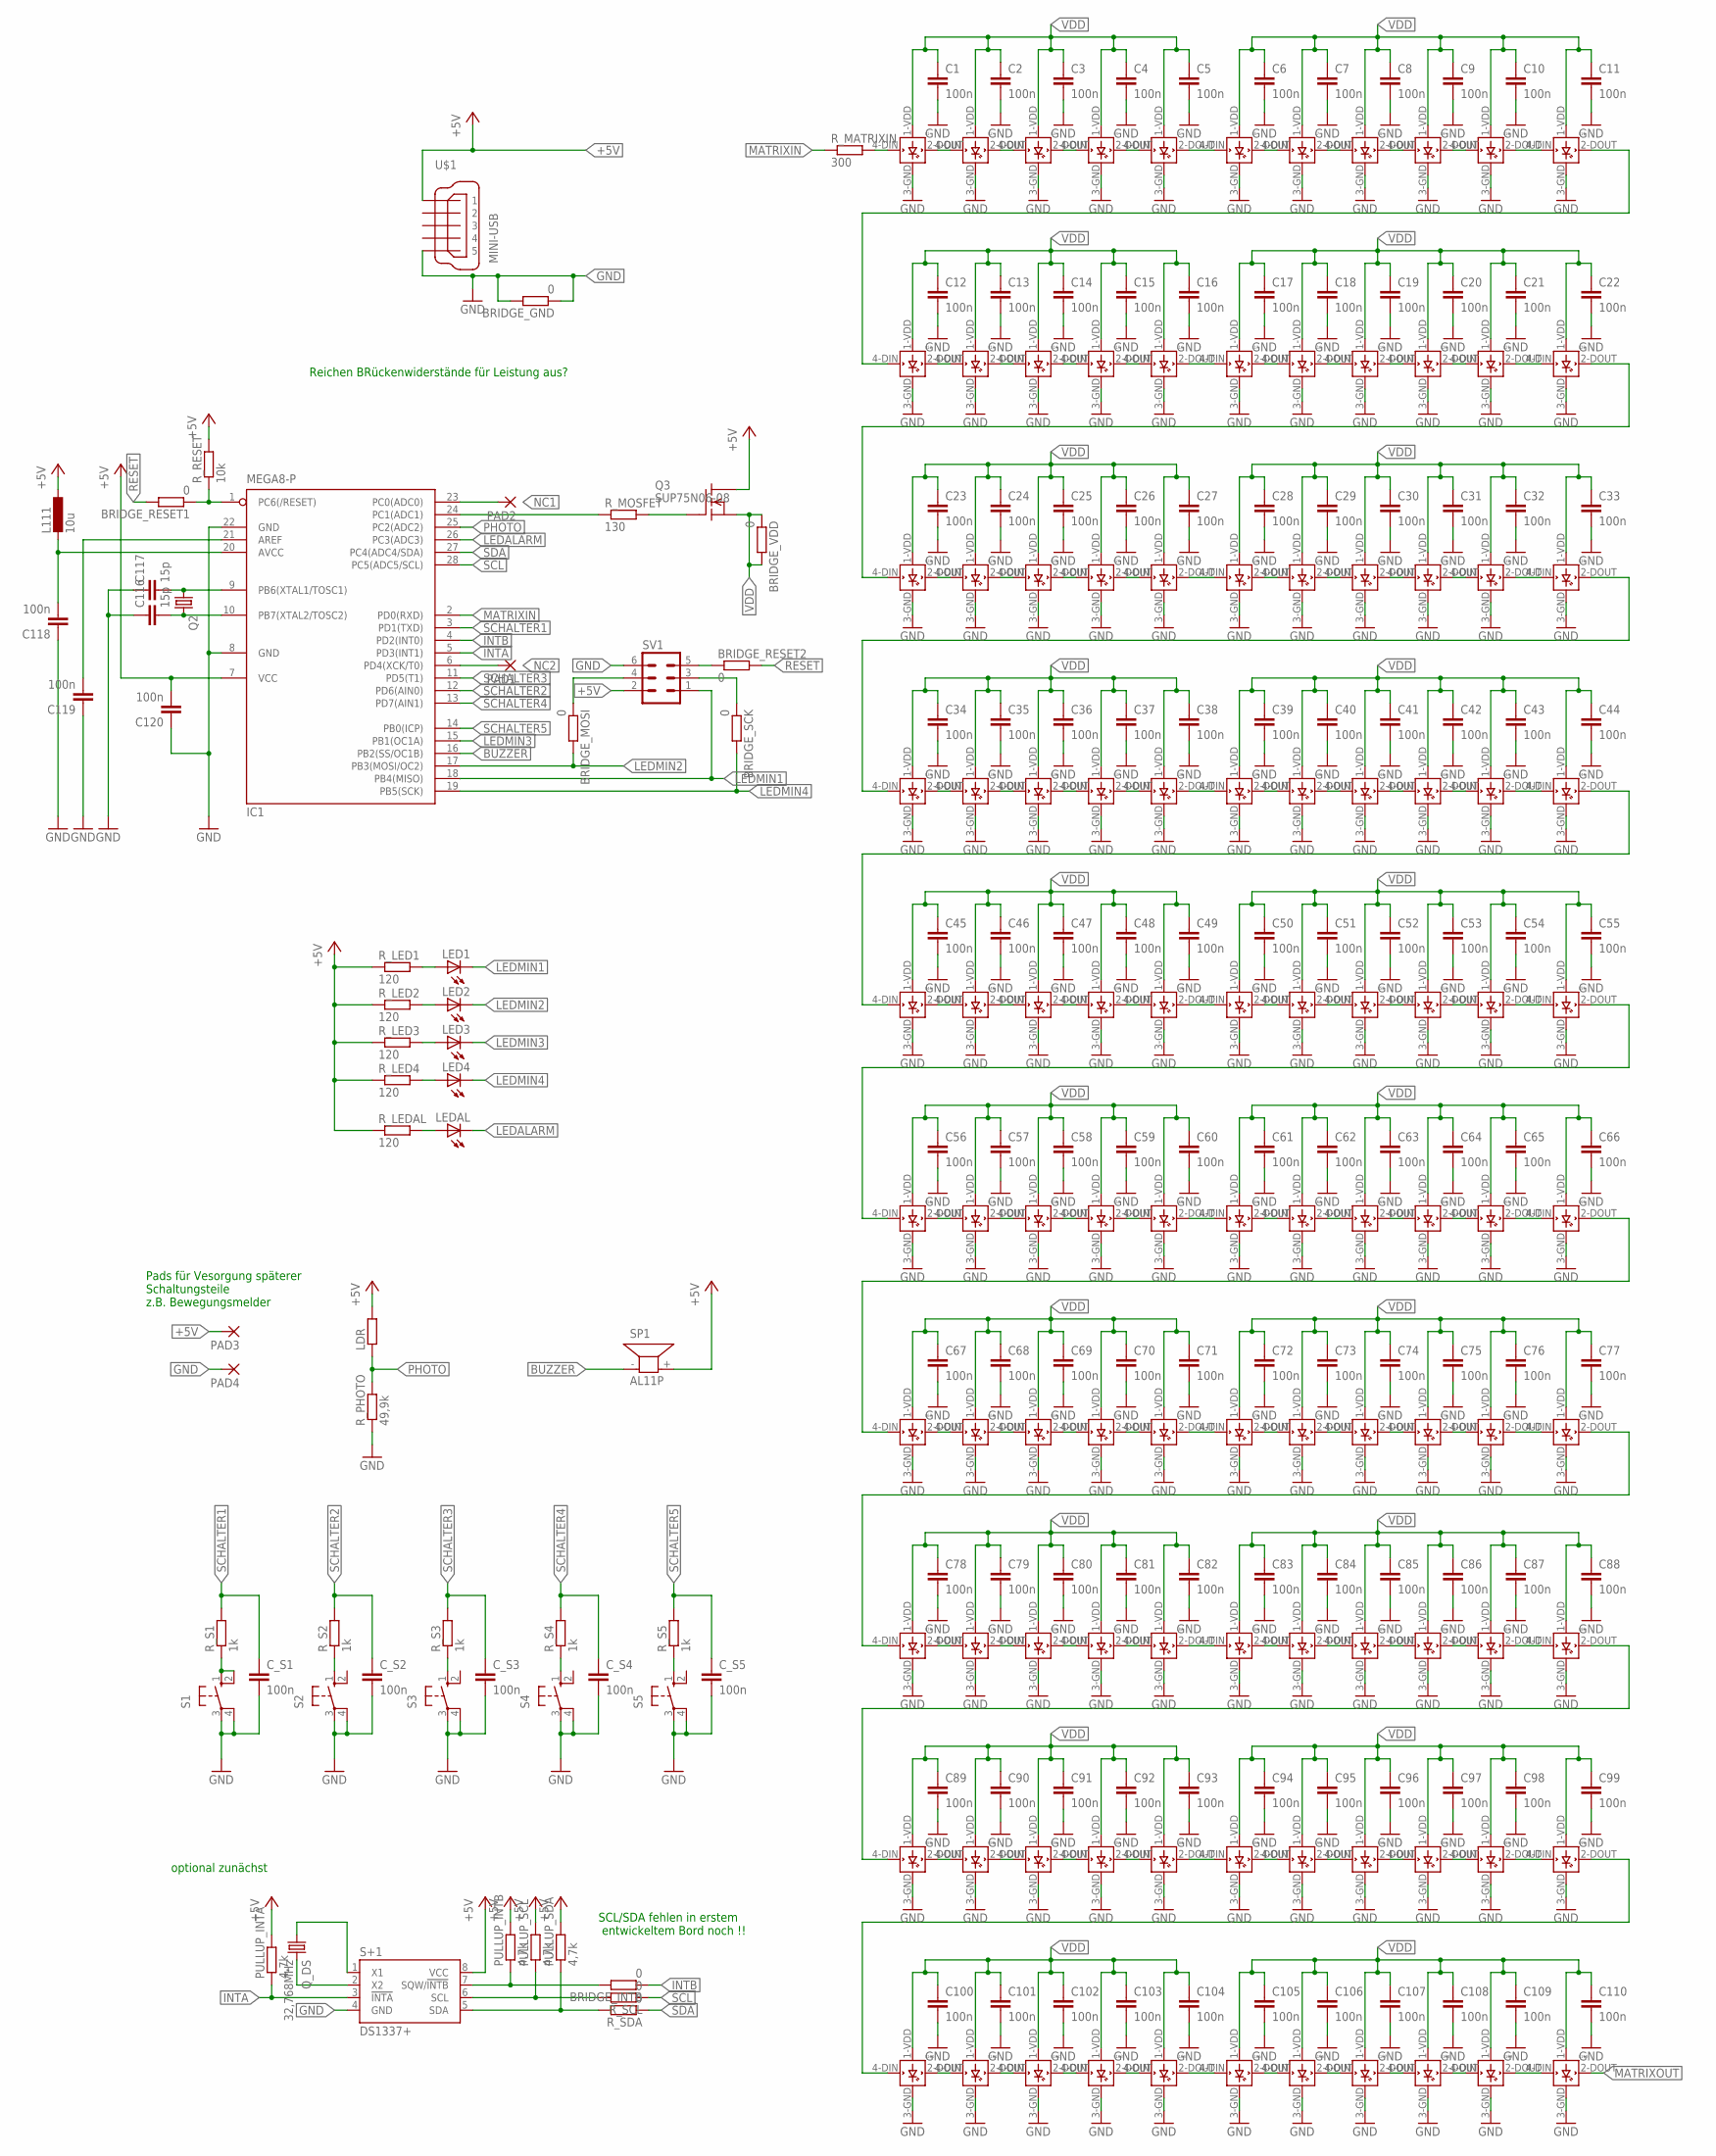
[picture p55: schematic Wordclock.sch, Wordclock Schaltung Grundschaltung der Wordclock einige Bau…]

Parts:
BRIDGE_GND: 0; R1206
BRIDGE_INTB: 0; R1206
BRIDGE_MOSI: 0; R1206
BRIDGE_RESET1: 0; M1206
BRIDGE_RESET2: 0; R1206
BRIDGE_SCK: 0; R1206
BRIDGE_VDD: 0; R1206
C1, C2, C3, C4, C5, C6, C7, C8, C9, C10, C11, C12, C13, C14, C15, C16, C17, C18, C19, C20, C21, C22, C23, C24, C25, C26, C27, C28, C29, C30, C31, C32, C33, C34, C35, C36, C37, C38, C39, C40, C41, C42, C43, C44, C45, C46, C47, C48, C49, C50, C51, C52, C53, C54, C55, C56, C57, C58, C59, C60, C61, C62, C63, C64, C65, C66, C67, C68, C69, C70, C71, C72, C73, C74, C75, C76, C77, C78, C79, C80, C81, C82, C83, C84, C85, C86, C87, C88, C89, C90, C91, C92, C93, C94, C95, C96, C97, C98, C99, C100, C101, C102, C103, C104, C105, C106, C107, C108, C109, C110: 100n; C1310
C116, C117: 15p; C0805
C118: 100n; C1206
C119, C120: 100n; C0805
C_S1, C_S2, C_S3, C_S4, C_S5: 100n; C1206
IC1: MEGA8-P; DIL28-3
L1, L2, L3, L4, L5, L6, L7, L8, L9, L10, L11, L12, L13, L14, L15, L16, L17, L18, L19, L20, L21, L22, L23, L24, L25, L26, L27, L28, L29, L30, L31, L32, L33, L34, L35, L36, L37, L38, L39, L40, L41, L42, L43, L44, L45, L46, L47, L48, L49, L50, L51, L52, L53, L54, L55, L56, L57, L58, L59, L60, L61, L62, L63, L64, L65, L66, L67, L68, L69, L70, L71, L72, L73, L74, L75, L76, L77, L78, L79, L80, L81, L82, L83, L84, L85, L86, L87, L88, L89, L90, L91, L92, L93, L94, L95, L96, L97, L98, L99, L100, L101, L102, L103, L104, L105, L106, L107, L108, L109, L110: WS2812B
L111: 10u; L2012C
LDR: R-EU_0204/5; 0204/5
LED1, LED2, LED3, LED4: LEDCHIPLED_1206; CHIPLED_1206
LEDAL: LEDCHIPLED_1206; CHIPLED_1206
PAD1, PAD2, PAD3, PAD4: 2,54/1,1
PULLUP_INTA: 4,7k; R1206
PULLUP_INTB: 4,7k; R1206
PULLUP_SCL: 4,7k; R1206
PULLUP_SDA: 4,7k; R1206
Q2: CRYSTALHC49S; HC49/S
Q3: SUP75N06-08; TO220
Q_DS: 32,768MHz; HC49/S
R_LED1, R_LED2, R_LED3, R_LED4: 120; M1206
R_LEDAL: 120; M1206
R_MATRIXIN: 300; R1206
R_MOSFET: 130; R1206
R_PHOTO: 49,9k; M1206
R_RESET: 10k; M1206
R_S1, R_S2, R_S3, R_S4, R_S5: 1k; M1206
R_SCL: 0; R1206
R_SDA: 0; R1206
S1, S2, S3, S4, S5: 10-XX; B3F-10XX
S+1: DS1337+; DIL8
SP1: AL11P
SV1: ML6L
U$1: MINI-USB

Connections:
+5V: C120.2, IC1.7 (VCC), L111.1, LDR.2, PAD3.1, PULLUP_INTA.2, PULLUP_INTB.2, PULLUP_SCL.2, PULLUP_SDA.2, Q3.2 (D), R_LED1.1, R_LED2.1, R_LED3.1, R_LED4.1, R_LEDAL.1, R_RESET.2, S+1.8 (VCC), SP1.+ (2), SV1.2, U$1.1
BUZZER: IC1.16 (PB2(SS/OC1B)), SP1.- (1)
GND: BRIDGE_GND.1, BRIDGE_GND.2, C1.2, C2.2, C3.2, C4.2, C5.2, C6.2, C7.2, C8.2, C9.2, C10.2, C11.2, C12.2, C13.2, C14.2, C15.2, C16.2, C17.2, C18.2, C19.2, C20.2, C21.2, C22.2, C23.2, C24.2, C25.2, C26.2, C27.2, C28.2, C29.2, C30.2, C31.2, C32.2, C33.2, C34.2, C35.2, C36.2, C37.2, C38.2, C39.2, C40.2, C41.2, C42.2, C43.2, C44.2, C45.2, C46.2, C47.2, C48.2, C49.2, C50.2, C51.2, C52.2, C53.2, C54.2, C55.2, C56.2, C57.2, C58.2, C59.2, C60.2, C61.2, C62.2, C63.2, C64.2, C65.2, C66.2, C67.2, C68.2, C69.2, C70.2, C71.2, C72.2, C73.2, C74.2, C75.2, C76.2, C77.2, C78.2, C79.2, C80.2, C81.2, C82.2, C83.2, C84.2, C85.2, C86.2, C87.2, C88.2, C89.2, C90.2, C91.2, C92.2, C93.2, C94.2, C95.2, C96.2, C97.2, C98.2, C99.2, C100.2, C101.2, C102.2, C103.2, C104.2, C105.2, C106.2, C107.2, C108.2, C109.2, C110.2, C116.1, C117.1, C118.1, C119.1, C120.1, C_S1.2, C_S2.2, C_S3.2, C_S4.2, C_S5.2, IC1.8 (GND), IC1.22 (GND), L1.3-GND (GND), L2.3-GND (GND), L3.3-GND (GND), L4.3-GND (GND), L5.3-GND (GND), L6.3-GND (GND), L7.3-GND (GND), L8.3-GND (GND), L9.3-GND (GND), L10.3-GND (GND), L11.3-GND (GND), L12.3-GND (GND), L13.3-GND (GND), L14.3-GND (GND), L15.3-GND (GND), L16.3-GND (GND), L17.3-GND (GND), L18.3-GND (GND), L19.3-GND (GND), L20.3-GND (GND), L21.3-GND (GND), L22.3-GND (GND), L23.3-GND (GND), L24.3-GND (GND), L25.3-GND (GND), L26.3-GND (GND), L27.3-GND (GND), L28.3-GND (GND), L29.3-GND (GND), L30.3-GND (GND), L31.3-GND (GND), L32.3-GND (GND), L33.3-GND (GND), L34.3-GND (GND), L35.3-GND (GND), L36.3-GND (GND), L37.3-GND (GND), L38.3-GND (GND), L39.3-GND (GND), L40.3-GND (GND), L41.3-GND (GND), L42.3-GND (GND), L43.3-GND (GND), L44.3-GND (GND), L45.3-GND (GND), L46.3-GND (GND), L47.3-GND (GND), L48.3-GND (GND), L49.3-GND (GND), L50.3-GND (GND), L51.3-GND (GND), L52.3-GND (GND), L53.3-GND (GND), L54.3-GND (GND), L55.3-GND (GND), L56.3-GND (GND), L57.3-GND (GND), L58.3-GND (GND), L59.3-GND (GND), L60.3-GND (GND), L61.3-GND (GND), L62.3-GND (GND), L63.3-GND (GND), L64.3-GND (GND), L65.3-GND (GND), L66.3-GND (GND), L67.3-GND (GND), L68.3-GND (GND), L69.3-GND (GND), L70.3-GND (GND), L71.3-GND (GND), L72.3-GND (GND), L73.3-GND (GND), L74.3-GND (GND), L75.3-GND (GND), L76.3-GND (GND), L77.3-GND (GND), L78.3-GND (GND), L79.3-GND (GND), L80.3-GND (GND), L81.3-GND (GND), L82.3-GND (GND), L83.3-GND (GND), L84.3-GND (GND), L85.3-GND (GND), L86.3-GND (GND), L87.3-GND (GND), L88.3-GND (GND), L89.3-GND (GND), L90.3-GND (GND), L91.3-GND (GND), L92.3-GND (GND), L93.3-GND (GND), L94.3-GND (GND), L95.3-GND (GND), L96.3-GND (GND), L97.3-GND (GND), L98.3-GND (GND), L99.3-GND (GND), L100.3-GND (GND), L101.3-GND (GND), L102.3-GND (GND), L103.3-GND (GND), L104.3-GND (GND), L105.3-GND (GND), L106.3-GND (GND), L107.3-GND (GND), L108.3-GND (GND), L109.3-GND (GND), L110.3-GND (GND), PAD4.1, R_PHOTO.1, S1.3, S1.4 (P1), S2.3, S2.4 (P1), S3.3, S3.4 (P1), S4.3, S4.4 (P1), S5.3, S5.4 (P1), S+1.4 (GND), SV1.6, U$1.5
INTA: IC1.5 (PD3(INT1)), PULLUP_INTA.1, S+1.3 (!INTA)
INTB: BRIDGE_INTB.1, IC1.4 (PD2(INT0))
INTB_UNBRIDGED: BRIDGE_INTB.2, PULLUP_INTB.1, S+1.7 (SQW/!INTB!)
LEDALARM: IC1.26 (PC3(ADC3)), LEDAL.C
LEDMIN1: IC1.18 (PB4(MISO)), LED1.C, SV1.1
LEDMIN2: BRIDGE_MOSI.2, IC1.17 (PB3(MOSI/OC2)), LED2.C
LEDMIN3: IC1.15 (PB1(OC1A)), LED3.C
LEDMIN4: BRIDGE_SCK.2, IC1.19 (PB5(SCK)), LED4.C
MATRIXIN: IC1.2 (PD0(RXD)), R_MATRIXIN.1
MATRIXOUT: L110.2-DOUT (DOUT)
MOSFET_A: IC1.24 (PC1(ADC1)), R_MOSFET.1
MOSFET_B: Q3.1 (G), R_MOSFET.2
unnamed: L1.2-DOUT (DOUT), L2.4-DIN (DIN)
unnamed: L2.2-DOUT (DOUT), L3.4-DIN (DIN)
unnamed: L3.2-DOUT (DOUT), L4.4-DIN (DIN)
unnamed: L4.2-DOUT (DOUT), L5.4-DIN (DIN)
unnamed: L6.2-DOUT (DOUT), L7.4-DIN (DIN)
unnamed: L5.2-DOUT (DOUT), L6.4-DIN (DIN)
unnamed: L7.2-DOUT (DOUT), L8.4-DIN (DIN)
unnamed: L8.2-DOUT (DOUT), L9.4-DIN (DIN)
unnamed: L9.2-DOUT (DOUT), L10.4-DIN (DIN)
unnamed: L10.2-DOUT (DOUT), L11.4-DIN (DIN)
unnamed: L12.2-DOUT (DOUT), L13.4-DIN (DIN)
unnamed: L13.2-DOUT (DOUT), L14.4-DIN (DIN)
unnamed: L14.2-DOUT (DOUT), L15.4-DIN (DIN)
unnamed: L15.2-DOUT (DOUT), L16.4-DIN (DIN)
unnamed: L16.2-DOUT (DOUT), L17.4-DIN (DIN)
unnamed: L17.2-DOUT (DOUT), L18.4-DIN (DIN)
unnamed: L18.2-DOUT (DOUT), L19.4-DIN (DIN)
unnamed: L19.2-DOUT (DOUT), L20.4-DIN (DIN)
unnamed: L20.2-DOUT (DOUT), L21.4-DIN (DIN)
unnamed: Q_DS.1, S+1.1 (X1)
unnamed: Q_DS.2, S+1.2 (X2)
unnamed: L21.2-DOUT (DOUT), L22.4-DIN (DIN)
unnamed: L23.2-DOUT (DOUT), L24.4-DIN (DIN)
unnamed: L24.2-DOUT (DOUT), L25.4-DIN (DIN)
unnamed: L25.2-DOUT (DOUT), L26.4-DIN (DIN)
unnamed: L26.2-DOUT (DOUT), L27.4-DIN (DIN)
unnamed: L27.2-DOUT (DOUT), L28.4-DIN (DIN)
unnamed: L28.2-DOUT (DOUT), L29.4-DIN (DIN)
unnamed: L29.2-DOUT (DOUT), L30.4-DIN (DIN)
unnamed: L30.2-DOUT (DOUT), L31.4-DIN (DIN)
unnamed: L31.2-DOUT (DOUT), L32.4-DIN (DIN)
unnamed: L32.2-DOUT (DOUT), L33.4-DIN (DIN)
unnamed: L34.2-DOUT (DOUT), L35.4-DIN (DIN)
unnamed: L35.2-DOUT (DOUT), L36.4-DIN (DIN)
unnamed: L36.2-DOUT (DOUT), L37.4-DIN (DIN)
unnamed: L37.2-DOUT (DOUT), L38.4-DIN (DIN)
unnamed: L38.2-DOUT (DOUT), L39.4-DIN (DIN)
unnamed: L39.2-DOUT (DOUT), L40.4-DIN (DIN)
unnamed: L40.2-DOUT (DOUT), L41.4-DIN (DIN)
unnamed: L41.2-DOUT (DOUT), L42.4-DIN (DIN)
unnamed: L42.2-DOUT (DOUT), L43.4-DIN (DIN)
unnamed: L43.2-DOUT (DOUT), L44.4-DIN (DIN)
unnamed: L45.2-DOUT (DOUT), L46.4-DIN (DIN)
unnamed: L46.2-DOUT (DOUT), L47.4-DIN (DIN)
unnamed: L47.2-DOUT (DOUT), L48.4-DIN (DIN)
unnamed: L48.2-DOUT (DOUT), L49.4-DIN (DIN)
unnamed: L49.2-DOUT (DOUT), L50.4-DIN (DIN)
unnamed: L50.2-DOUT (DOUT), L51.4-DIN (DIN)
unnamed: L51.2-DOUT (DOUT), L52.4-DIN (DIN)
unnamed: L52.2-DOUT (DOUT), L53.4-DIN (DIN)
unnamed: L53.2-DOUT (DOUT), L54.4-DIN (DIN)
unnamed: L54.2-DOUT (DOUT), L55.4-DIN (DIN)
unnamed: L56.2-DOUT (DOUT), L57.4-DIN (DIN)
unnamed: L57.2-DOUT (DOUT), L58.4-DIN (DIN)
unnamed: L58.2-DOUT (DOUT), L59.4-DIN (DIN)
unnamed: L59.2-DOUT (DOUT), L60.4-DIN (DIN)
unnamed: L60.2-DOUT (DOUT), L61.4-DIN (DIN)
unnamed: L61.2-DOUT (DOUT), L62.4-DIN (DIN)
unnamed: L62.2-DOUT (DOUT), L63.4-DIN (DIN)
unnamed: L63.2-DOUT (DOUT), L64.4-DIN (DIN)
unnamed: L64.2-DOUT (DOUT), L65.4-DIN (DIN)
unnamed: L65.2-DOUT (DOUT), L66.4-DIN (DIN)
unnamed: L67.2-DOUT (DOUT), L68.4-DIN (DIN)
unnamed: L68.2-DOUT (DOUT), L69.4-DIN (DIN)
unnamed: L69.2-DOUT (DOUT), L70.4-DIN (DIN)
unnamed: L70.2-DOUT (DOUT), L71.4-DIN (DIN)
unnamed: L71.2-DOUT (DOUT), L72.4-DIN (DIN)
unnamed: L72.2-DOUT (DOUT), L73.4-DIN (DIN)
unnamed: L73.2-DOUT (DOUT), L74.4-DIN (DIN)
unnamed: L74.2-DOUT (DOUT), L75.4-DIN (DIN)
unnamed: L75.2-DOUT (DOUT), L76.4-DIN (DIN)
unnamed: L76.2-DOUT (DOUT), L77.4-DIN (DIN)
unnamed: L78.2-DOUT (DOUT), L79.4-DIN (DIN)
unnamed: L79.2-DOUT (DOUT), L80.4-DIN (DIN)
unnamed: L80.2-DOUT (DOUT), L81.4-DIN (DIN)
unnamed: L81.2-DOUT (DOUT), L82.4-DIN (DIN)
unnamed: L82.2-DOUT (DOUT), L83.4-DIN (DIN)
unnamed: L83.2-DOUT (DOUT), L84.4-DIN (DIN)
unnamed: L84.2-DOUT (DOUT), L85.4-DIN (DIN)
unnamed: L85.2-DOUT (DOUT), L86.4-DIN (DIN)
unnamed: L86.2-DOUT (DOUT), L87.4-DIN (DIN)
unnamed: L87.2-DOUT (DOUT), L88.4-DIN (DIN)
unnamed: L89.2-DOUT (DOUT), L90.4-DIN (DIN)
unnamed: L90.2-DOUT (DOUT), L91.4-DIN (DIN)
unnamed: L91.2-DOUT (DOUT), L92.4-DIN (DIN)
unnamed: L92.2-DOUT (DOUT), L93.4-DIN (DIN)
unnamed: L93.2-DOUT (DOUT), L94.4-DIN (DIN)
unnamed: L94.2-DOUT (DOUT), L95.4-DIN (DIN)
unnamed: L95.2-DOUT (DOUT), L96.4-DIN (DIN)
unnamed: L96.2-DOUT (DOUT), L97.4-DIN (DIN)
unnamed: L97.2-DOUT (DOUT), L98.4-DIN (DIN)
unnamed: L98.2-DOUT (DOUT), L99.4-DIN (DIN)
unnamed: L100.2-DOUT (DOUT), L101.4-DIN (DIN)
unnamed: L101.2-DOUT (DOUT), L102.4-DIN (DIN)
unnamed: L102.2-DOUT (DOUT), L103.4-DIN (DIN)
unnamed: L103.2-DOUT (DOUT), L104.4-DIN (DIN)
unnamed: L104.2-DOUT (DOUT), L105.4-DIN (DIN)
unnamed: L105.2-DOUT (DOUT), L106.4-DIN (DIN)
unnamed: L106.2-DOUT (DOUT), L107.4-DIN (DIN)
unnamed: L107.2-DOUT (DOUT), L108.4-DIN (DIN)
unnamed: L108.2-DOUT (DOUT), L109.4-DIN (DIN)
unnamed: L109.2-DOUT (DOUT), L110.4-DIN (DIN)
unnamed: L11.2-DOUT (DOUT), L12.4-DIN (DIN)
unnamed: L22.2-DOUT (DOUT), L23.4-DIN (DIN)
unnamed: L33.2-DOUT (DOUT), L34.4-DIN (DIN)
unnamed: L44.2-DOUT (DOUT), L45.4-DIN (DIN)
unnamed: L55.2-DOUT (DOUT), L56.4-DIN (DIN)
unnamed: L66.2-DOUT (DOUT), L67.4-DIN (DIN)
unnamed: L77.2-DOUT (DOUT), L78.4-DIN (DIN)
unnamed: L88.2-DOUT (DOUT), L89.4-DIN (DIN)
unnamed: L99.2-DOUT (DOUT), L100.4-DIN (DIN)
unnamed: PULLUP_SCL.1, R_SCL.2, S+1.6 (SCL)
unnamed: C118.2, IC1.20 (AVCC), L111.2
unnamed: LED1.A, R_LED1.2
unnamed: LED2.A, R_LED2.2
unnamed: LED3.A, R_LED3.2
unnamed: LED4.A, R_LED4.2
unnamed: LEDAL.A, R_LEDAL.2
unnamed: R_S1.1, S1.1 (S), S1.2 (S1)
unnamed: R_S2.1, S2.1 (S)
unnamed: R_S3.1, S3.1 (S)
unnamed: R_S4.1, S4.1 (S)
unnamed: C119.2, IC1.21 (AREF)
unnamed: PULLUP_SDA.1, R_SDA.2, S+1.5 (SDA)
unnamed: BRIDGE_RESET1.1, IC1.1 (PC6(/RESET)), R_RESET.1
unnamed: R_S5.1, S5.1 (S)
unnamed: BRIDGE_MOSI.1, SV1.4
unnamed: BRIDGE_SCK.1, SV1.3
unnamed: BRIDGE_RESET2.1, SV1.5
unnamed: L1.4-DIN (DIN), R_MATRIXIN.2
unnamed: C117.2, IC1.9 (PB6(XTAL1/TOSC1)), Q2.1
unnamed: C116.2, IC1.10 (PB7(XTAL2/TOSC2)), Q2.2
NC1: IC1.23 (PC0(ADC0)), PAD2.1
NC2: IC1.6 (PD4(XCK/T0)), PAD1.1
PHOTO: IC1.25 (PC2(ADC2)), LDR.1, R_PHOTO.2
RESET: BRIDGE_RESET1.2, BRIDGE_RESET2.2
SCHALTER1: C_S1.1, IC1.3 (PD1(TXD)), R_S1.2
SCHALTER2: C_S2.1, IC1.12 (PD6(AIN0)), R_S2.2
SCHALTER3: C_S3.1, IC1.11 (PD5(T1)), R_S3.2
SCHALTER4: C_S4.1, IC1.13 (PD7(AIN1)), R_S4.2
SCHALTER5: C_S5.1, IC1.14 (PB0(ICP)), R_S5.2
SCL: IC1.28 (PC5(ADC5/SCL)), R_SCL.1
SDA: IC1.27 (PC4(ADC4/SDA)), R_SDA.1
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

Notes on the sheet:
optional zunächst
Reichen BRückenwiderstände für Leistung aus?
Pads für Vesorgung späterer Schaltungsteile z.B. Bewegungsmelder
SCL/SDA fehlen in erstem entwickeltem Bord noch !!

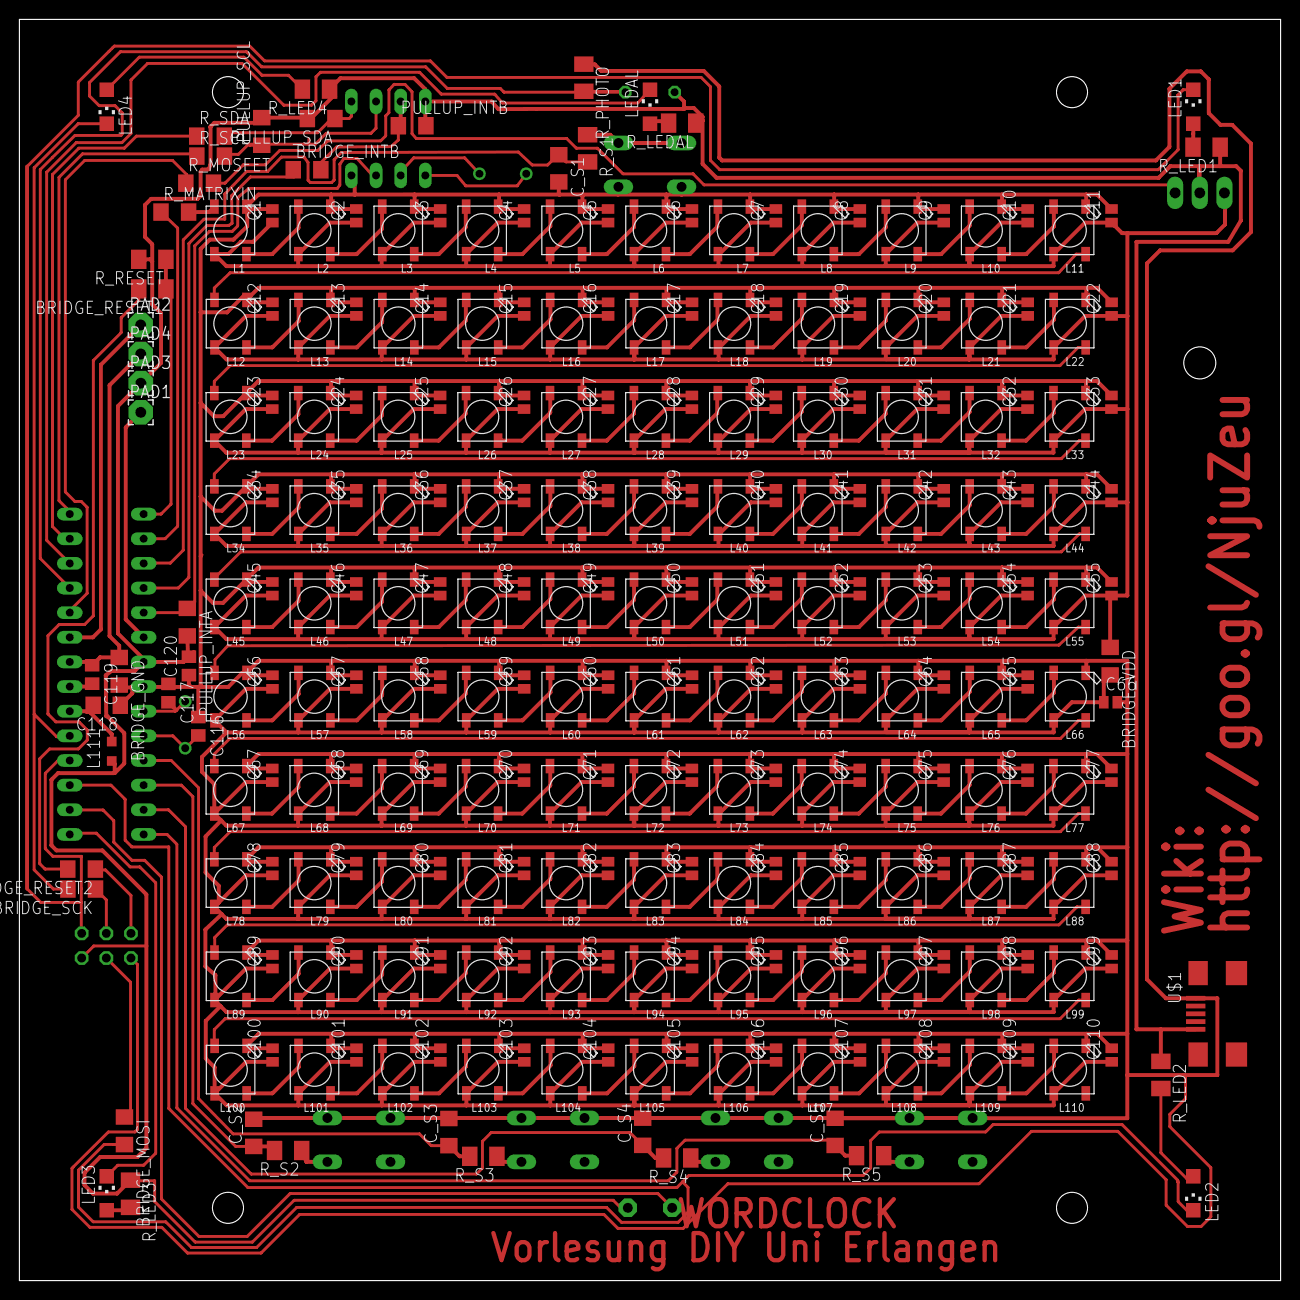
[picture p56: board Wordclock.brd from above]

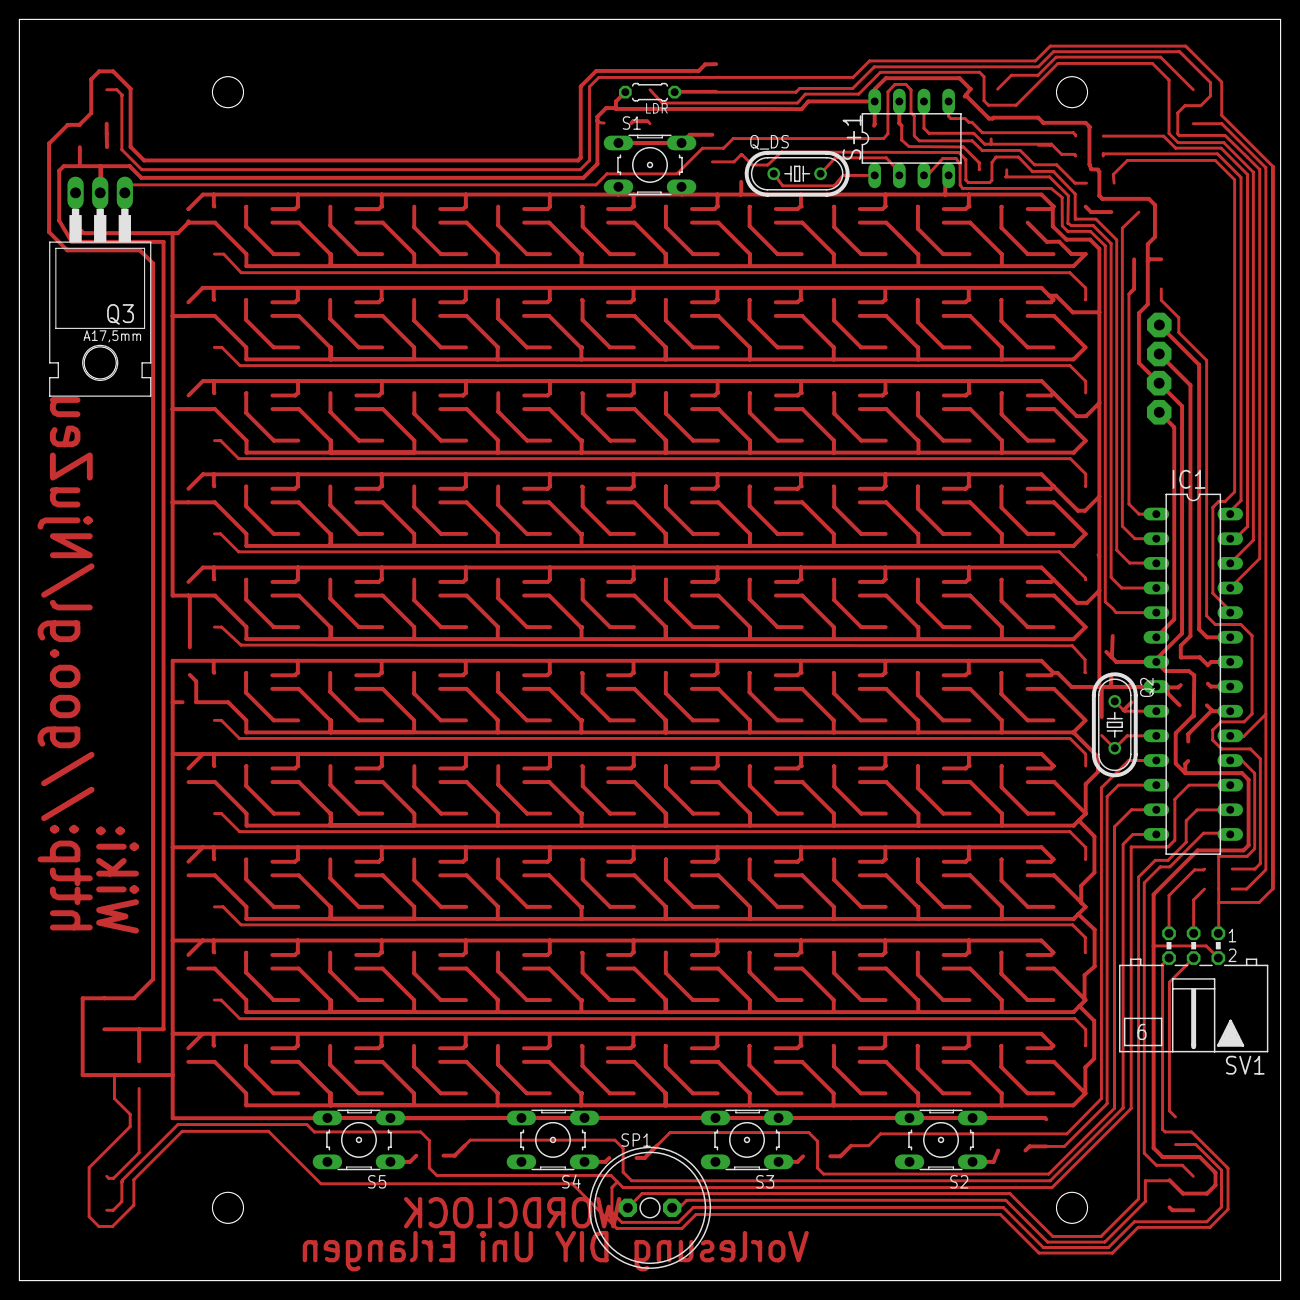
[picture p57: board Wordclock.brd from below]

Board: 2 copper layers, 130.0 x 130.0 mm, 281 parts (13 on the bottom side), 158 nets.

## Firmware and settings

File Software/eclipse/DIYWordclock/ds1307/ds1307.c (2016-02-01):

/*
ds1307 lib 0x01

copyright (c) Davide Gironi, 2013

Released under GPLv3.
Please refer to LICENSE file for licensing information.
*/


#include "avr/io.h"
#include "avr/pgmspace.h"
#include "util/delay.h"

#include "ds1307.h"

//path to i2c fleury lib
#include DS1307_I2CFLEURYPATH

/*
 * days per month
 */
const uint8_t ds1307_daysinmonth [] PROGMEM = { 31,28,31,30,31,30,31,31,30,31,30,31 };

/*
 * initialize the accellerometer
 */
void ds1307_init() {
	#if DS1307_I2CINIT == 1
	//init i2c
	i2c_init();
	_delay_us(10);
	#endif
}

/*
 * transform decimal value to bcd
 */
uint8_t ds1307_dec2bcd(uint8_t val) {
	return val + 6 * (val / 10);
}

/*
 * transform bcd value to deciaml
 */
static uint8_t ds1307_bcd2dec(uint8_t val) {
	return val - 6 * (val >> 4);
}

/*
 * get number of days since 2000/01/01 (valid for 2001..2099)
 */
static uint16_t ds1307_date2days(uint8_t y, uint8_t m, uint8_t d) {
	uint16_t days = d;
	for (uint8_t i = 1; i < m; ++i)
		days += pgm_read_byte(ds1307_daysinmonth + i - 1);
	if (m > 2 && y % 4 == 0)
		++days;
	return days + 365 * y + (y + 3) / 4 - 1;
}

/*
 * get day of a week
 */
uint8_t ds1307_getdayofweek(uint8_t y, uint8_t m, uint8_t d) {
	uint16_t day = ds1307_date2days(y, m, d);
	return (day + 6) % 7;
}

/*
 * set date
 */
uint8_t ds1307_setdate(uint8_t year, uint8_t month, uint8_t day, uint8_t hour, uint8_t minute, uint8_t second) {
	//sanitize data
	if (second < 0 || second > 59 ||
		minute < 0 || minute > 59 ||
		hour < 0 || hour > 23 ||
		day < 1 || day > 31 ||
		month < 1 || month > 12 ||
		year < 0 || year > 99)
		return 8;

	//sanitize day based on month
	if(day > pgm_read_byte(ds1307_daysinmonth + month - 1))
		return 0;

	//get day of week
	uint8_t dayofweek = ds1307_getdayofweek(year, month, day);

	//write date
	i2c_start_wait(DS1307_ADDR | I2C_WRITE);
	i2c_write(0x00);//stop oscillator
	i2c_write(ds1307_dec2bcd(second));
	i2c_write(ds1307_dec2bcd(minute));
	i2c_write(ds1307_dec2bcd(hour));
	i2c_write(ds1307_dec2bcd(dayofweek));
	i2c_write(ds1307_dec2bcd(day));
	i2c_write(ds1307_dec2bcd(month));
	i2c_write(ds1307_dec2bcd(year));
	i2c_write(0x00); //start oscillator
	i2c_stop();

	return 1;
}

/*
 * get date
 */
void ds1307_getdate(uint8_t *year, uint8_t *month, uint8_t *day, uint8_t *hour, uint8_t *minute, uint8_t *second) {
	i2c_start_wait(DS1307_ADDR | I2C_WRITE);
	i2c_write(0x00);//stop oscillator
	i2c_stop();

	i2c_rep_start(DS1307_ADDR | I2C_READ);
	*second = ds1307_bcd2dec(i2c_readAck() & 0x7F);
	*minute = ds1307_bcd2dec(i2c_readAck());
	*hour = ds1307_bcd2dec(i2c_readAck());
	i2c_readAck();
	*day = ds1307_bcd2dec(i2c_readAck());
	*month = ds1307_bcd2dec(i2c_readAck());
	*year = ds1307_bcd2dec(i2c_readNak());
	i2c_stop();
}

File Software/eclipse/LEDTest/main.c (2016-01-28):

/*
 * main.c
 *
 *  Created on: 18.01.2016
 *      Author: christofpfannenmuller
 */
#include <util/delay.h>
#include <avr/io.h>
#include <stdlib.h>
#include <avr/interrupt.h>

#include "light_ws2812.h"

#define t_alarm //TODO: EinfŸgen der Pins fŸr die Taster
#define t_up
#define t_down
#define t_snooze
#define t_mode
#define V_ON_B 0  //Wert fŸr LED on 0...255
#define V_ON_G 30  //Wert fŸr LED on 0...255
#define V_ON_R 0  //Wert fŸr LED on 0...255



struct cRGB matrix[10];
uint8_t stunden=1; //aktueller Stundenwert  1...12
uint8_t minuten=0; //aktueller Minutenwert  0...59
uint8_t frontplatte=0; //Art der Frontplatte; 0:Standartfrontplatte; 1:BinŠre Frontplatte; 2:Englische Frontplatte; ...
uint8_t matrix_on=1;

void setalarm(void){
	//get alarm time from user


	//send alarm time to RTC
}

void settime(void){

	//get time from user Zeit


	//send time to RTC

}

void showtime(uint8_t hours_to_show, uint8_t minutes_to_show){

	//beginn der Frontplattenansteuerung
	if(frontplatte==0){
		//Zeitanzeige fŸr Standart Frontplatte
		//Minutenleds
		PORTB |= (1<<PB5);PORTB |= (1<<PB4);PORTB |= (1<<PB3);PORTB |= (1<<PB1);//alle Minutenleds off
		switch(minutes_to_show%5) {//setzen entsprechende Minuten auf GND
			case 1: PORTB &=~ (1<<PB4); break;
			case 2: PORTB &=~ (1<<PB4)^(1<<PB3); break;
			case 3: PORTB &=~ (1<<PB4)^(1<<PB3)^(1<<PB1); break;
			case 4: PORTB &=~ (1<<PB4)^(1<<PB3)^(1<<PB1)^(1<<PB5); break;
		}





		/*
		//Leeren des Arrays
		for(uint8_t i=0; i<=110; i++){
			matrix[i].r=0;matrix[i].g=0;matrix[i].b=0;
		}
		//Ansteuerung der Matrix

				Vorlage:
				es ist ein uhr
				es ist fŸnf nach eins
				es ist zehn nach eins
				es ist viertel zwei
				es ist zehn vor halb zwei
				es ist fŸnf vor halb zwei
				es ist halb zwei
				es ist fŸnf nach halb zwei
				es ist zehn nach halb zwei
				es ist dreiviertel zwei
				es ist zehn vor zwei
				es ist fŸnf vor zwei
				*/


			//ES IST anschalten
		matrix[0].r=V_ON_R;matrix[0].g=V_ON_G;matrix[0].b=V_ON_B;
		matrix[1].r=V_ON_R;matrix[1].g=V_ON_G;matrix[1].b=V_ON_B;
		matrix[3].r=V_ON_R;matrix[3].g=V_ON_G;matrix[3].b=V_ON_B;
		matrix[4].r=V_ON_R;matrix[4].g=V_ON_G;matrix[4].b=V_ON_B;//TODO: ES IST darf nur dann angezeigt werden wenn es das auch soll
		matrix[5].r=V_ON_R;matrix[5].g=V_ON_G;matrix[5].b=V_ON_B;

		//TODO: Anpassen an die aktuellen Ports
		//Minuten anschalten

/*


			switch(((int) (minutes_to_show/5))*5) {
				case 0:PORTD|= (1<<7) ; break;  //x Uhr
				case 5:PORTB|= (1<<1);PORTB|= (1<<7); break; 										//5 nach x
				case 10:PORTB|= (1<<3);PORTB|= (1<<7) ; break; 										//10 nach x
				case 15:PORTB|= (1<<6); hours_to_show++ ; break;      								//viertel x+1
				case 20:PORTB|= (1<<3); PORTA|= (1<<0); PORTA|= (1<<1);hours_to_show++ ; break; 	//zehn vor halb x+1
				case 25:PORTB|= (1<<1); PORTA|= (1<<0); PORTA|= (1<<1);hours_to_show++  ; break;	//fünf vor halb x+1
				case 30:PORTA|= (1<<1);hours_to_show++  ; break; 									//halb x+1
				case 35:PORTB|= (1<<1); PORTB|= (1<<7); PORTA|= (1<<1);hours_to_show++  ; break; 	//fŸnf nach halb x+1
				case 40:PORTB|= (1<<3); PORTB|= (1<<7); PORTA|= (1<<1);hours_to_show++  ; break; 	//fŸnf nach halb x+1
				case 45:PORTB|= (1<<5); PORTB|= (1<<6);hours_to_show++ ; break; 					//dreiviertel x+1
				case 50:PORTB|= (1<<3); PORTA|= (1<<0);hours_to_show++ ; break; 					//zehn vor x+1
				case 55:PORTB|= (1<<1); PORTA|= (1<<0);hours_to_show++ ; break; 					//fŸnf vor x+1
			}
			if (hours_to_show>=13){hours_to_show=1;}
			switch (hours_to_show){
				case 1:	PORTA|= (1<<4);PORTA|= (1<<5);PORTA|= (1<<6);break; 						//EINS
				case 2: PORTA|= (1<<3);PORTA|= (1<<4);break;  										//ZWEI
				case 3: PORTC|= (1<<7);break; 														//DREI
				case 4: PORTC|= (1<<3);break; 														//VIER
				case 5: PORTC|= (1<<6);break; 														//F†NF
				case 6: PORTC|= (1<<0);break; 														//SECHS
				case 7: PORTA|= (1<<6);PORTA|= (1<<7);break;  										//SIEBEN
				case 8: PORTC|= (1<<2);break;														//ACHT
				case 9: PORTC|= (1<<4);break;														//NEUN
				case 10: PORTC|= (1<<1);break;														//ZEHN
				case 11: PORTC|= (1<<5);break;														//ELF
				case 12: PORTA|= (1<<2);break;														//ZW…LF
			}



			*/


	}else if(frontplatte==1){
		//Zeitanzeige fŸr BinŠre Frontplatte
	}else if(frontplatte==2){
		//Zeitanzeige fŸr Englische Frontplatte
	}
	//Ende der Frontplattenansteuerung

	if(matrix_on){
		PORTC &= ~ (1<<1);							//TODO:Mosfet anschalten

		ws2812_setleds(matrix,10);

		}else{
									//TODO:Mosfet ausschalten
		}
}

void change_frontplatte(uint8_t new_frontplatte){
	frontplatte=new_frontplatte;
}

void init(void){
	//in outputs intit
	//minutenleds + alarmLed
	//setze bit 1 =Ausgang
		DDRB |= (1<<1);
		DDRB |= (1<<3);
		DDRB |= (1<<4);
		DDRB |= (1<<5);
		DDRC |= (1<<3);//AlarmLED
		// setze pin auf vdd = LED aus
		PORTB |= (1<<1);
		PORTB |= (1<<3);
		PORTB |= (1<<4);
		PORTB |= (1<<5);
		PORTC |= (1<<3);//AlarmLED

		//Buzzer als Ausgang setzen und auf +5V schalten = ausgeschaltet
		DDRB |= (1<<2);
		PORTB |= (1<<2);

}

int main(void){
	//itialisierung
	init();
	//settime();//get time from user
	//setalarm();

	//mosefet leitet: // ------------------------------------------hier war ich
		//DDRC |= (1<<1);
		//PORTC |= (1<<1);

/*
	while(1){
		_delay_ms(1000);
		PORTB |= (1<<PB3);
		PORTB |= (1<<PB2);
		_delay_ms(1000);
		PORTB &= ~ (1<<PB3);
		PORTB &= ~ (1<<PB2);

	}
*/


	while(1){//Dauerablauf
		showtime(stunden, minuten);

		//Uhrzeit erhšhen testweise
		_delay_ms(1000);
		minuten++;
		if(minuten>=60){minuten=0;stunden++;}
		if(stunden>=13){stunden=1;}
		//ende Uhrzeit Testweise erhšhen

	}
}

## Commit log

2015-11-06 Beginn CAD Design
    [Frontplatte.SLDASM, Frontplatte.SLDPRT, Magnetbefestigung.sldprt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]
2015-11-06 Frontplatte erstellt
    [Wordclock.SLDASM]
2015-11-06 Gehäuse erstellt
    Gehäuse erstellt, Wanddicke und Tiefe können nachträglich geändert
    werden
    [GEhäuse.sldprt, Wordclock.SLDASM]
2015-11-06 Zwischenplatte erstellt
    [GEhäuse.sldprt, Wordclock.SLDASM, Zwischenplatte.sldprt]
2015-11-06 Pflichtenheft strukturiert
    [Wordclock.SLDASM]
2015-11-09 Ideen zu Interrupts für Ansteuerung hinzugefügt
    [Wordclock.SLDASM, Zwischenplatte.sldprt]
2015-11-16 Erste Versuche in Eagle
    [Wordclock.brd, Wordclock.sch]
2015-11-16 CAD Zwischenplatte angepasst
    [Frontplatte.SLDASM, Frontplatte.SLDPRT, Magnetbefestigung.sldprt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]
2015-11-19 RTC in Eagle Bibliothek aufgenommen
    [DRILEGEND.CFG]
2015-11-20 CAD Design angepasst
    [GEhäuse.sldprt, Wordclock.SLDASM, Zwischenplatte.sldprt]
2015-11-27 Eagle Adafruit added
    [Wordclock.brd, Wordclock.sch]
2015-12-02 Eagle Fehler verbessert
    [Wordclock.brd, Wordclock.sch]
2015-12-04 Eagle Änderung
    [Wordclock.brd, Wordclock.sch]
2015-12-05 Eagel WS2812 added
    [Wordclock.brd, Wordclock.sch]
2015-12-07 WS2812 Layout versucht
    [Wordclock.brd, Wordclock.sch, Wordclocktest.brd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]
2015-12-09 Frontplatte in Inkscape erstellt
    [Wordclock.SLDASM, Wordclocktest.sch, Zwischenplatte.sldprt]
2015-12-09 CAD Frontplattendesign eingefügt
    [Frontplatte.SLDASM, Frontplatte.SLDPRT, Wordclock.SLDASM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]
2015-12-12 Wordclock Matrix gelayoutet
    Matrix alle Zeilen einzeln gelautet, Zeilen sind noch nicht verbunden
    [Wordclock.brd, Wordclock.sch, WordclockKopie.brd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]
2015-12-15 Eagle Layout geroutet
    [Wordclock.SLDASM, Wordclock.brd, Wordclock.sch]
2015-12-16 Eagle VDD gelayoutet und vieles mehr
    [Wordclock.brd, Wordclock.sch]
2015-12-17 layout der leds
    [Wordclock.brd, Wordclock.sch]
2015-12-19 Eagle untere hälfte der Platine und LED Layout fertig
    [Wordclock.brd, Wordclock.sch]
2015-12-19 Layout fertig
    [Wordclock.brd, Wordclock.sch]
2015-12-19 Dateien aufgeräumt und in Eagle Schrift hinzugefügt
    [Platine.SLDASM, QR Code.brd, User Library-1206(3216M) Res.x_t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]
2015-12-20 Schutzwiderstand für WS2812 added
    [Wordclock.brd, Wordclock.sch]
2015-12-23 CAD Platine erstellt und Bauteile eingefügt
    [0204_5_0204_5.sldprt, 10221.x_t, 21643.x_t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]
2015-12-23 Platine in CAD komplett mit Bauteilen
    [DIP28 inkl Sockel.SLDASM, DIP8.SLDPRT, HC49.SLDPRT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]
2015-12-23 Bohrung in Zwischenplatte hinzugefügt
    Bohrung in Zwischenplatte hinzugefügt um Platine mit Gehäuse und
    Zwischenplatte zu verbinden.
    [Frontplatte.SLDASM, Frontplatte.SLDPRT, GEhäuse.sldprt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]
2015-12-24 Beginn des Gehäuses und anpassen der zwischenplatte
    [Innensechskant M3x10 Meusburger.SLDPRT, Meusburger-E1220_3X10.x_t, Platine.SLDASM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]
2015-12-24 Befestigung Platine und Gehäuse
    außerdem Bilder gemacht
    [Abstandshalter Plastik.SLDPRT, Drei Beilagscheiben.SLDASM, Frontplatte.SLDASM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]
2015-12-27 Ausschnitt USB Stecker
    [GEhäuse.sldprt, Wordclock.SLDASM, Zwischenplatte.sldprt]
2015-12-27 Ausschnitte in Rückseite hinzugefügt
    [GEhäuse.sldprt, Wordclock.SLDASM, Zwischenplatte.sldprt]
2015-12-27 SCL/SDA Pullups hinzugefügt
    ACHTUNG!!! Diese Pullups sind auf der ersten Platine noch nicht
    enthalten
    [GEhäuse.sldprt, Wordclock.SLDASM, Wordclock.brd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]
2015-12-28 weiter Bauteilewerte angepasst
    [Wordclock.brd, Wordclock.sch]
2015-12-28 Eagle: Pullups I2C geroutet und Befestigungslöcher auf 3,2 angepasst
    Bohrergröße für Platine nun M3 fein nach Tabelle unter
    https://de.wikipedia.org/wiki/Metrisches_ISO-Gewinde
    Pullup_SCL und Pullup_SDA nun im Layout eingefügt
    [Wordclock.brd, Wordclock.sch]
2015-12-29 Bauteilliste exportiert
    [Stückliste Wordclock.csv, Wordclock.SLDASM, Wordclock.brd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]
2015-12-30 WS2812 auf Ausführung mit Schwarzer Vorderseite geändert
    [WS2812.SLDPRT, Wordclock.SLDASM]
2015-12-30 Bestellung bei Reichelt und WS2812 und Kondensator auf 15p geändert
    Bestellung bei Reichelt und WS2812 und Wert des Kondensator am AVR
    Quarz auf 15p geändert
    [Wordclock.brd, Wordclock.sch]
2016-01-08 Platine in CAD aktualisiert und Bohrungsmaße gespeichert
    Die Platine im CAD Programm wurde aktualisiert und es wurde eine
    Zeichnung zum erstellen der Bohrungen in der Platine angefertigt.
    [HC49_S_32_768MHZ.sldprt, Platine.SLDASM, Wordclock.SLDASM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]
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2016-01-08 Zwischenplatte in Illustrator für LaserCutter vorbereitet
    [Zwischenplatte.DXF]
2016-01-08 Zwischenplatte und Box für Lasercutter vorbereitet
    [Zwischenplatte.DXF]
2016-01-13 Lötschablone erstellt
    [Schablone Lötpaste.dxf, Zwischenplatte.DXF]
2016-01-15 CAD Distanzhülse eingebaut
    [Distanzhülse M3.SLDPRT, GEhäuse.sldprt, Wordclock.SLDASM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]
2016-01-18 Versuch AVR Studio
    [Wordclock.sch]
2016-01-18 Projektpräsentation erstellt
    [Wordclock.SLDASM]
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

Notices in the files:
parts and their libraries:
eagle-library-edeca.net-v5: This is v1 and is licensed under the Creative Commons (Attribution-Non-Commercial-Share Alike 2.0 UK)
